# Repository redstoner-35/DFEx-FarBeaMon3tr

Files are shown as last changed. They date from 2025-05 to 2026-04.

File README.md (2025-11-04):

powered by 35's Embedded Systems Inc. An Open-Source High Power FlashLight Solution                                                                                                                        

### 概述

欢迎来到由Redstoner_35所开发的新一代高功率全恒流远射/远泛手电**DFEX-FarBeaMon3tr**的完整设计开源仓库。DFEX-FarBeaMon3tr是基于XTR HyperBoost超高能效升压恒流驱动所实现的大型手电参考设计，该手电采用全铝合金CNC设计，内置6节21700的可换电池电池架。电池架具备保护板、主动均衡和被动均衡确保使用安全，同时利用定制版本的充电系统支持高达140W输入功率的快速充电，缩短了极亮完毕后的补能时间。利用了全新的高功率双相交错升压恒流平台，该手电可实现高达760W的极亮功率。并且通过夜巡者7175灯珠得到72000lm 0.8M CD(或者使用定制的FL7018I灯珠得到75000LM 120万CD)的出光性能。同时无风条件下可实现6000-7000lm的恒流持续常亮，或在配合高功率风扇手柄的条件下以18000LM的亮度恒流持续常亮，直到电池电量用尽。该手电方案基于本人完全自主设计的硬件平台和软件系统，故具有超越市面上量产产品的极致性能以及稳定性，同时借助定制的软件系统可以实现市面上量产手电无法企及的高度可定制性和丰富功能。

### 复刻成本

该手电方案的从0开始复刻的成本极高。因此作者本人开源该项目的初衷是提供一个具有用户可换电池+大功率快充+全恒流超高能效驱动的手电设计参考作为抛砖引玉，期望行业上可以基于该设计作为范本诞生更多具有设计感和独创性的大型手电设计。如果您一定需要尝试复刻，那1PCS大致的复刻成本如下：

+ 机械部件部分：大约3000至4000元
+ 光学系统部分（包括反射器、玻璃等）：约2000元
+ 电子电路部分（包含驱动和电池架所有PCB和元器件）：约4000元
+ LED部分（包含定制灯珠打样和配套铜基板等）：7000元

### 性能数据

+ 远泛版本（使用6颗夜巡者7175灯珠）：极限72000LM光通量，约80万坎德拉
+ PRO9高功率高密度远泛版本（使用自己的DFEx-SuperLED+ FL7018I灯珠）极限75000LM光通量，约120万坎德拉
+ 远射版本（使用自己的DFEx-SuperLED+ FV7212D）极限43000LM光通量，约160万坎德拉

*注：以上测量数据由本人使用参考手电按照ANSI NEMA/FL1标准测试得到。受限于复刻时的物料使用，性能可能达不到标称值*

### 成品手电图片和尺寸

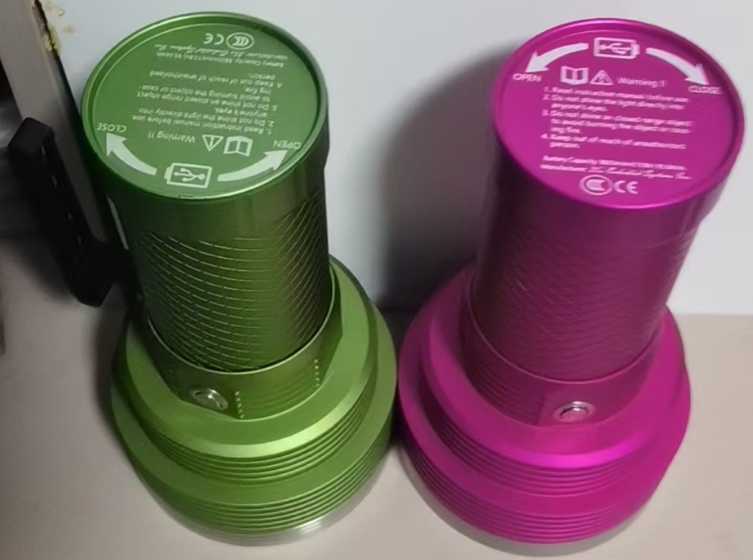
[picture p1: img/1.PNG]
俯视图

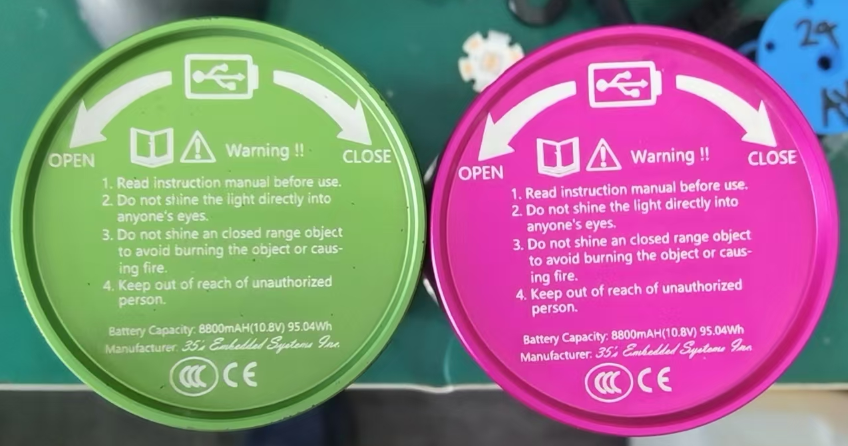
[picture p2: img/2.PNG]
侧视图


这个手电属于尺寸比较大，重量较高的类型。因此建议复刻时考虑清楚您是否能接受这种重型专业手电的重量和体积。详细的重量和体积数据如下：

+ 手电头径：125mm
+ 手电总长度：225mm
+ 电池仓直径：70mm
+ 手电总重量：2250克（包含6节比克INR21700-45D 4.5AH全极耳21700动力电芯）

同时该手电的侧面具备专用固定孔位用于兼容风扇手柄总成DLC。加上风扇手柄总成DLC后的外观图如下所示：

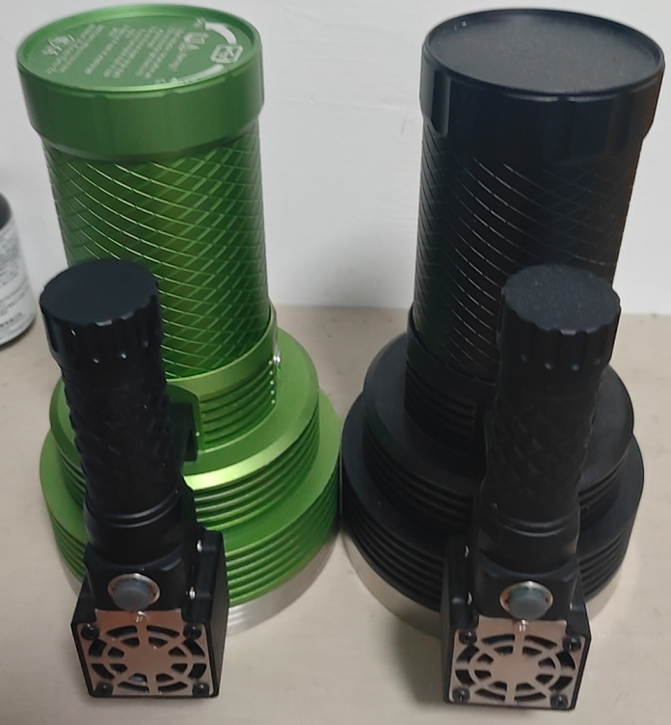
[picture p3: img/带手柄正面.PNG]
带手柄正面

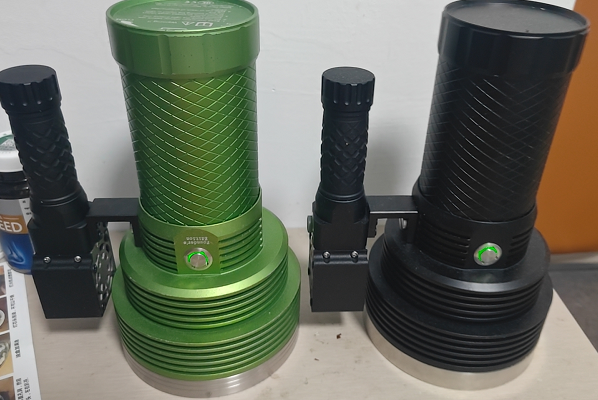
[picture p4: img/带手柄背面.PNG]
带手柄背面


此时手电的重量将会由原来的2250克增加至2535克（约2.5公斤）对于大部分人来说仍然能接受。不过考虑到复刻的极高成本，还是建议用户审慎考虑是否能接受一款重达5斤的重型手电。

### 续航数据

#### 极亮、高亮和中高亮以及中亮的续航

使用6节比克INR21700-45D（共计95Wh）在25度室温，0.3M/s风速模拟室外微风 **（测试时高功率风扇手柄DLC还未做好，此时使用的是外置USB小风扇）** 的情况下，极亮、高亮中高亮以及中亮的续航数据可以参考如下内容：

+ 极亮：30秒(满功率)+41分钟(极亮降档后外壳58度恒温恒亮)+15分钟(降档至高亮外壳50度恒温恒亮)+32.5分钟（逐步降档至极低亮）总共90分钟 *约1.5小时*
+ 高亮：11分钟（满功率）+33分钟（逐步降档至中亮开始恒温50度常亮）+ 33分钟（中亮持续恒温恒亮）+34.5分钟（逐步降档至极低亮）总共106.5分钟 *约1.78小时*
+ 中高亮：84分钟（持续恒流常亮）+34分钟（逐步降档至极低亮）总共118分钟 *约1.96小时*
+ 中亮：172.5分钟（持续恒流常亮）30.5分钟（逐步降档至极低亮）总共203分钟 *约3.38小时*

曲线可以参考如下表：

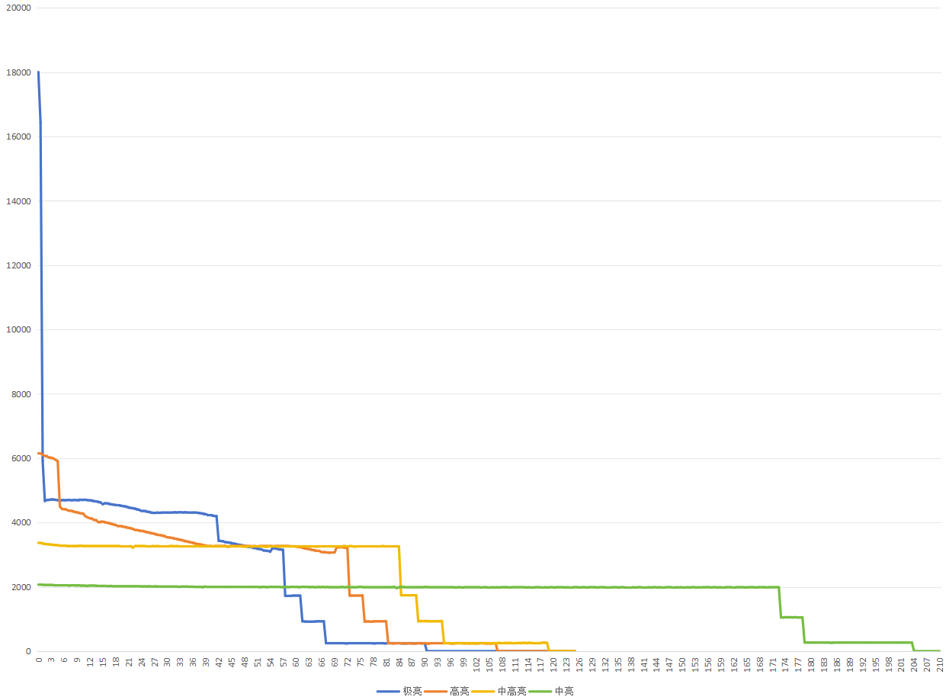
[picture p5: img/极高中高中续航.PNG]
续航表1


#### 低亮和极低亮的续航

使用6节比克INR21700-45D（共计95Wh）在25度室温，0.3M/s风速模拟室外微风的情况下，低亮和极低亮的续航如下：

+ 低亮：343.5分钟（低亮常亮）+27分钟（降档至极低亮）总共6.175小时
+ 极低亮：1419分钟（23.65小时）

曲线可以参考如下表：

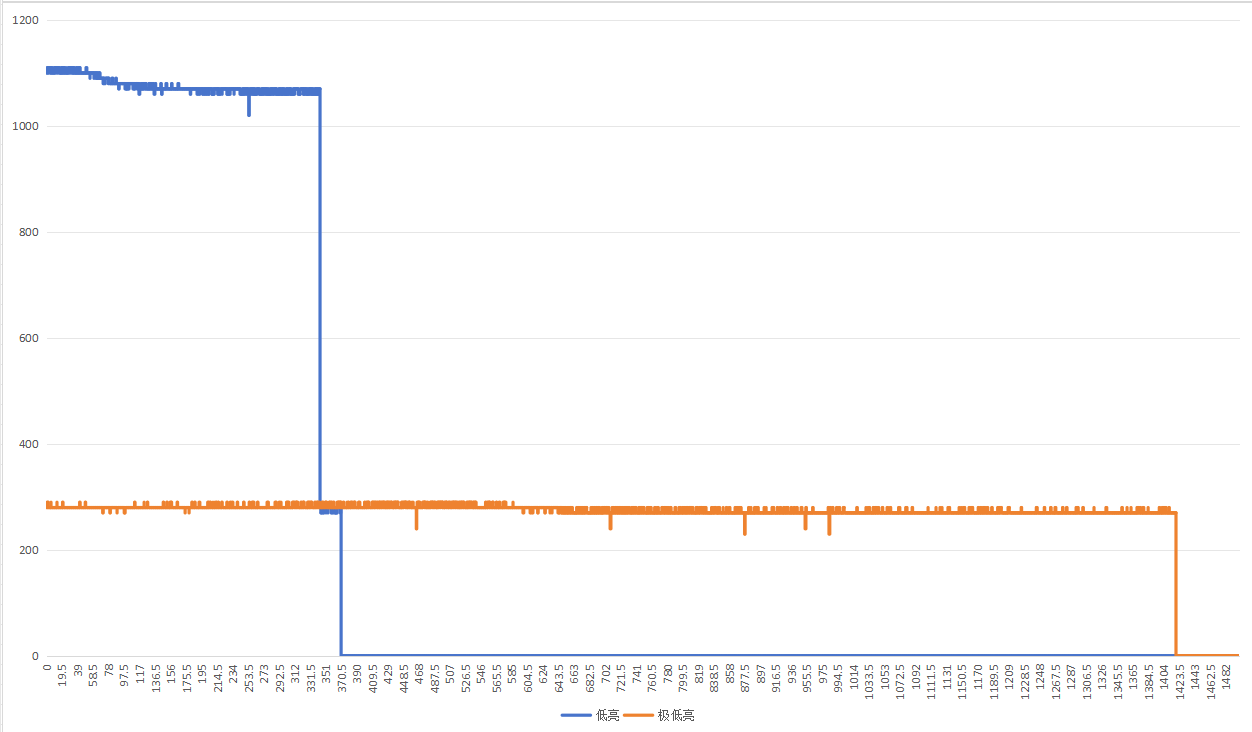
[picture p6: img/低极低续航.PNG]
续航表2


#### 月光挡位和超级省电挡位的续航

使用6节比克INR21700-45D（共计95Wh）在25度室温，0.3M/s风速模拟室外微风的情况下，月光和超级省电挡位续航数据如下：

+ 月光挡位（165LM）：续航大约90小时。
+ 超级省电挡位（2.5LM，运行至保护板彻底断电）：1760小时，约73.3天

#### 极亮温控降档曲线

实测的极亮温控降档曲线如下所示。测试条件和续航测试一致，照度测试系统采用1S采样周期，测试结果如下：

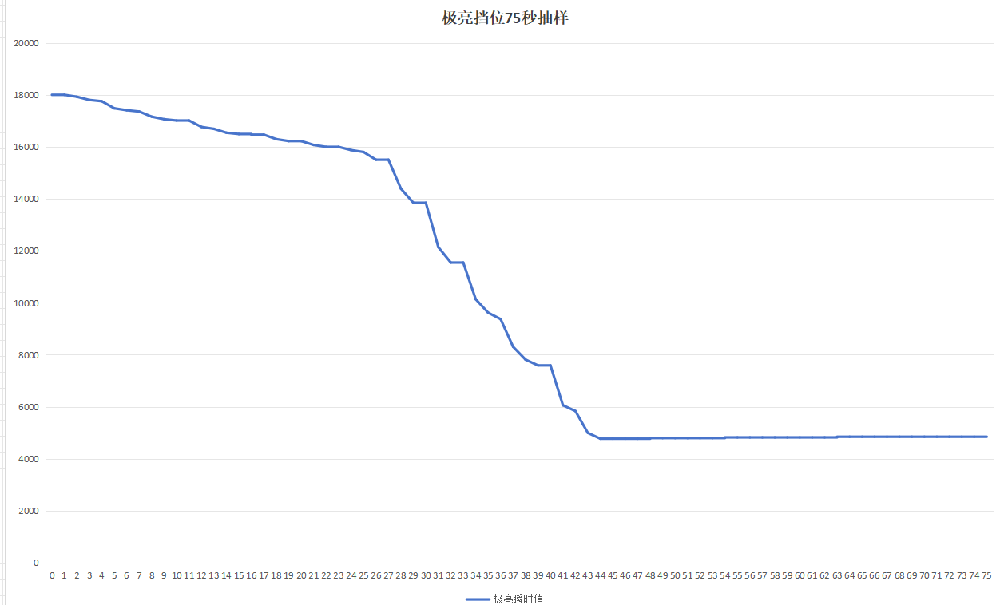
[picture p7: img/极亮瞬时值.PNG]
极亮数据


使用36A极亮的高功率版本程序搭配6颗N7-175HE时，极亮功率可达760W并在此条件下恒流顶满最大功率坚持30秒。30秒后温控介入开始迅速减低输出功率并进入续航曲线的恒温恒亮阶段。对于如此大的极亮功率是一个很优秀的水平。**需要注意的是，LUX值的轻微下跌是由于外壳温度提升后灯珠结温上升导致光效降低导致。并非驱动无法实现恒流极亮。**

### 复刻时电池的选择

这个手电的电池在工作过程中需要承受巨大的电流。对于使用7175灯珠和36A电流配置的远泛版本，电池电流可能会高达80A，也就是每节电池需要提供40A的电流。如此巨大的电流基本不允许使用非全极耳的动力电芯。经过测试，我建议使用如下的电芯：

+ 天鹏能源50XG：目前最强的5000容量全极耳电芯。正A品价格22-30之间。不管是充电还是放电水平都属于业界T0梯队，强烈推荐！ **但是需要注意不要买到早期测试报废品（正A品的电池皮是灰色的）测试报废品会漏电导致电池架工作异常！**
+ 瑞恩RS50：5000挡位全极耳电芯。A品价格大概20-25一节。该电芯充放电性能较为均衡属于兼顾容量和性能的动力电芯，在50XG出来后倒是不推荐了。
+ 比克INA21700-45D：高容量动力电芯。价格较贵约27一节，4500mA容量可以换来较长的续航。购买时建议选择A03高容品并特挑2.9毫欧内阻。
+ 新能安JP40：中等容量动力电芯，优势是货源数量极大因此价格很便宜，全新约15-20元一节。**需要注意的是，由于电池架的结构设计，拆机电芯因为电极表面不平整会导致电池架接触不良出现极亮瞬间保护等问题。因此不建议购买拆机的电芯。**
+ 三杰40Y：2025年三杰新推出的全极耳电芯，零售大概在20-25一节。性能相比前两者比较差，不推到700W以上问题不大。

可以用但是因为容易买到不好品质而不推荐的电芯：

+ 亿纬40PL：放电能力等于新能安JP40但是容易买到刮码降级B品，B品一致性差而且存在漏电问题，会导致手电工作异常。
+ 亿纬50PL：目前最强放电能力，且具有5000mAh的高容量。但是这款电芯目前产能和良率存在问题导致正A品一票难求。市场上目前只有降级刮码B品，一致性差而且存在单体漏电可能，会导致手电异常。

**注意：因为该手电极高的充放电倍率，绝对不要使用容量型或者半动力型电芯，是真的会爆炸！非要强行使用炸了后果自负，作者不承担任何责任！**

### 风扇手柄DLC的说明

#### 风扇手柄参数简介

相比于最初的版本，目前的工程文件已经包含了基于[东东海F1A的风扇手柄套件](https://item.taobao.com/item.htm?id=962803427853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)所实现的风扇手柄DLC。该风扇手柄通过专用的铝合金固定件连接至手电本体，具有极高的强度。风扇手柄外观如下图所示：

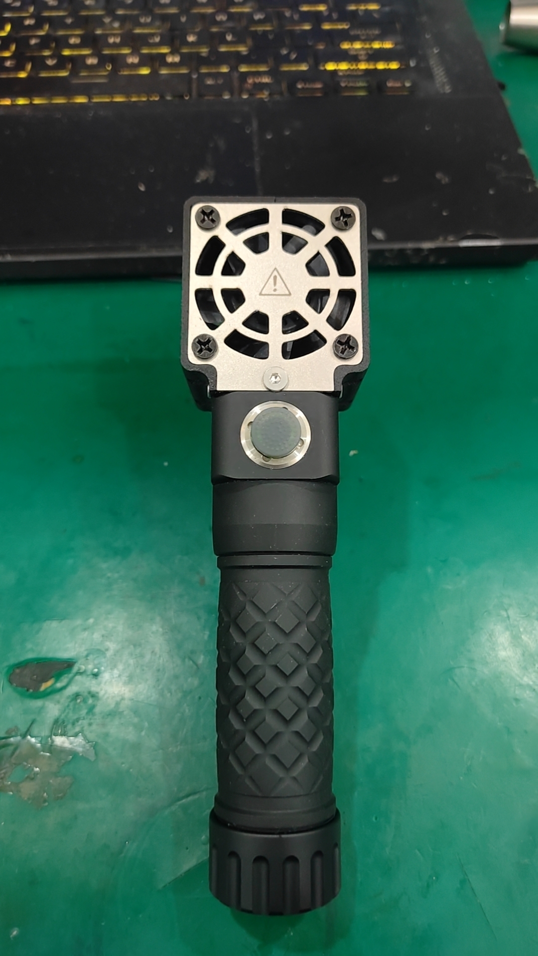
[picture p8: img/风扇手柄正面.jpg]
风扇手柄正面

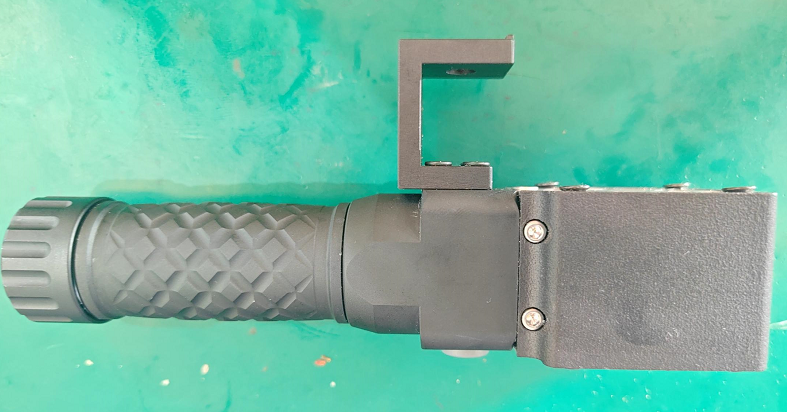
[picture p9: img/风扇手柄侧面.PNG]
风扇手柄侧面


该风扇手柄DLC基于自主开发的单锂升压12V风扇专用驱动以及单锂双向充电板，手柄样机所标配的风扇为建准的XF40281BX-Q035-S9H。转速高达34000RPM可以实现2万LM常亮不降档。同时该风扇手柄的电池仓为免拆电池充电设计，旋下电池仓即可露出内置的双向USB-TypeC充电接口：

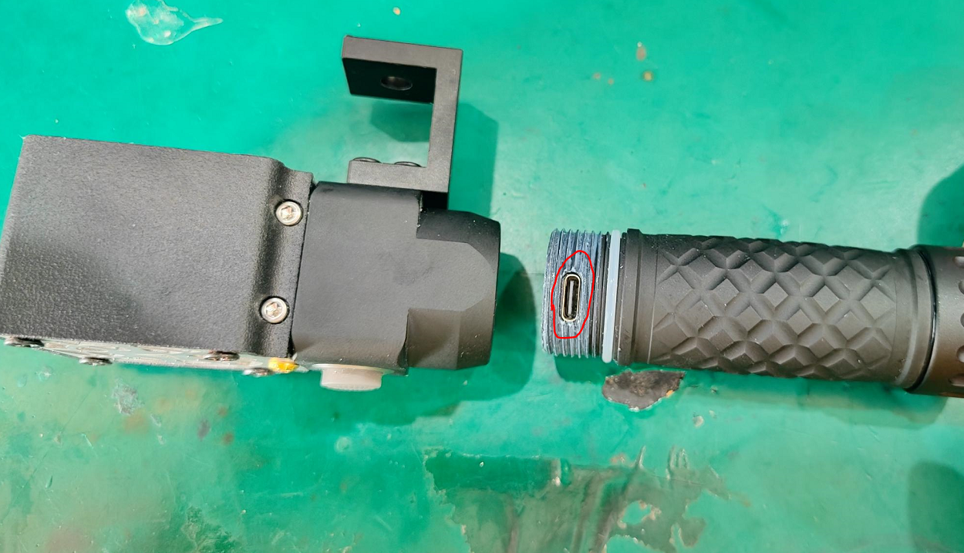
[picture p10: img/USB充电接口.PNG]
USB充电接口


该充电接口支持双向5V 2.4A充放电。最高12W的输入或输出功率。除了能给风扇手柄充电以外在应急情况下还可以反向为手机或其他设备应急充电。拆下手柄后即可看到手柄电池仓正面的充放指示灯：

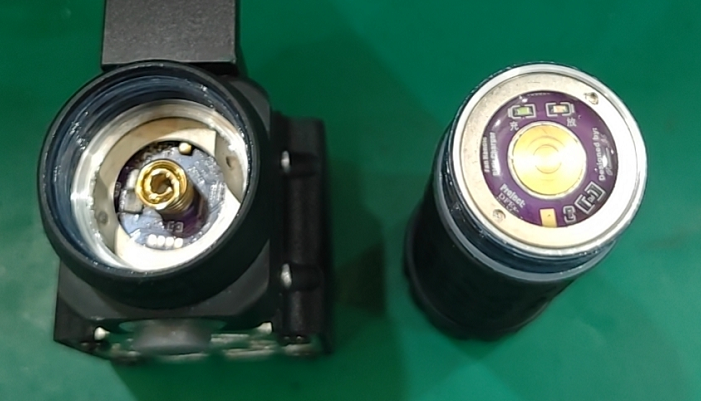
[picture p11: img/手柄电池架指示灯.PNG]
正面指示灯位置


手柄的电池仓一共包含两个指示灯，其中一个为放电和电池电量指示灯（图中紫色并且以放字标识的LED）以及一个充电状态指示灯（图中黄色以充字标识）负责指示电池的充放电状态。当电池仓首次装入电池时，电量指示灯会1Hz慢闪四秒表示电池安装后系统处于激活锁定模式。此时C口不能对外放电，需要连接充电器充电后才可放电。这两个指示灯不会同时点亮，显示的逻辑如下：

+ 充电指示灯：正在充电时0.5Hz慢闪，充满后持续点亮
+ 放电和电量指示灯：正在放电且电量正常时常亮，正在放电且电量不足后1Hz慢闪（充电或者放电结束拔下线缆后，电量指示灯仍然会保持点亮或闪烁一段时间，用户无需理会。30秒后电量指示灯会自然熄灭）

该风扇手柄采用专门的操作逻辑设计，和手电的原始UI基本一致，操作逻辑请参考如下内容：

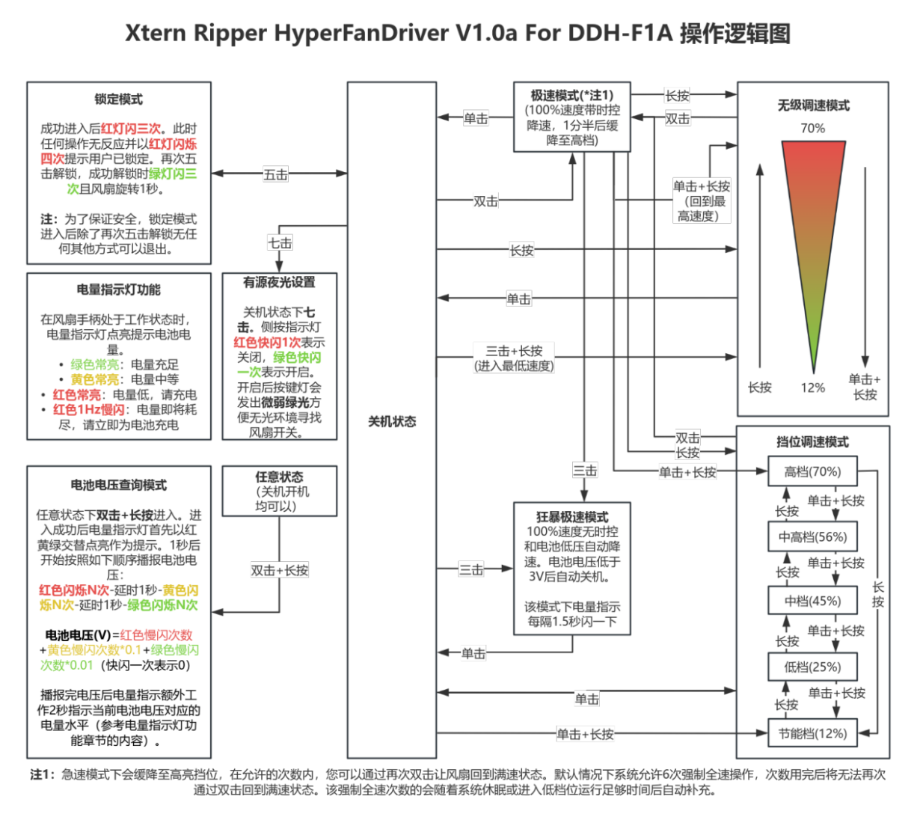
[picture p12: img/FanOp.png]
风扇手柄操作


#### 风扇手柄复刻说明

该风扇手柄复刻所需要的电路和机械部分已经在工程文件中体现，用户可以根据需要自行准备物料并复刻。对于部分未说明的物料请参考如下内容：

+ 风扇手柄半成品：该配件由东东海销售，可在[东东海淘宝店](https://item.taobao.com/item.htm?id=962803427853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)购买。
+ 风扇本体固定用粗牙螺丝：KB4*10规格，可在[固恒紧固件天猫店](https://detail.tmall.com/item.htm?id=610787499293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)购买.
+ 风扇固定装饰外壳和手柄壳料的固定螺丝：定制M3*6头径4.5非标内六角螺丝，可在[深奥普淘宝店](https://item.taobao.com/item.htm?id=770645615127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)购买
+ 4028暴力风扇：作者推荐使用建准的XF40281BX-Q035-S9H超高速暴力风扇获得足够的风量。该风扇可在[小红散热风扇](https://item.taobao.com/item.htm?id=959825954576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)淘宝店购买。

对于其余的机械部分物料，则参考如下说明：

+ 正背面风扇网罩不锈钢片：参考机械部分的[3D模型](/%E6%9C%BA%E6%A2%B0/%E9%A3%8E%E6%89%87%E6%89%8B%E6%9F%84%E5%A4%96%E6%A1%86/Step/40%E9%A3%8E%E6%89%87%E4%B8%8D%E9%94%88%E9%92%A2%E5%A4%B9%E7%89%87-%E6%94%B9%E7%89%88.STEP)找不锈钢加工厂进行处理。使用1mm 304不锈钢片激光切割后去毛刺抛光，并喷砂处理。
+ 风扇和手柄之间的固定壳：参考机械部分的[外部固定壳模型](/%E6%9C%BA%E6%A2%B0/%E9%A3%8E%E6%89%87%E6%89%8B%E6%9F%84%E5%A4%96%E6%A1%86/Step/40%E9%A3%8E%E6%89%87%E5%A4%96%E6%A1%8623%E6%97%A5.STEP)找3D打印商家进行处理。因该部件型面较为复杂因此建议选用PA6材质进行SLS激光烧结或MJF工艺等无需支撑的工艺制程进行3D打印。

电子部分的物料和具体打样文件（如PCB等）您可以参考PCB文件夹内相关的子目录并进行打样。

### 工程结构

该开源手电项目的工程分为三个文件夹，分别放置手电的电子、机械和固件部分的原始资料：

+ PCB：该文件夹放置手电所有功能模块的电路板文件
+ 固件：该文件夹放置手电种各个功能模块所使用到的固件文件
+ 机械：该文件夹放置手电外壳、电池架等东西的机械建模文件

### 复刻的详细指导

因为该项目仍处于刚刚完成的状态，相关文档的编写仍在进行中。对于需要注意的部分以及供应商链接您可以参考每个子文件夹内的注意事项文档。对于您在复刻中不明白的部分，您可使用Github issue。

----------------------------------------------------------------------------------------------------------------------------------
© redstoner_35 @ 35's Embedded Systems Inc.  2025

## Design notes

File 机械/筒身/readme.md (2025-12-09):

### 关于文件格式的说明

这里所提供的3D文件格式为UG NX的部件格式。为了方便复刻联系五金供应商进行报价故作者还提供了每个部件所对应的Step文件。**需要特别注意的是，Step文件仅供报价参考，不得作为最终加工的特征基准！**对于最终的加工尺寸基准，请按照UG NX的原文件进行处理。

### 关于材料的选择

该手电的外壳在设计时是按照**6061T6铝合金**进行设计的。考虑到导热性、材料硬度等因素，不建议使用其他材料进行制造。

### 关于文件内尺寸的说明

需要注意的是这里的3D文件内的尺寸并未按照配合关系进行完全的优化。因此加工时一定要和老板沟通清楚相关螺纹以及五金件的配合参数。否则加工出来的将会是废品！作者建议所有的五金件在加工时均由同一家供应商进行，并且配合件的公差参数由他们按照自身设备的匹配情况进行把控，这样可以避免多家供应商的配合尺寸基准不一致导致最后无法装配的问题。

### 关于驱动压环螺纹的说明

驱动压环的原始资料文件中的螺纹和实际参数并不匹配。实际加工时建议按照如下参数加工：

#### 驱动压环外螺纹参数

+ 螺距：1.0mm
+ 螺纹类型：公制M54
+ 螺纹大径：54mm
+ 螺纹小径：52.6mm

对于筒身外螺纹的配合参数，为了确保驱动压环能够顺畅拧入且不会松动，可以按照单边0.2至0.3mm的间隙预留，不建议间隙过小。

### 密封圈选配说明

为了使手电达到应有的防水性能，您需要在筒头、玻璃、筒身等位置预留的密封圈槽位置正确安装密封圈方可达到防水性能。该手电对于密封圈的品牌没有要求，只要材质和尺寸正确即可。密封圈数据请参考如下：

+ 玻璃压环密封圈（位于玻璃和不锈钢玻璃压环之间）：外径120mm，线经2.0mm
+ 筒头-玻璃压环密封圈（位于筒头，负责实现玻璃压环和筒身之间的密封）：外径110mm，线经1.5mm
+ 尾盖密封圈（实现电池筒身和尾盖之间的密封）：外径43.7mm，线经1.8mm *实际安装在筒身上拉伸之后尺寸正好合适*
+ 筒头-筒身密封圈（装载电池筒前部实现筒头和筒身之间的密封）：外径41.2mm 线经1.8mm *实际安装在筒身上拉伸之后尺寸正好合适* 

**所有密封圈材质均为硅胶，白硅胶和红硅胶均可。请勿使用橡胶材质如氟橡胶、EPDM，否则密封圈可能会因过大应力而破损**

### 二次加工的说明

为了实现正确的导电连接，因此筒头部分在阳极氧化结束后需要再次上级进行二次加工去除氧化层。去除的数据请参考如下：

#### 基板安装位去氧化

筒头的基板位置在一次加工时请按照3D图的尺寸进行加工。加工氧化好后的效果如图：
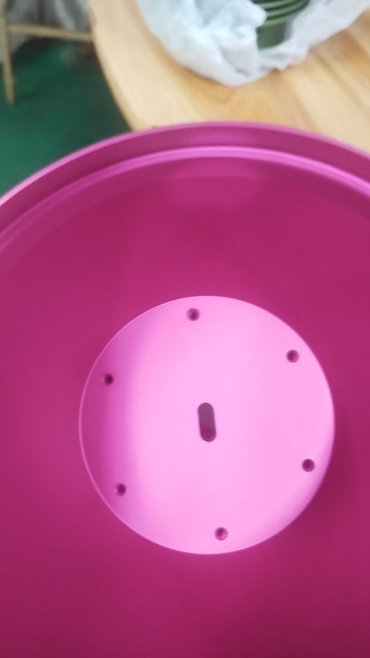
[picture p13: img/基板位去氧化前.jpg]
筒头去氧化前


去氧化时请使用车床对整个基板安装位光一刀，深度0.1mm即可，光一刀后尺寸正好合适。

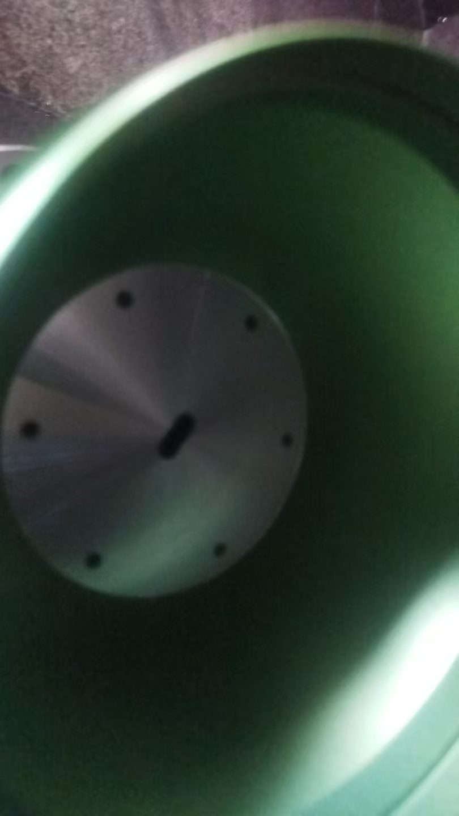
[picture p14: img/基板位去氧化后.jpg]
筒头去氧化后


#### 驱动安装位去氧化

驱动安装位置的去氧化操作则较为复杂。驱动压环位置的螺纹，驱动PCB所在的台阶以及电池仓前盖所对应的压环均要去氧化。因此加工协商过程中需要让老板留好余量。去氧化前的效果如下：

基板位去氧化前

去氧化后效果如下：

基板位去氧化后

----------------------------------------------------------------------------------------------------------------------------------
© redstoner_35 @ 35's Embedded Systems Inc.  2025

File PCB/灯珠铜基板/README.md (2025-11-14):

### 铜基板配置说明

这个手电默认的铜基板配置是6颗7070或者7272尺寸的LED。对于LED的电压配置则支持3种类型的灯珠。对于目前基板已有的3种配置请参考下面的内容：

### 6V灯珠

第1种默认的配置是6V灯珠以3串2并的形式连接到驱动。三串6V灯珠提供了15-22V的宽范围Vf以适配驱动的输出参数。对于6V灯珠配置，为了确保安全使用应确保灯珠至少能承受16A电流，否则灯珠会烧毁。6V基板配置采用了4.0mm热焊盘的行业标准XHP70的灯珠焊盘设计因此可以兼容XHP70.3等灯珠。

### 9V灯珠

第2种默认的配置则是9V灯珠以2串3并的形式连接到驱动，这种形式适用于9核心的倒装高光效灯珠用于远泛光型的装机。对于9V灯珠配置，为了确保安全使用应确保灯珠至少能承受12A电流，否则灯珠会烧毁。
需要特别注意的是，9V基板配置使用了兼容达立半导体A6-N60灯珠（夜巡者老王7175）的焊盘设计。该焊盘加大了热焊盘位置以增强导热能力适配大核心面积。**如果强行焊接行业标准的7070灯珠（热焊盘0.2mm）会导致灯珠短路而无法使用！！！**

### 3V灯珠（2025年11月更新）

第三种默认配置针对改进款的7070 NBT160.3灯珠。采用3V灯珠6串全串联设计。这种设计彻底解决了并联灯珠带来的可能不均流的问题。为了确保核心散热完全，3V基板的设计采用了加大热焊盘位置的非标准7070封装以增强导热能力适配大核心面积。**如果强行焊接行业标准的7070灯珠（热焊盘4.0mm）会导致灯珠短路而无法使用！！！** 文件中提供了单板的PCB源文件，需要和基板厂协商让他们负责代客拼板才能生产。

### 基板打样参数

该手电对基板的配置有特殊要求，因此打样时需要联系专职进行铜基板打样的厂家（例如深圳天华电子有限公司等）进行打样。打样的参数要求如下所示：

+ 成品板厚：2.5mm
+ 线路层铜厚：4Oz
+ 焊盘喷镀：2U沉金
+ 特殊工艺要求：六个固定孔需要做阶梯孔。阶梯孔截面宽度6.2mm，深度1.2mm。
+ 分板方式：V-Cut分板

本文件提供的成品拼板文件已经默认拼好两种不同配置的基板，并附加上工艺边和V-Cut线，可以支持直接打样无需进行二次处理。对于该铜基板的打样参考价格大概是1500CNY打样费可以做3个set（一个set包含6V配置和9V配置的铜基板各一块），一共可以得到6个铜基板。

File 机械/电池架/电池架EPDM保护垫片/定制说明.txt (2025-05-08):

所提供的图纸为1：1尺寸的DWG格式无需缩放。请按照如下参数裁切：

+ 材料厚度：1mm
+ 材料材质：EPDM(三元乙丙橡胶)

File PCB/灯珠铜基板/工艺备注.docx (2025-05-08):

该铜基板需要做台阶孔。台阶孔截面图和参数如下：

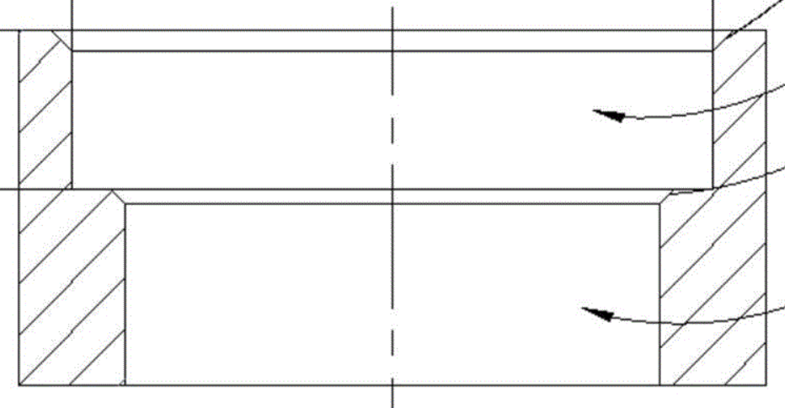
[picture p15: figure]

总深度

台阶深度

台阶部分深度：1.2mm

孔总深度：2.5mm(钻透整个基板)

台阶孔部分的外形尺寸，由文件“铜基板拼板_Mechanical_6.gbr”描述，其余外形和台阶孔非台阶部分（见截面图红色箭头标注）的尺寸由文件“铜基板拼板_Keep-out.gbr”描述。

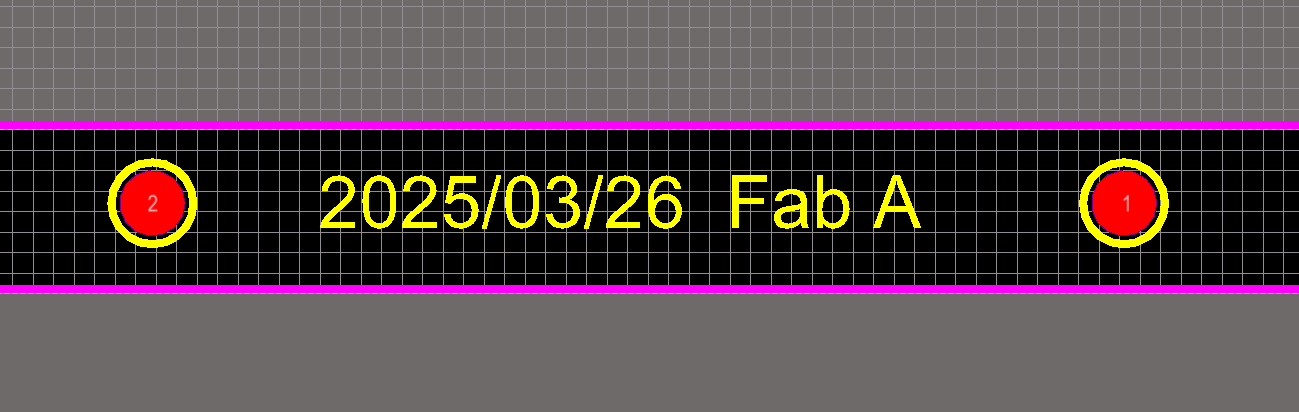
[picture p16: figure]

文件下方左右两侧的焊盘和外圈丝印圆圈为丝印印刷时对齐用的MARK标记。请生产员工在生产时利用此标记，尽量确保丝印对齐。

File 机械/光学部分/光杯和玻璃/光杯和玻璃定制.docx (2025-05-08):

# 玻璃定制

为了达到最大透光率以获得最高流明值输出，建议在淘宝上定制专门的双面镀膜AR钢化玻璃。对于玻璃的供应商我推荐淘宝的【首页-古洛玻璃-淘宝网 (https://shop33401513.taobao.com/)】按照所需的规格定制的报价是一片300RMB。玻璃的规格如下表所示：

玻璃基材 | 超白光学玻璃
镀膜类型 | 绿色AR减反射膜（需要注意的是膜层颜色，紫色和蓝色会导致出光色温贬低变得更绿）
镀膜方式 | 双面镀膜（透光率要求达到98%以上）
玻璃形状 | 圆形
玻璃直径 | 118mm
玻璃厚度 | 4mm
边缘工艺 | 磨砂+保护性倒角避免刮伤手

# 光杯定制

该手电的光杯为铝合金材质，采用五轴CNC+光面电镀。对于光杯的定制您可以联系1688的这两家供应商：宏广照明 (https://hghlightingcn.1688.com/page/index.html?spm=0.0.wp_pc_common_header_companyName_undefined.0) 以及 东莞旺达精密五金有限公司 (https://www.1688.com/factory/b2b-22144382303900e311.html) 并提供工程中的反光杯外形3D文件进行定制。定制费用大约在1000至2000人民币。每次定制通常会提供6-10个光杯供您测试出光效果。

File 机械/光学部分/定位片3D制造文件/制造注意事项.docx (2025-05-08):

本设计中的定位片制造可以采用3D打印。3D打印的话需要使用耐温大于160度，且颜色为白色的高热变形温度工程耗材，建议使用例如PA6-GF等高耐温工程耗材进行打印。作者所使用的打印参数如下：

耗材 | 拓竹原装白色PA6-GF玻纤增强耗材
打印机 | 拓竹X1C+AMS换料系统
热床温度 | 110℃
喷嘴温度 | 275℃
打印顺序 | 逐件打印
打印预设参数 | 0.08mm Extra Fine @ BBL X1C
填充率 | 100%

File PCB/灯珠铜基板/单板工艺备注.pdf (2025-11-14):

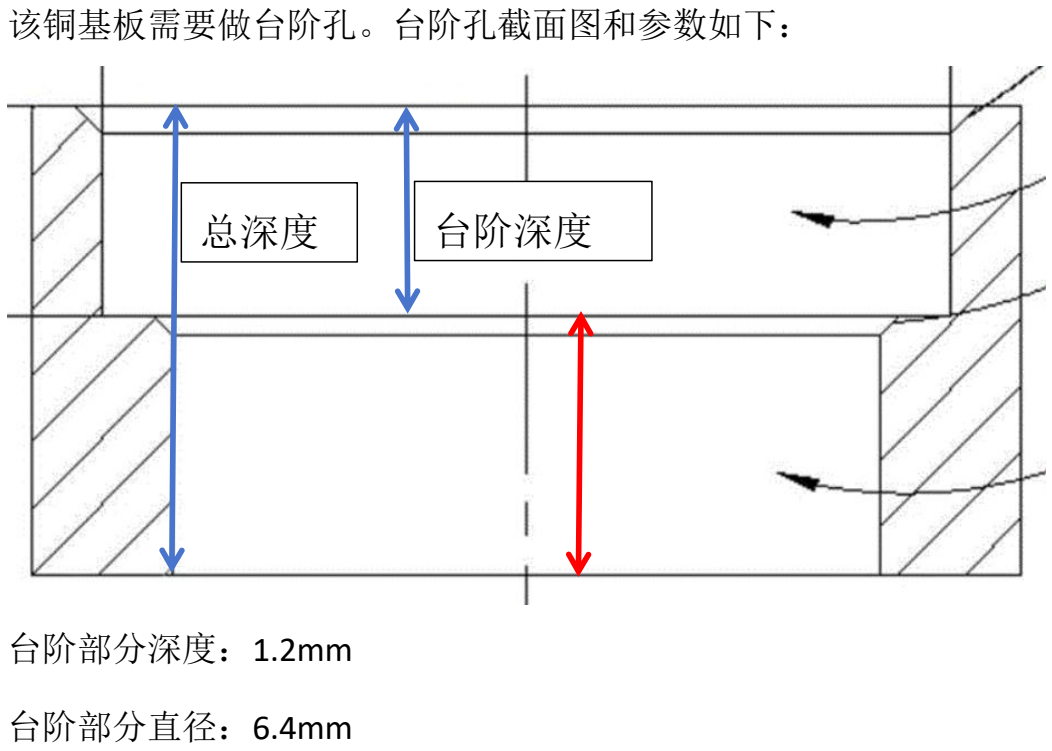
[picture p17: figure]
该铜基板需要做台阶孔。台阶孔截面图和参数如下：; 台阶部分深度：1.2mm; 台阶部分直径：6.4mm; 总深度; 台阶深度

孔总深度：2.5mm(钻透整个基板)

台阶孔部分的外形尺寸，由文件“铜基板拼板_Mechanical_1.gbr”描

述，其余外形和台阶孔非台阶部分（见截面图红色箭头标注）的尺寸

由文件“铜基板拼板_Keep-out.gbr”描述。

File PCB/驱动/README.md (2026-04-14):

powered by 35's Embedded Systems Inc. A Next generation FlashLight Driver Solution                                                                                                                        

### 概述

Xtern Ripper Lite-HyperBoost是用于DFEx-FarBeaMon3tr的超大功率且高能效的升压恒流驱动器。该驱动器基于全新的FlashLightOS Entry e-Switch固件。在保证了基本手电所需的客制化功能的前提下，删减了一些高阶特性并使用更便宜的中微8051平台。
该驱动器基于私有的X47安装方式，虽然该驱动器并不建议配合东东海47mm D8B外壳使用，但是通过对驱动仓进行车削仍然可以正常安装。该驱动器基于全新的HyperBoost双相交错升压恒流平台，通过使用两个以180度相位角交错运行的boost转换器实现在极大输出功率下仍能高能效运行。

### 性能数据

+ 支持的电池输入类型：3S三元锂电池组，持续放电能力应大于100安培。
+ 支持的LED灯珠类型：3V灯珠6串、6V灯珠3串、9V灯珠2串（支持垂直核心灯珠高Vf运行，设计时应保证极亮时灯珠Vf不超过22.0V）
+ 支持的LED电流：30mA至32或36.00A
+ 温度保护：55度PI环自适应外壳恒温（温控启动后驱动根据外壳散热能力和环境自动调整亮度达到最高可实现的亮度）+65度极亮cutoff+80度强制关机
+ 电池保护：具有欠压自动降档和关机保护以及过电压保护
+ 电池过载保护：具备输入自动限流保护

### 调试指引

该驱动不需要任何硬件上的调试和标定操作，只需要按照BOM表焊接上元器件并刷写固件即可使用。如果出现功能异常，您可以参考[驱动故障排除指引](/FAQ.docx)对驱动进行故障排除。**需要注意的是，示例工程中LTC3787芯片的两个输入限流电阻（R1和R2）原理图中采用的是1mR，如果您打算让驱动输出高于32A的电流，则建议在该电阻上面额外叠放焊接一个R015电阻组成0.938mR，将输入峰值电流限制解锁到53A。这样可以增大驱动的输入电流上限以增大恒流区间**

### 总体操作逻辑

该驱动具备无极调光和传统挡位模式两种逻辑供用户自由选择：
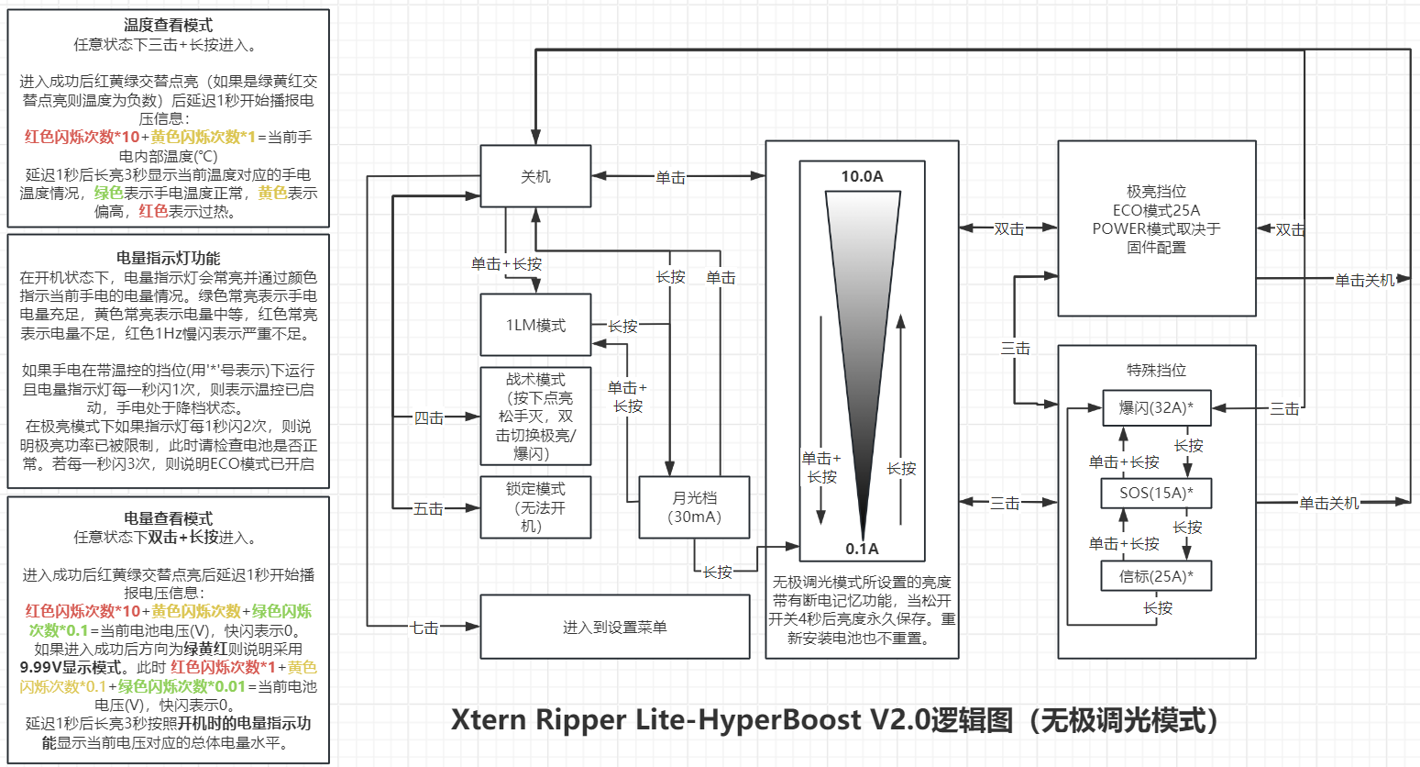
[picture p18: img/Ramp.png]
无极调光

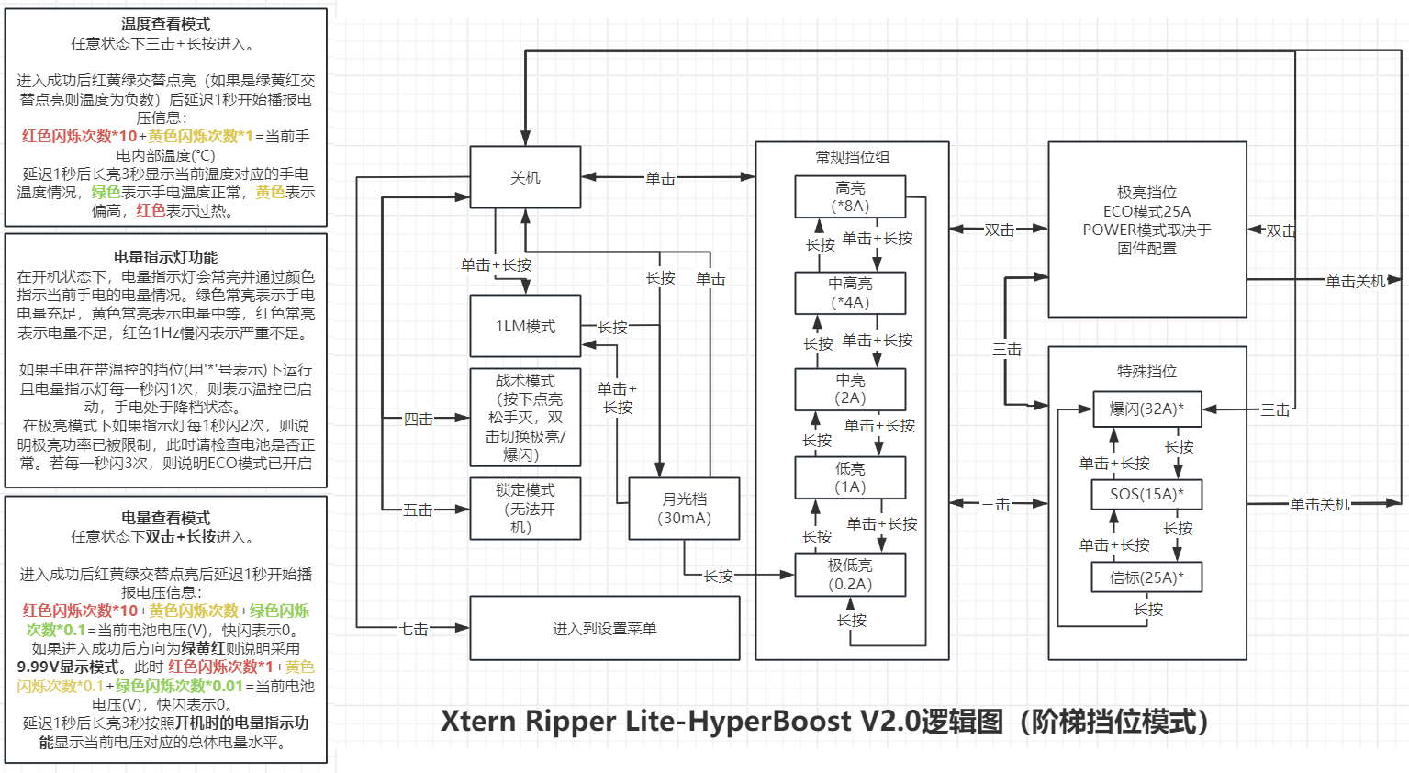
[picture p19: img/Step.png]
挡位模式


需要补充的是，图中的任意挡位均可以通过单击立即回到关闭状态。对于图中的部分未详尽解释的特殊逻辑，则可参考如下内容：

+ 固件编译时间戳查询：关机状态下8击进入。进入后手电主灯首先会点亮1秒，提示即将开始播报。然后手电将会按顺序播报固件编译的年份、月份，日期以及编译时的时间（精确到分钟）。首先手电会播报固件编译的具体日期，播报会分为三组数字，每组数字之间停顿2.5秒，同一组数字之间会有1.5秒的间隔方便用户区分。在播报完第一到第三组数字所表示的手电编译固件编译的年份、月份，日期之后，手电将会停顿4.5秒然后开始播报固件编译的具体时间（精确到分钟）。具体编译时间的播报会分为两组数字，每组数字之间停顿2.5秒，同一组数字之间会有1.5秒的间隔方便用户区分。**需要注意的是，播报启动后就无法中断，在版本信息播报过程中，手电将不响应任何操作，直到播报结束。** 详细的播报规则如下：
 
  - 第一组数字：指示固件编译的年份。其中主灯慢速闪烁N次表示非零的数字，如果快速闪烁一次，则表示该数据位为0。两位数字之间系统会停顿1.5秒。例如`慢闪2次-停顿1.5秒-慢闪5次`表示固件编译的年份为**25（2025年）**。
  - 第二组数字：指示固件编译的月份。其中主灯慢速闪烁N次表示非零的数字，如果快速闪烁一次，则表示该数据位为0。两位数字之间系统会停顿1.5秒。例如`快闪1次-停顿1.5秒-慢闪6次`表示固件编译的月份为**06（6月）**。
  - 第三组数字：指示固件编译的具体日期（精确到天）。其中主灯慢速闪烁N次表示非零的数字，如果快速闪烁一次，则表示该数据位为0。两位数字之间系统会停顿1.5秒。例如`慢闪2次-停顿1.5秒-慢闪3次`表示固件编译的具体日期为**23日**。
  - 第四组数字：以24小时制度指示固件编译时间的小时部分。其中主灯慢速闪烁N次表示非零的数字，如果快速闪烁一次，则表示该数据位为0。两位数字之间系统会停顿1.5秒。例如`慢闪1次-停顿1.5秒-慢闪3次`表示固件编译的时间（小时）为**13时（下午1点）**。
  - 第五组数字：指示固件编译时间的分钟部分。其中主灯慢速闪烁N次表示非零的数字，如果快速闪烁一次，则表示该数据位为0。两位数字之间系统会停顿1.5秒。例如`慢闪4次-停顿1.5秒-慢闪6次`表示固件编译的时间（分钟）为**46分**。

+ 1LM超级省电应急档：关机状态下单击+长按进入。进入该挡位后侧按的电量指示灯由原来的常亮改为每10秒按照正常运行过程中的电量情况短暂点亮一次以节约电力消耗（如果电池电量极低，则为红灯慢速闪烁）。该挡位的流明值取决于灯珠性能和V/I特性，通常在*2-3LM*之间。该挡位下长按可以进入正常的月光挡。**需要注意的是，该挡位仅用于应急，故没有任何电池电量保护机制。只要电池还有电力就会无限运行直到电池输入低于7.2V时驱动断电。若搭配第三方出品，没有过放保护的电池包将会导致电池因为过放而永久性损坏！使用官方电池包则不会有这个问题。**
+ 走夜路模式：关机状态下四击或六击进入（取决于设置菜单内设置项8的配置），手电此时开启约1.1A的低亮用于正常照明。此时若对向有行人或来车，则单击+长按后手电将会暂时熄灭以避免强光晃到对面，松手后手电将重新点亮。如果长按，手电将开启和爆闪挡位功能等同的全功率一键爆闪用以压制对面进行致盲操作，松手后手电恢复正常照明状态。
+ 战术模式：关机状态下四击或者六击开关（取决于设置菜单内设置项8的配置），手电主灯迅速频闪一次表示进入战术模式。默认情况下战术功能为按下开关手电以极亮运行，松开则熄灭。当手电进入战术模式后，侧部按键将会每2秒快闪一次指示当前处于战术模式，此时手电将会保持唤醒，直到无操作10分钟后自动进入休眠并退出战术模式。如果您需要主动退出战术模式，则您可再度六击开关，手电主灯频闪一次指示退出战术模式。与此同时，您可以通过双击侧按切换战术模式的功能，切换后的指示如下：
  
  - 一键极亮模式（默认）：此时手电按下开关极亮，松开灭，侧按指示灯每2秒闪1次，切换到该模式时手电的侧按会用红色快闪3次做提示。
  - 一键爆闪模式：此时手电按下开关进入爆闪，松开灭，侧按指示灯每2秒闪2次，切换到该模式时手电的侧按会用绿色快闪3次做提示。

+ 按键锁：关机状态下五击开关，手电主灯点亮0.5秒表示进入锁定模式，此时手电的绝大多数功能均被禁用以避免误触点亮引起事故。在锁定模式中，为了方便用户查询长时间放置的手电电量，用户可双击+长按进行电量查询操作（如下方电量查询模式功能所示）。若用户有紧急照明需求，则可以单击+长按打开紧急月光照明。打开月光照明后用户可单击关闭。同时该月光照明具有超时以及电量保护功能，若用户在开启后30秒内无操作或手电电池电量过低，则手电将会自动关机。在电池电量充足的条件下，您可以通过双击+长按并保持一直按住的方式持续照明。
+ 温度查询模式：手电任意状态下三击+长按进入。当进入电量查询模式后手电的颈部开关指示灯首先将会以红黄绿依次点亮的方式（**若手电当前处于极寒环境，手电本身温度低于0摄氏度时，先导提示将变为绿黄红的顺序**）作为先导提示，提示用户手电即将开始显示手电当前的内部温度。延迟1秒后手电将通过红色和黄色的指定次数的慢速闪烁（如果快速闪烁一次，则表示该数据位为0）提示用户当前的手电温度。在播报完当前手电的内部温度数值后，手电将会在延迟2秒后通过后续的长亮(或者慢闪)提示用户当前内部温度数值所对应的手电散热情况。对于温度显示的计算方式请参考如下内容：

  - 播报完毕后绿色常亮：当前手电散热良好
  - 播报完毕后黄色常亮：当前手电温度较高，请注意防止烫手
  - 播报完毕后红色常亮：当前手电温度极高，请及时为手电散热并且避免被烫伤   
  - 手电温度(℃)=红色闪烁次数x10+黄色闪烁次数，例如`红色慢闪4次-黄色快闪1次`表示当前手电的内部温度为40℃

+ 查询电量：手电任意状态下通过双击+长按进入。当进入电量查询模式后手电的颈部开关指示灯首先将会以红黄绿依次点亮的方式（**若电池电压低于10.00V，则系统将会切换到高精度显示模式以0.01V精度显示电量。此时先导提示将变为绿黄红的顺序**）作为先导提示，提示用户手电即将开始显示电池电压和电量。延迟1秒后手电将通过红色，黄色和绿色的指定次数的慢速闪烁（如果快速闪烁一次，则表示该数据位为0）提示用户当前的电池电压，播报完电池当前电压后，手电将会在延迟2秒后通过后续的长亮(或者慢闪)提示用户当前电池电压对应的总体电量水平（指示方式参考下文中驱动位于正常工作时的指示），对于电池具体电压播报的计算方式请参考如下内容：
  
  -  99.9V显示模式：红色闪烁次数x10+黄色闪烁次数+绿色闪烁次数x0.1=当前电池电压(V)，例如`红色慢闪1次-黄色快闪1次-绿色慢闪4次`表示电池电压为10x1+0+4x0.1=10.4V。
  -  9.99V高精度显示模式：红色闪烁次数+黄色闪烁次数x0.1+绿色闪烁次数x0.01=当前电池电压(V)，例如`红色慢闪8次-黄色慢闪1次-绿色慢闪3次`表示电池电压为8+1*0.1+3x0.01=8.13V。

+ 恢复出厂设置：在手电处于完全断电状态下（用户可以通过卸下电池并反复多次按下手电侧按直到手电没有任何反应）持续按住按钮并扭上电池包令手电通电。此时手电的侧部按键指示灯将会以黄色的持续高频率快闪提示用户已恢复出厂设置。用户松开按键后，手电将会在2秒后自动重启并进入正常工作状态。

### 正常工作时的电量指示

对于电压指示，驱动在工作状态会通过指示灯点亮的方式提示用户当前系统的电池电量。与此同时，在手电首次装入电池时，驱动还会通过一次持续2秒的点亮提示电池电量（指示方式和工作状态时相同）。对于手电当前的电量状态和对应的指示灯状态请参考如下内容：

  - 绿色常亮：电池电量充足
  - 黄色常亮：电池电量较为充足
  - 红色常亮：电池电量不足，请尽快为手电充电
  - 红色慢闪：电池电量严重不足，请立即为手电充电（此时手电的可用挡位和功能将会被限制）

与此同时，在手电正常工作时，驱动还会再某些特定事件发生时通过一定时间内的短时间熄灭次数的循环指示驱动发生的事件，详细的事件列表如下：

  + 每2秒瞬时熄灭1次：手电温度过高，驱动已启用温控限制手电输出功率避免过热
  + 每2秒瞬时熄灭2次：驱动检测到电池子系统无法为极亮提供足够的能量，为了避免电池过载，极亮功率已被限制。（出现此提示请务必更换性能更强的电池）
  + 每2秒瞬时熄灭3次：驱动当前开启了夏季模式，极亮输出功率和温度控制策略将会被限制到更保守的级别。

### 设置菜单系统

该手电内置一个用于配置手电功能和特效的设置系统。当用户在手电关机状态下七击开关后，手电将会进入该设置菜单的设置项选择界面，此时用户可以通过单击选择要设置的菜单项，选择完毕后单击+长按进入，如果要退出设置菜单，则长按开关3秒后自动退出。设置菜单的操作请参考如下图片：
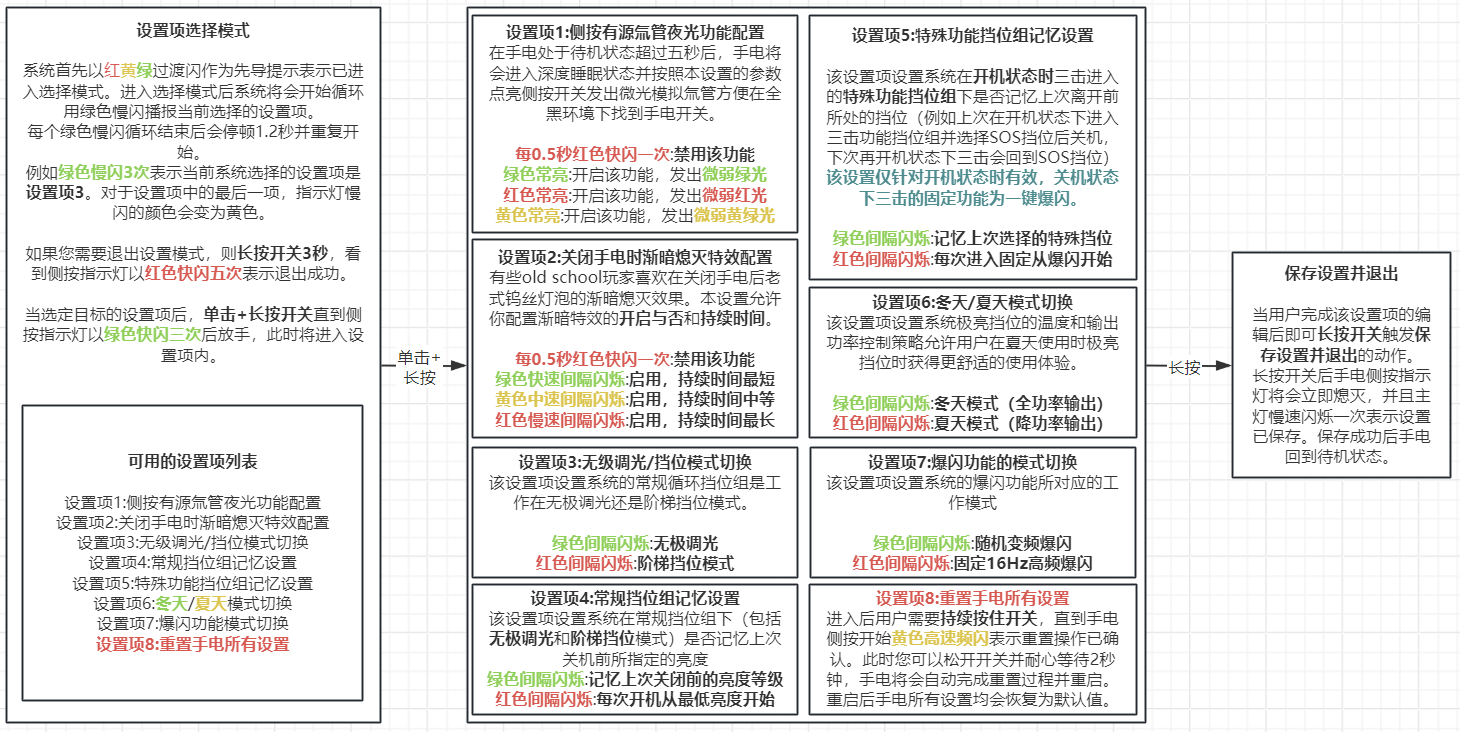
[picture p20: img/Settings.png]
设置菜单


*2025年12月26日热更新补充：*新增设置项8，允许用户根据自身使用习惯设置系统四击和6击的功能指配。选则该设置项时指示灯为8次闪烁。该设置项的功能如下：

+ 指示灯红色(默认模式)：此时战术模式被设置为高优先级，关机状态下四击进入战术模式，六击进入走夜路模式。
+ 指示灯绿色：此时走夜路模式被设置位高优先级，关机状态下四击进入走夜路模式，六击进入战术模式。

原本的设置项8（恢复出厂设置）则被变更为设置项9

**注：设置菜单的设置项选择界面和各个设置项均有超时功能，若一段时间没有操作，设置菜单将会超时并自动退出。该超时退出将会舍弃您在设置菜单内做的一切更改。**

### 错误指示系统

该驱动继承了Xtern Ripper PRO版本的特性，依然具备先进的状态监测系统。在驱动每次通电自检和正常运行过程中，固件会通过ADC采集驱动的运行状态并判断负载和驱动是否运行正常。并且在检测到异常时立即切断驱动输出以避免驱动和被驱动的灯珠损坏。

#### 运行时错误监测和错误ID汇报

在运行期间如果驱动检测到无法解决的致命问题则会进入保护模式避免驱动和灯珠损毁，并通过颈部侧按键的指示灯提示用户发生的错误类型。每个指示循环首先以红黄绿的颜色切换闪烁开始，然后通过紧跟着的红色慢闪次数指示错误ID号，慢闪结束后会停顿一会并重新开始循环，对于ID号所对应的错误描述请参考如下内容：

+ 闪烁1次(Fault_DCDCFailedToStart) 驱动在上电自检尝试启动DCDC时失败。检查驱动输出正极是否对外壳短路，DCDC芯片的使能信号和内部LDO输出电压是否正常。
+ 闪烁2次(Fault_DCDCShort) 驱动在运行时检测到输出短路。
+ 闪烁3次(Fault_InputOVP) 驱动检测到输入电压过高，请检测驱动的电池配置是否和使用的电池配套。
+ 闪烁4次(Fault_DCDCOpen) 驱动在运行时检测到输出空载，请检查LED是否损坏。
+ 闪烁5次(Fault_NTCFailed) 驱动在运行期间检测到测量驱动温度的热敏电阻出现异常，检查热敏电阻和测温部分的上拉电阻是否损坏。
+ 闪烁6次(Fault_OverHeat) 驱动检测到外壳温度过高，请等待手电冷却。冷却后故障会自动解除
+ 闪烁7次(Fault_DCDCPreChargeFailed) 驱动检测到实现CV环可控斜率预充的电路出现故障，请参照[故障排除文档](/FAQ.docx)进行硬件上的检查。
+ 闪烁8次(Fault_RampConfigError) 驱动在启动时检测到固件内存储的无极调光挡位数据被意外删除或丢失，此时系统无法正常工作。请检查固件编译设置内无极调光挡位相关的数据是否正常。

### 固件编译注意事项

#### 固件编译环境要求

该驱动的固件源代码使用了**Keil C51 V9.61a版本**的高级编译优化特性来实现空间压缩。使用其他的keil C51版本会导致编译出来的固件因为优化不足，超出芯片容量大小而编译失败！如果您编译无法通过则可以使用预编译固件文件夹(位于驱动固件工程的binary目录下面)内作者根据常用LED的预设电流所编译好的二进制固件文件并提供给芯片卖家让其烧录好芯片。

#### MCU的CONFIG配置

由于中微单片机内部有一组硬编码于Flash指定区域，用于设置单片机的硬件首选项（例如看门狗，调试模式，低电压保护点等）的配置Word。为了确保编译出来的固件可以在硬件内正常运行，您需要在工程配置(Options for Target 'XRLite'->Debug选项卡->右上角的Settings按钮)的Config设置菜单，按照下表正确填写MCU的配置。错误的CONFIG设置会引起固件工作异常！

+ Power                      :  Inter 5V            
+ WDT                        :  SOFTWARECONTROL     
+ PROTECT                    :  ENABLE              
+ FLASH_DATA_PROTECT         :  ENABLE              
+ LVR                        :  3.5V                
+ DEBUG                      :  Disable             
+ OSC                        :  HSI                 
+ OSC_PRESCALE               :  Fosc/1              
+ HSI_FS                     :  Fhsi/1              
+ EXT_RESET                  :  DISABLE             
+ EXT_RESETSEL               :  P00                 
+ WAKEUP_WAITTIME            :  500us               
+ CPU_WAITCLOCK              :  2T                  
+ WRITE_PROTECT[0-2K]        :  DISABLE             
+ WRITE_PROTECT[2-4K]        :  DISABLE             
+ WRITE_PROTECT[4-6K]        :  DISABLE             
+ WRITE_PROTECT[6-8K]        :  DISABLE             
+ WRITE_PROTECT[8-10K]       :  DISABLE             
+ WRITE_PROTECT[10-12K]      :  DISABLE             
+ WRITE_PROTECT[12-14K]      :  DISABLE             
+ WRITE_PROTECT[14-16K]      :  DISABLE             
+ BOOT                       :  BOOT_DIS            

#### 代码内非语法错误的提示

为了确保用户不会错误的填写部分关键数值（例如温控系统的配置参数）导致固件行为异常，本固件源码内包含一些条件编译的监测代码用于监测非法数值。如果编译时遇到了非语法错误的输出，可以在这里查询相应的错误并进行修正。

+ `Error 001:Invalid Integral Configuration,Trim Value or time-factor out of range!`: 积分器的时间常数和电流修调值决定了积分器的上限，由于积分器所使用的变量为int 16，其值域为-32767到32767。如果积分器上限超过了值域则会导致数值溢出引起程序异常。此时您需要减小电流修调值和时间常数确保两者之积不大于32000。
+ `Error 002:Invalid Integral Configuration,Trim Value or time-factor must not be zero or less than zero!`: 积分器的时间常数和电流修调值决定了积分器的上限，为了确保积分器能正常运行，积分器的上限值不能为0或者负数，请检查填入的数值是否包含负数和0。
+ `Error 003:Emergency Shutdown Temp must not exceeded 85 Celsius!` : 紧急关机温度太高了，不能超过85度
+ `Error 004:Force Disble Turbo Temp must less than Emergency Shutdown Temp for at least 15 Celsius!` :
+ `Error 005:Force Disble Turbo Temp must higher than Constant Temp of Turbo Mode for at least 8 Celsius!`: 强制禁用极亮挡位的温控值应该比紧急关机温度低15度以上，且至少高于极亮恒温温度8度
+ `Error 006:Constant Temperature of Turbo Mode must lagger than Constant Temperature of other mode!`:
+ `Error 007:Constant Temperature of other mode must lagger than Thermal Control Release Temp for 5 Celsius!`: 非极亮挡位的温控恒温温度必须要比极亮挡位的温控数值小，且至少比温控停止的阈值高5度确保温控的稳定运行。
+ `Error 008:Thermal Control Release Temp is too low and will not release at summer!`: PI环的温控释放点太低，在夏天因为手电自发热可能导致温控始终激活，即使通过外力给手电降温也无法正确退出。

----------------------------------------------------------------------------------------------------------------------------------
© redstoner_35 @ 35's Embedded Systems Inc.  2025

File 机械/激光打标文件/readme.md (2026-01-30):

## 激光打标格式说明

### ezd后缀文件

ezd格式为金橙子EZCAD 2.0激光打标系统控制软件的文件格式。里面已经包含了所有的图元和填充信息，打标时直接提交给商家即可。特别注意的是，如果商家不是使用金橙子系统的话就打不开，所以说下单之前需要**询问商家是否支持用ezd文件打标**。

### dxf后缀文件

dxf格式为标准的AutoCAD矢量图元，商家可以直接导入进行打标。图元已经按照实际尺寸进行缩放，故按照图元大小直接填充后打标即可。

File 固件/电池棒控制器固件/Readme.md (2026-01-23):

# 电池棒控制器固件操作指引

## 关于操作术语的说明

该电池棒控制器固件采用双按钮操作机制。屏幕中间的按钮实际仅用于激活保护板，不参与操作流程。**左边的按钮为向上/确认键**，当用户短按（按压时长大于0.3秒且小于3秒）时为向上功能，此时菜单会往上移动一个条目。当用户长按时为确认功能，此时将会进入选择的菜单子项。**右边的按钮为向下/退出键**，当用户当用户短按（按压时长大于0.3秒且小于3秒）时为向下功能，此时菜单会往下移动一个条目。当用户长按时为退出功能，此时将退出本子菜单项并返回上一级。

## 关机状态下如何启动电池棒控制器

为了节约电力消耗，电池棒控制器并不会处于始终开启状态。默认情况下电池棒控制器处于关机状态，此时屏幕熄灭，控制器几乎不消耗电能。当控制器检测到电池棒的USB Type-C连接放电设备或者充电器后，控制器会立即唤醒并进入工作状态，因此大部分情况下不需要手动开启控制器。如果您确实需要手动开启控制器，则长按向上/确认键或者向下/退出键直到屏幕亮起并显示logo即可松开。此时电池棒控制器将会进行自我测试和初始化，初始化结束后将会进入到工作状态并显示主屏幕。

## 主屏幕、进入主设置菜单和快捷菜单

控制器在初始化结束后将会进入主屏幕，主屏幕左侧显示电池的电压、电流和功率信息，右侧则显示系统温度、当前充电Ah数、Wh数和充电时间。右下角则会显示电池当前的状态。当系统处于充电状态时，您可通过单击向上/确认键进入USB Type-C接口的实时状态监视（可以查看电压、电流和功率）以及当前输入协议和状态。单击向下/退出键即可返回主菜单。如果您要调整电池棒控制器的系统设置，则请同时按住向上/确认键以及向下/退出键3秒，此时系统将会进入设置菜单。如果您要进入快捷菜单，则长按向上/确认键即可进入。快捷菜单允许用户临时启用/禁用储存模式、并且开启仅充电和仅放电功能以及清除故障保护。

## 开关设置项类菜单操作（例如快捷菜单）

对于仅有开关两组状态的设置项，您进入菜单后可以通过短按向上/确认键或者向下/退出键选择您需要更改状态的条目。被选中的条目会以青色高亮显示，右边的开关标记则是当前该条目的状态。如果为绿色横杠则表示条目为使能状态，红色圈则表示该条目为除能（禁用）状态。选中要更改的条目之后可以通过长按向上/确认键改变条目的状态（每次长按3秒，条目状态会改变一次，例如当前条目是使能状态，长按后会变为除能状态。除能状态以此类推）。当所有菜单项编辑完毕后，长按向下/退出键将会退出菜单并返回上一级。

## 多选项类菜单操作（例如充放电功率设置项）

对于有多个可选项的设置项，您进入菜单后系统将会用青色高亮显示当前该设置项所对应的设置值。例如您进入充放电功率设置菜单后，100W的选项被青色高亮则表示系统当前的充放电功率设置为100W。此时您可以通过短按向上/确认键或者向下/退出键选择您想要的设置值，当选择好目标的设置值后长按向上/确认键即可保存。此时系统会提示设置已保存表示保存成功。如果您想放弃更改，则长按向下/退出键。此时系统将会无视您所做的更改并回到上一级菜单。

## 数值设置类菜单操作（例如电池充电电压等）

对于具体数值类的设置菜单，您进入后系统会显示具体数值。此时您可以通过单击向上键令数值增加一个单位（例如设置值是1到10范围，步进1则按一下则会令数值增加1）单击向下键则会令数值减少一个单位。如果您需要快速且大范围的增减数值，则可以长按向上键，此时系统会令数值快速增加。长按向下键则令数值快速减少。当数值调整到您所需的目标值时，同时按住向上和向下键并保持3秒以上，此时系统会保存您所做的更改并返回到上一级菜单。

## POST阶段代码显示

该电池棒控制器在每次上电之后，均会进行上电自我测试和初始化操作，并在屏幕右下角的自检进度条上方输出自检状态的代码。代码由两位ASCII字符组成，共分为初始化进程代码，错误代码和警告事项代码三种类型。与此同时，进度条的颜色会指示系统当前自检的情况。青色表示自检进行中，黄色表示自检过程中遇到异常，但是并非重大问题。如果自检进度条变为红色则说明系统遇到重大问题，此时进度条上方会显示问题类型。如果进度条变为橙色则说明自检过程中遇到特殊事件，系统将输出额外的提示信息。对于代码的具体含义请参考如下内容：

### 初始化进程代码

+ FF：系统已上电，但是自检未开始
+ 00：启动系统心跳定时器
+ 01：启动按键控制器
+ 02：测试心跳定时器
+ 03：启动片内ADC
+ 04：测试热敏电阻(用于检测系统温度)
+ 05：唤醒IP2366电源管理IC
+ 06：初始化SMBUS(IIC)控制器并进行从机枚举
+ 07：对IP2366电源管理IC进行初步的寄存器配置
+ 08：检查IP2366电源管理IC的固件版本
+ 09：加载系统主用配置文件
+ 0A：主用配置文件发生故障，系统尝试读取备用配置
+ 0B：备用配置文件可用，系统已加载备用配置并尝试恢复主用配置
+ 0C：系统正在对加载的配置文件进行参数检查
+ 0D：系统检测到配置文件存在非法的参数配置，已进行自动修正
+ 0E：固件完整性检查开始
+ 0F：系统固件检查发现安全密匙部分未初始化（固件刷写后首次启动）已对密匙进行编程
+ 10：开始加载测容数据
+ 11：系统发现测容数据完整性校验未通过，已重置为空白状态
+ 12：开始初始化主动均衡控制器
+ 13：开始加载片内ADC校准数据
+ 14：系统开始读取数据库缓存
+ 15：系统发现数据库缓存区域损坏，尝试重建数据库/缓存操作开始
+ 16：发现缓存损坏后启动的数据库缓存重建操作完成25%
+ 17：发现缓存损坏后启动的数据库缓存重建操作完成50%
+ 18：发现缓存损坏后启动的数据库缓存重建操作完成75%
+ 19：发现缓存损坏后启动的数据库缓存重建操作已经全部完成，继续接下来的启动条目
+ 1A：缓存准备完毕，系统尝试进行缓存命中操作
+ 1B：系统在首次缓存命中尝试时失败，正在往回寻找可用的数据并更新缓存
+ 1C：系统对数据库进行寻找后仍未发现可用的日志条目，尝试重建数据库/缓存操作开始
+ 1D：发现数据库和缓存全部损坏后启动的数据库/缓存重建操作完成25%
+ 1E：发现数据库和缓存全部损坏后启动的数据库/缓存重建操作完成50%
+ 1F：发现数据库和缓存全部损坏后启动的数据库/缓存重建操作完成75%
+ 20：发现数据库和缓存全部损坏后启动的数据库/缓存重建操作已经全部完成，继续接下来的启动条目
+ 21：运行日志数据库缓存命中成功，即将开始加载数据库
+ 22：运行日志的数据域加载开始
+ 23：进行运行日志的数据库缓存的一致性检查
+ 24：发现缓存数据和运行日志内容不一致，进行覆盖处理
+ 25：系统正在对运行日志数据区的前方条目进行检查，确认是否有异常区域
+ 26：系统发现数据区前面欲写入的条目存在异常，将进行覆盖处理
+ 27：系统正在根据配置文件设置屏幕显示方向
+ 28：充电IC的后续寄存器初始化开始
+ 29：系统检测到当前开启了即插即用模式（任何设备连接到电池棒时电池棒均可以立即唤醒为设备供电）待机功耗将会变大到0.2mA
+ 2A：系统准备二次读取芯片版本信息
+ 2B：系统检测到充电芯片为定制版本，将激活鸡血模式
+ 2C：系统检测到充电芯片并非特定的定制版本，将禁用鸡血模式
+ 2D：系统检测到充电芯片并非特定的定制版本，将禁用PD3.0 20V7A 140W特殊挡位
+ 2E：系统检测到充电芯片并非特定的定制版本，将禁用高功率（66W）华为SCP对外输出的功能
+ 2F：系统将开始设置设置充电IC的再充电参数
+ 30：系统将开始设置设置充电IC的低电压保护参数
+ 31：系统将开始设置设置充电IC的对外放电系统的参数
+ 32：系统将开始设置设置充电IC的充电系统的参数
+ 33：系统将开始设置设置充电IC的对外PD Fixed输出广播的参数
+ 34：系统将开始设置设置充电IC的对外PD PPS输出广播的参数
+ 35：系统检测到充电芯片并非特定的定制版本，将禁用PPS电流的编辑功能并使用芯片默认值
+ 36：系统正在断开充电芯片的C口连接以复位芯片状态机
+ 37：系统正在断开充电芯片的C口连接时出现异常，正在重试中
+ 38：系统正在尝试启动板载的INA226功率计
+ 39：系统启动板载功率计时遇到异常，请结合显示的错误ID进行处理
+ 3A：系统正在对板载功率计进行自我测试
+ 3B：高精度功率计自我测试结果为失败，功率计将被禁用
+ 3C：高精度功率计已被启动，系统将应用功率计结果
+ 40：系统正在初始化一次性测容系统并检查是否需要进入到测容系统中
+ 41：一次性测容已被激活且电池处于亏电状态，将进入一次性测容模式
+ 42：系统正在对备用配置文件进行完整性验证
+ 43：系统正在初始化测量模块并准备电池电压和C口电压数据
+ 44：系统在初始化测量模块时，调用INA226以进行高精度测量时出现异常，将使用IP2366反馈的C口数据
+ 45：系统正在初始化新版充电板具备的C口诱骗控制器（ATCM模块）
+ 46：系统检测到当前固件运行在旧版充电板上，为保证对旧版硬件的兼容性，ATCM模块已禁用
+ 47：系统正在初始化新版充电板具备的高级电源管理控制器（APMM模块）
+ 48：系统检测到当前固件运行在旧版充电板上，为保证对旧版硬件的兼容性，APMM模块已禁用

### 系统自检结束代码

+ AA：电池棒控制器所有初始化和自我测试已正常通过，没有异常信息输出，将进入正常运行模式
+ AB：电池棒控制器在初始化期间输出了需要用户注意的提示信息，自检已正常通过将进入正常运行模式
+ AC：电池棒控制器在初始化期间遇到部分自检项目出现问题，但不影响电池棒控制器运行，将进入正常运行模式

### 错误代码

+ E0：系统心跳定时器故障（检查代码）
+ E1：片内ADC自检异常（检查代码，无效则更换IC）
+ E2：电池端电流检测电路基准电压异常（检查硬件）
+ E3：板载NTC热敏电阻（测量系统温度）故障
+ E4：重试多次后充电IC唤醒操作仍然失败
+ E5：在初配置时对IC进行多次通信操作后仍然没有回应
+ E6：在初配置或后配置时读取芯片版本信息失败
+ E7：IP2366当前的芯片内固件版本不受支持，系统无法启动
+ E8：系统在读取外部存储器(EEPROM)时出现异常
+ E9：系统在写入外部存储器(EEPROM)时出现异常
+ EA：系统在读取外部存储器的安全密匙区域时出现异常
+ EB：系统检测到当前MCU片内运行的固件已被篡改，进入锁定模式
+ EC：系统在进行OTP安全密钥初始化操作时无法写入到安全扇区
+ ED：系统在初始化主动均衡控制器时遇到问题
+ EE：系统在恢复数据库缓存时无法将Guard Key写入到缓存内
+ EF：系统在恢复数据库缓存时无法对缓存数据域进行写入
+ F0：系统在尝试读取运行日志数据库时出现异常（可能是EEPROM问题）
+ F1：系统在充电芯片后配置时未能成功写入充电芯片的休眠配置
+ F2：系统在充电芯片后配置时未能成功写入充电芯片的再充电配置
+ F3：系统在充电芯片后配置时未能成功写入充电芯片的低电压关机保护配置
+ F4：系统在充电芯片后配置时未能成功写入充电芯片的对外放电系统配置
+ F5：系统在充电芯片后配置时未能成功写入充电芯片的充电系统配置
+ F6：系统在充电芯片后配置时未能成功写入充电芯片的对外PD Fixed输出广播配置
+ F7：系统在充电芯片后配置时未能成功写入充电芯片的对外PD Fixed挡位的电流配置
+ F8：系统在充电芯片后配置时未能成功写入充电芯片的对外PD PPS挡位的配置
+ F9：系统尝试让充电芯片断开并重新连接Type-C时失败
+ FA：系统尝试进行测量初始化时异常
+ FB：系统在初始化和后配置时读取到的固件版本不一致，芯片固件可能异常
+ FC：系统在初始化C口诱骗控制器（ATCM模块）时出现异常
+ FD：系统在初始化高级电源管理控制器（APMM模块）时出现异常

### 警告事项代码

+ W0：上次系统启动时未正常关闭（可能是由于固件异常引起）
+ W1：电源管理IC唤醒失败，重试中
+ W2：系统正常工作所需的SMBUS从机通信超时
+ W3：在尝试对IP2366进行初步的寄存器配置时无法连接到IC
+ W4：系统内所有的配置文件都已损坏，系统将加载并尝试恢复到默认出厂配置
+ W5：系统检测到非法的电池端峰值电流配置，将进行自动修正
+ W6：系统检测到非法的PD输入配置，将进行自动修正
+ W7：系统在重建数据库时发现损坏的运行日志记录，将用初始值强制覆盖
+ W8：系统检测到电池电压异常，可能是电池未正确安装
+ W9：系统检测到非法的恒压充电截止电流配置，将进行自动修正
+ WA：系统检测到非法的20V PDO电流配置，将进行自动修正
+ WB：系统检测到备用配置区数据已损坏，将使用主用配置进行覆盖
+ WC：充电功率配置非法，超出2366芯片报告的能力，系统将修正结果
+ WD：系统Sink设置非法，已经自动进行修正
+ WE：系统涓流电压配置参数非法，已进行自动修正
+ WF：系统检测到当前电池包温度过低，已禁止电池充电，请等待电池包回温后再进行充电。

----------------------------------------------------------------------------------------------------------------------------------
© redstoner_35 @ 35's Embedded Systems Inc.  2025

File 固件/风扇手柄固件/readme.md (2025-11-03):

powered by 35's Embedded Systems Inc. A Next generation FlashLight Driver Solution     

### 概述

Xtern Ripper HyperFanDriver(HFD)是一款全新设计的侧按单锂升压驱动12V暴力风扇驱动，针对本手电所选配的基于东东海F1A风扇辅助散热手柄半成品五金套料所实现的风扇主动散热手柄DLC而设计。相比于市面上使用成品手电驱动（例如飞翔尾按单锂升压6V LED驱动）魔改的版本具有更低的输出纹波和更高的稳定性。该驱动同时支持2线电压调速风扇和四线PWM风扇。单锂模式下使用单节21700锂电池即可实现30W实际功率的34000RPM风扇持续运行并让手电达到2万LM的持续常亮。

### 性能数据

+ 支持的电池输入类型：1-2S三元锂电池，持续放电能力应大于20安培。
+ 支持的风扇类型：12V额定工作电压的直流无刷风扇，2线电压调速或四线PWM调速均可
+ 支持的风扇电流和功率：单锂条件下30W(12V 2.5A) 双锂串联条件下72W(12V6A) **注意：本处所标称的电流为支持的风扇实际电流而非风扇标签上所写的电流，只要保证风扇的实际运行电流不超过限制即可。例如建准XF40281BX风扇的标签电流为3A，但实际运行电流为2.25A，此时风扇是可以正常使用的**
+ 电池保护：具有欠压自动降档和关机保护以及过电压保护

### 总体操作逻辑

该风扇驱动同时具备无级调速和阶梯挡位调速可以随时选择。同时还具备双击一键全速功能。对于风扇的操作逻辑可以参考如下：
逻辑图

对于图中的部分未详尽解释的特殊逻辑，则可参考如下内容：

+ 按键锁：关机状态下五击开关，侧按指示灯红色闪三次进入锁定模式，此时任何操作无效。**为了保证安全，进入锁定模式后即使重新安装电池，风扇也会始终保持在锁定状态。** 在锁定状态下再次五击，侧按指示灯绿色闪烁三次，并且风扇低速运转1.5秒，表示成功解锁，此时风扇可以正常操作。

+ 查询电量：任意状态下通过双击+长按进入。当进入电量查询模式后风扇的颈部开关指示灯首先将会以红黄绿依次点亮的方式作为先导提示，提示用户风扇即将开始显示电池电压和电量。延迟1秒后风扇将通过红色，黄色和绿色的指定次数的慢速闪烁（如果快速闪烁一次，则表示该数据位为0）提示用户当前的电池电压，播报完电池当前电压后，风扇将会在延迟2秒后通过后续的长亮(或者慢闪)提示用户当前电池电压对应的总体电量水平（指示方式参考下文中驱动位于正常工作时的指示），对于电池具体电压播报的计算方式请参考如下内容：
  - 红色闪烁次数+黄色闪烁次数x0.1+绿色闪烁次数x0.01=当前电池电压(V)，例如`红色慢闪4次-黄色慢闪1次-绿色慢闪3次`表示电池电压为4+1*0.1+3x0.01=4.13V。

+ 设置按键有源夜光功能：关机状态下七击按键，风扇的侧按指示灯以绿色快闪一次表示功能开启。若以红色快闪一次则表示功能关闭。该功能开启后，风扇手柄将会在闲置未用且电池电压充足的情况下令按键发出微弱绿光指示风扇手柄的开关位置。
+ 恢复出厂设置：在手柄处于断电状态下，持续按住按钮并装入电池。此时手柄的侧部按键指示灯将会以黄色的持续高频率快闪提示用户已恢复出厂设置。用户松开按键后2秒，手柄将会自动重启并进入正常工作状态。需要注意的是，恢复出厂设置并不能清除电池配置锁定。

### 电池参数配置

该风扇驱动同时支持单锂和双锂电的操作，在电池配置未锁定的情况下，风扇手柄可以自动检测双锂电的插入并切换为双锂电池模式。对于电池配置模式用户也可以随时进行调整。**需要注意的是，如果系统处于电压调速模式，则电池参数配置将不支持，且系统永远只能工作于单锂模式。** 对于如何确认系统当前的电池配置以及调整配置、识别系统异常等，请参考如下内容：

+ 识别系统当前的电池配置：在每次装入电池时，电量指示灯会进行自检并显示当前电池电量。如果当前系统开启了双锂电模式，则系统在装入电池后首先会以黄色快闪2次，延迟0.5秒后再显示电池电量（假设电量充足，则指示灯将绿色常亮3秒）。若当前为单锂模式，则驱动将会直接提示电池电量。
+ 双锂电自动识别功能：当系统处于单锂电模式且电池配置未锁定时，如果用户装入两节电池，则系统会检测到并自动切换至双锂模式。此时系统会通过绿色快速频闪2秒作为检测到双锂的提示，并在2秒后以双锂模式重新启动。
+ 电池状态异常识别：为了避免用户装入不匹配的电池导致驱动工作异常或者引起电池过度放电，系统会根据当前的电池配置对电池进行状态验证。如果您在装入电池后看到颈部开关以红色持续高频闪烁，则说明系统检测到电池异常，请检查电池是否和系统设置匹配。**例如，在单锂电模式下装入了2节电池，或在双锂电模式下装入了三节电池，都会触发保护。**
+ 切换单锂/双锂模式：在电池配置没有锁定的情况下，用户可以通过在关机状态下五击+长按切换单锂和双锂模式。当切换为单锂模式时，风扇手柄的侧按将会通过红色频闪一次提示已经成功切换。如果是切换为双锂模式，则扇手柄的侧按将会通过绿色频闪2次提示成功切换。**需要注意的是，如果系统当前安装了2节电池，为了保护电池避免过度放电，此时系统将会禁止用户切换为单节锂电池模式。如果您需要从双锂模式切换至单锂模式，请将电池取出并仅安装一节电池，再进行切换操作。**
+ 电池配置锁定：对于面向成品手电客户的场合，为了避免用户擅自更改电池配置引起问题，您可以在设置好系统的电池配置后对电池配置进行半永久性锁定。触发锁定的方法是在关机状态下连续八击按键，成功锁定后风扇手柄将会以绿色闪烁三次作为提示。在锁定后，用户将无法通过五击+长按的方式切换电池配置，同时系统也不会自动识别双锂电的装入并自动配置为双锂模式。**该锁定操作为半永久性操作，一旦执行将无法撤销。如果确实因为意外情况需要撤销，则需要重新刷写固件。**

### 风扇调速模式配置

该风扇驱动在硬件PCBA的背部有一个标识为P的电阻焊盘位置（如下图所示）用于设置固件的工作模式：
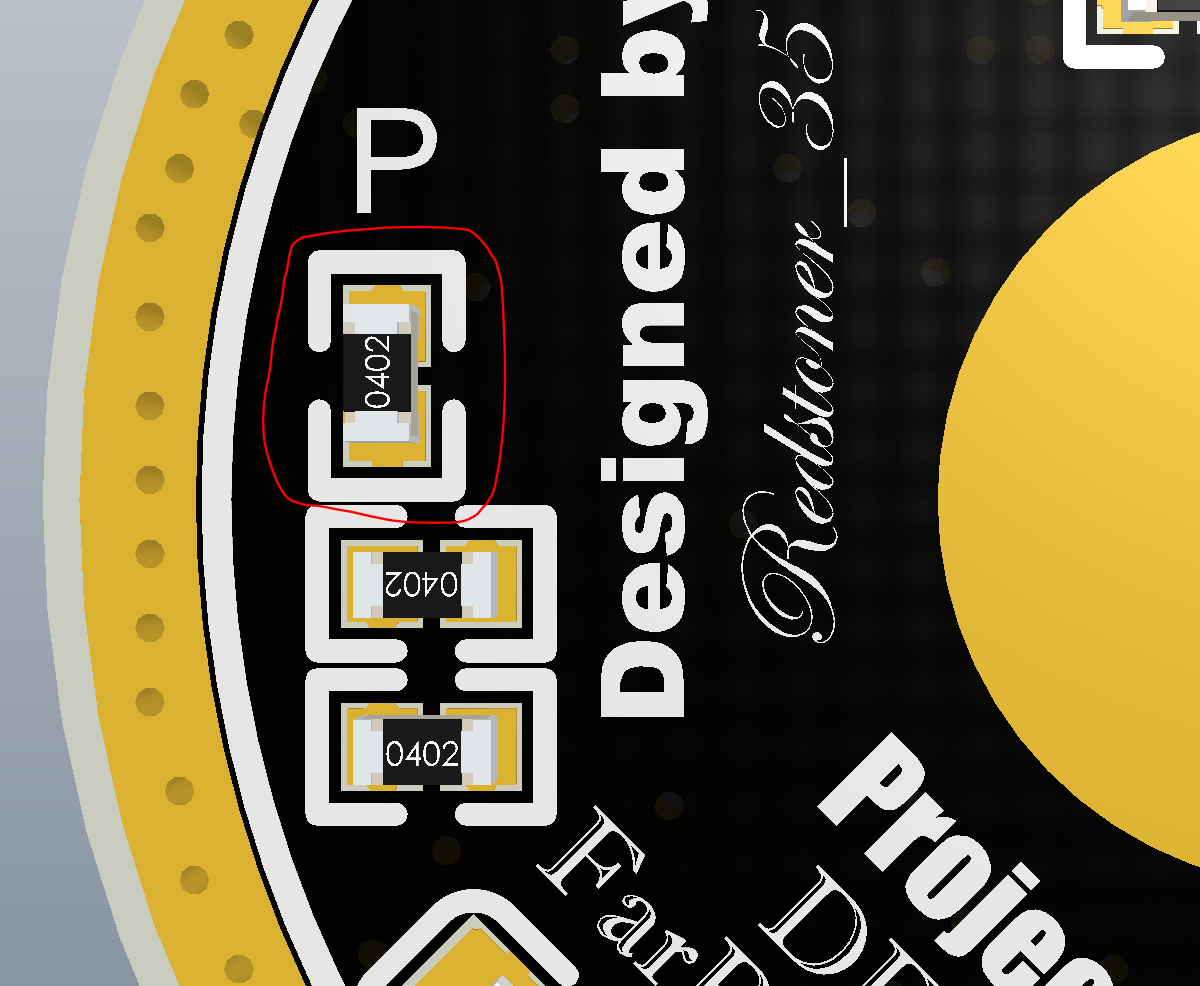
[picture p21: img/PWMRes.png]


在每次上电时，固件将会自动识别该电阻的状态并切换模式。该电阻安装时固件将会工作于PWM调速模式（该模式适配四线暴力风扇）。此时风扇驱动始终固定输出12V电压，风扇速度由驱动输出的PWM信号控制。**此时固件不支持使用只有电源线的2线或只有电源+转速反馈的3线风扇。如果强行使用会导致风扇始终全速无法调速！** 如果您需要使用`2线或3线的不支持PWM调速的风扇`则需要去除该电阻并配置为电压调速模式。此时系统将会禁用PWM信号输出并通过调控风扇电压对风扇速度进行控制。**需要注意的是，如果你的风扇是高转速暴力风扇，则因为风扇的启动电压通常较高导致电压模式下调速范围会极窄。此时将会出现部分挡位电压过低导致风扇无法启动的问题。因此作者建议在搭配暴力风扇使用时开启PWM调速模式。**

同时需要注意的是，由于该驱动仅支持升压，因此风扇电压应始终高于电池电压。为了保证电压模式下调速范围正常，如果您配置驱动使用电压调速模式，则驱动将会禁用双锂电支持。此时若装入两节锂电池，驱动将会拒绝运行并报错。仅四线PWM调速模式并搭配四线PWM风扇时，支持双锂电池运行。

### 编译固件时MCU的CONFIG配置

由于中微单片机内部有一组硬编码于Flash指定区域，用于设置单片机的硬件首选项（例如看门狗，调试模式，低电压保护点等）的配置Word。为了确保编译出来的固件可以在硬件内正常运行，您需要在工程配置(Options for Target 'XRFan'->Debug选项卡->右上角的Settings按钮)的Config设置菜单，按照下表正确填写MCU的配置。错误的CONFIG设置会引起固件工作异常！

+ Power                      :  Inter 5V            
+ WDT                        :  SOFTWARECONTROL     
+ PROTECT                    :  ENABLE              
+ FLASH_DATA_PROTECT         :  ENABLE              
+ LVR                        :  3.5V                
+ DEBUG                      :  Disable             
+ OSC                        :  HSI                 
+ OSC_PRESCALE               :  Fosc/1              
+ HSI_FS                     :  Fhsi/1              
+ EXT_RESET                  :  DISABLE             
+ EXT_RESETSEL               :  P00                 
+ WAKEUP_WAITTIME            :  500us               
+ CPU_WAITCLOCK              :  2T                  
+ WRITE_PROTECT[0-2K]        :  DISABLE             
+ WRITE_PROTECT[2-4K]        :  DISABLE             
+ WRITE_PROTECT[4-6K]        :  DISABLE             
+ WRITE_PROTECT[6-8K]        :  DISABLE             
+ WRITE_PROTECT[8-10K]       :  DISABLE             
+ WRITE_PROTECT[10-12K]      :  DISABLE             
+ WRITE_PROTECT[12-14K]      :  DISABLE             
+ WRITE_PROTECT[14-16K]      :  DISABLE             
+ BOOT                       :  BOOT_DIS 

----------------------------------------------------------------------------------------------------------------------------------
© redstoner_35 @ 35's Embedded Systems Inc.  2025

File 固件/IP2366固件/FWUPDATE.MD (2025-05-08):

### 固件升级的目的

英集芯IP2366原厂的固件处于安全性考虑（避免充电倍率过高以及硬件受不住炸管）具有电池连续电流和峰值电流限制。默认设置是9.4A峰值电流，7A的最大连续电池电流。因此使用原厂固件时三串最高的充电输入功率只能达到65W。为了实现3串也可以达到140W充放电因此我特意找原厂的技术部门定制了无任何充电电流限制的特殊固件使得三串也可以跑满140W输入功率。实测在任何电池电压条件下输入均能达到接近140W的功率。

### 如何升级固件

英集芯的IP2366实际上是一个软件定义的电源SoC，因此通过官方的专用烧录硬件可以通过芯片引出的充放电 USB-Type-C接口进行升级。升级流程是首先将电池架上的电池全部拆下，等待2分钟确保电池架的电容内没有任何残余电能（**这一步极其重要！如果在芯片连接了电池的状态下尝试升级，会导致芯片固件不完整引起芯片死机甚至永久性损坏芯片内部底层数据，使芯片永远变砖无法使用和再次烧录！**）。然后通过C to C线连接电池架和烧录器。接着把烧录器连接至电脑，将解密后的固件原始bin复制到烧录器的盘符里面。然后按照烧录器操作文档进行操作升级（这份固件升级指引可以问原厂代理要）

### 如果我没有烧录器怎么办呢？

有些具有原厂代理资格的英集芯分销代理具有这个烧录工具，可以在购买IP2366芯片时提供定制固件的原始bin文件给他们并让他们在出货之前烧录好。

### 固件为什么是.ENC后缀而不是原始的bin后缀？

考虑到无限制充电固件在充电限流方面没有任何保护，如果用户使用的电池不足以承受140W满功率充电的倍率将会造成严重的事故。同时该固件属于定制固件，涉及到原厂合作关系方面的复杂事情，因此不能直接提供原始的固件文件。ENC文件是基于原始固件bin文件进行加密和字符序列化后的加密产物。对于该文件的解密工具您可联系作者并在通过资格审查后索取。

对于未通过资格审查的用户，您可直接使用官方的IP2366_I2C版本芯片。使用该版本芯片则电池棒控制器固件将会把最大充放电功率锁定在65W，充电时间约3.5小时。

----------------------------------------------------------------------------------------------------------------------------------
© redstoner_35 @ 35's Embedded Systems Inc.  2025

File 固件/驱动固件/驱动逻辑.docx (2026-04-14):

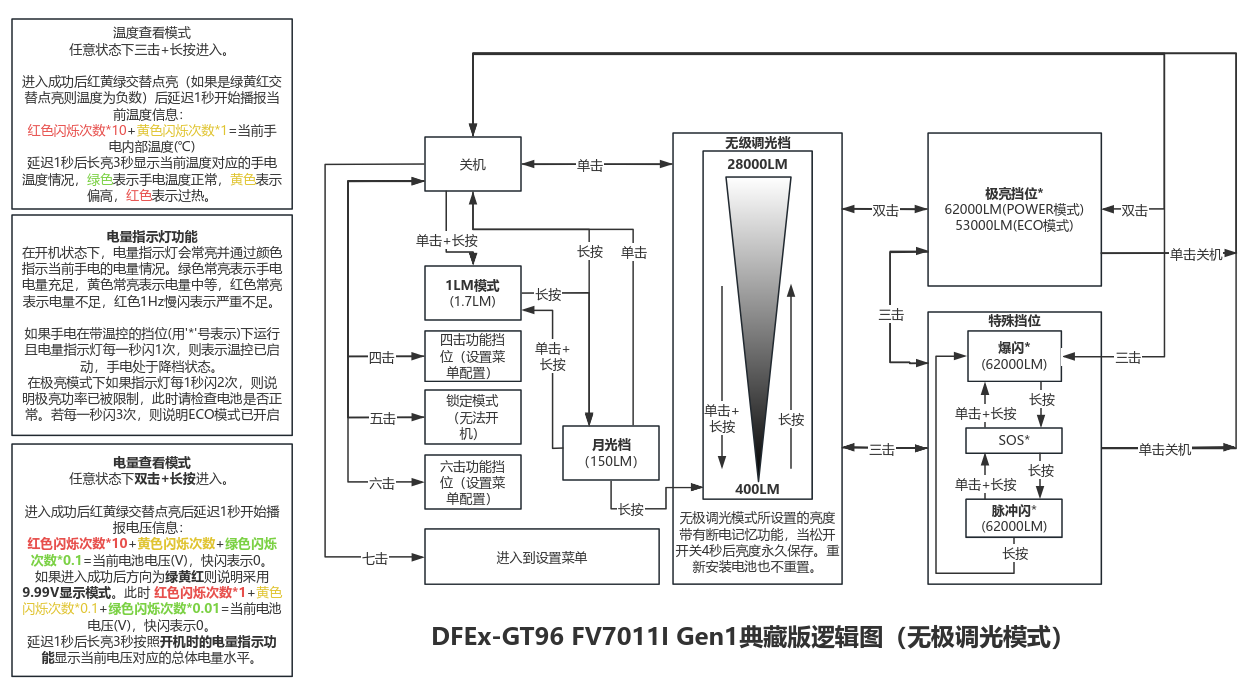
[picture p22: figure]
wps
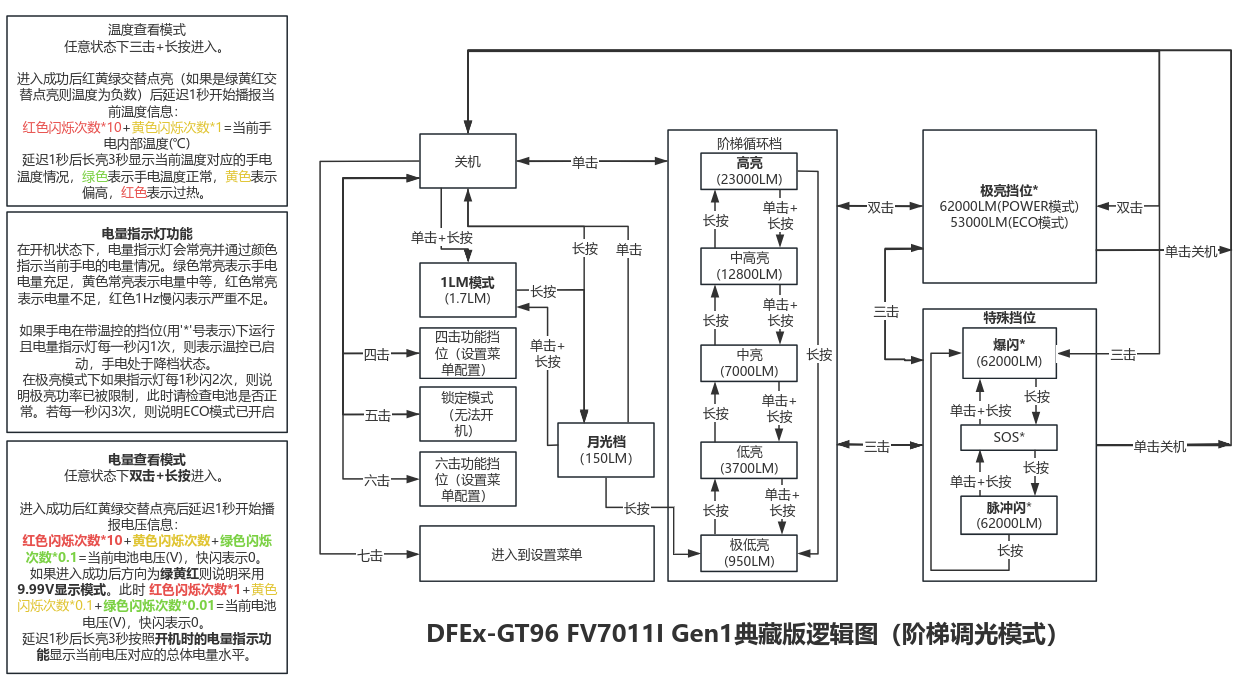
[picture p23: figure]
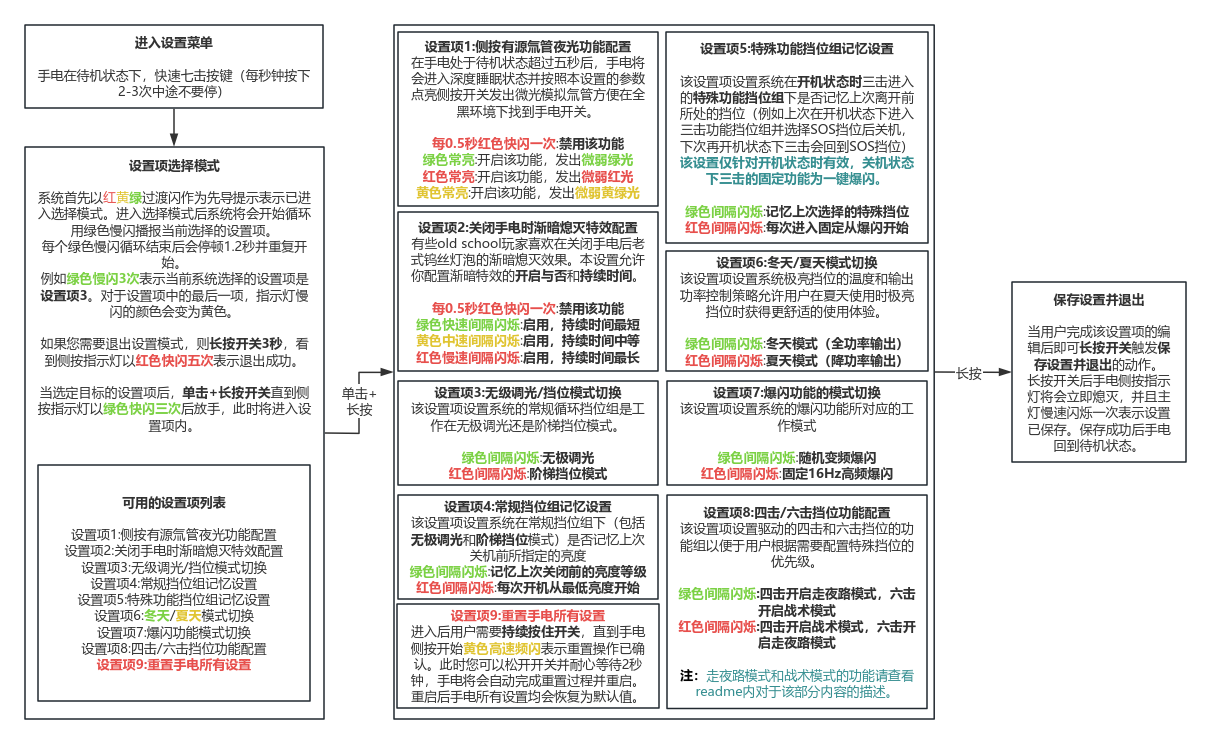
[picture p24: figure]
wps

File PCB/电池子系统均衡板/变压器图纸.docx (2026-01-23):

变压器图纸数据

变压器骨架：T1495 10Pin SMD骨架（如下图所示）

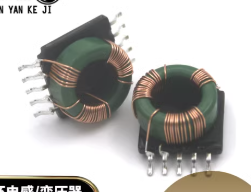
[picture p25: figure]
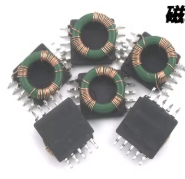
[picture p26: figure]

磁环材质：绿色锰锌铁氧体磁环（不能换其他类型）

漆包线材质：QA-155 0.5mm漆包线

绕制参数：每组绕组8+8T，中心抽头引出。绕组需要按照如下实物映射图进行接线：

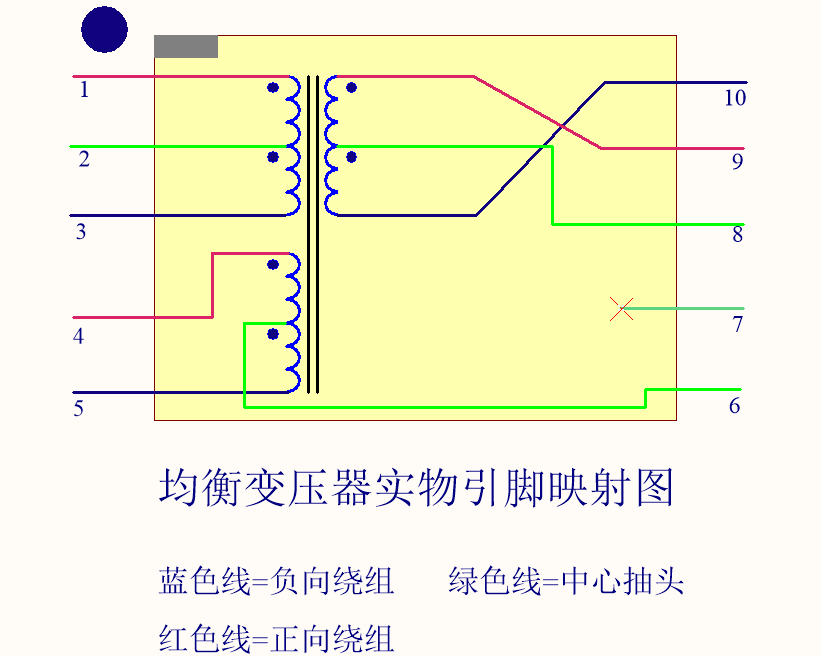
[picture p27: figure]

固定工艺：漆包线采用真空浸漆固定，磁环中间和骨架需要使用E44环氧树脂进行固定灌封避免磁环脱落。

特别注意事项：变压器的磁环在固定到骨架上时，必须朝向PIN1的方向位移！确保变压器在靠近板边的位置处，磁环加上绕组后的边沿外圆和骨架右侧处于齐平状态，否则变压器无法安装！

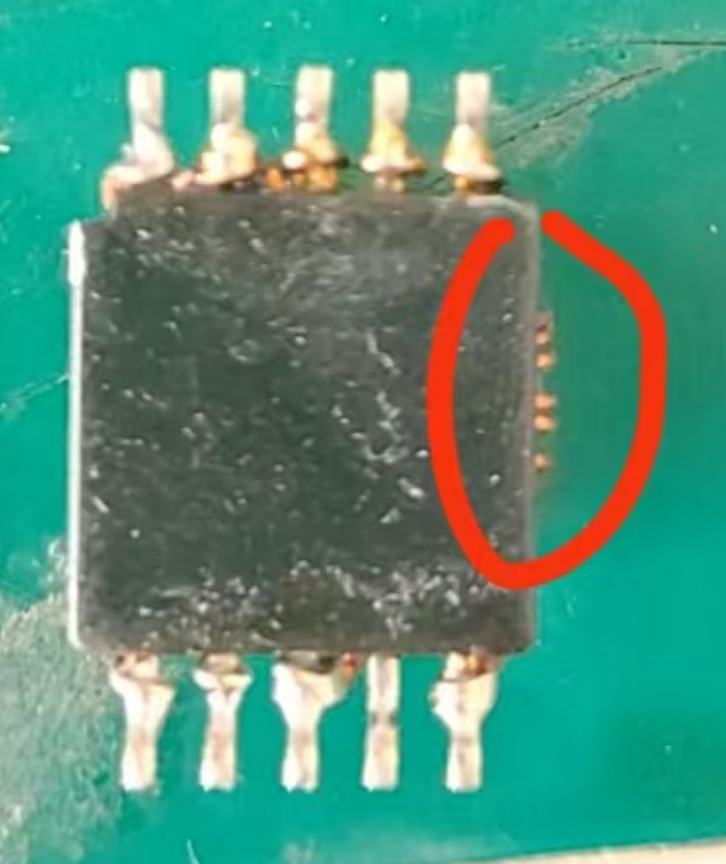
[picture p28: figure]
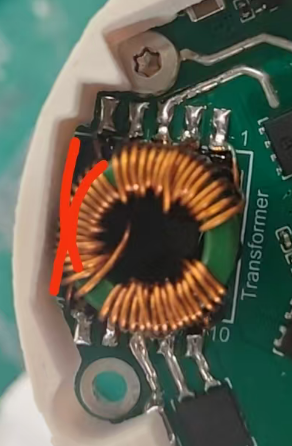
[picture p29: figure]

其中左侧为不合格（NG）图例，右侧为合格（GOOD）图例

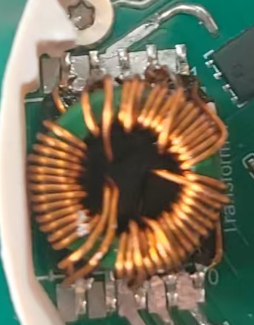
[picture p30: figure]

如果磁环超出骨架左侧边沿则会引起上图所示的问题导致变压器无法安装！请务必注意。

变压器成品参考图如下：

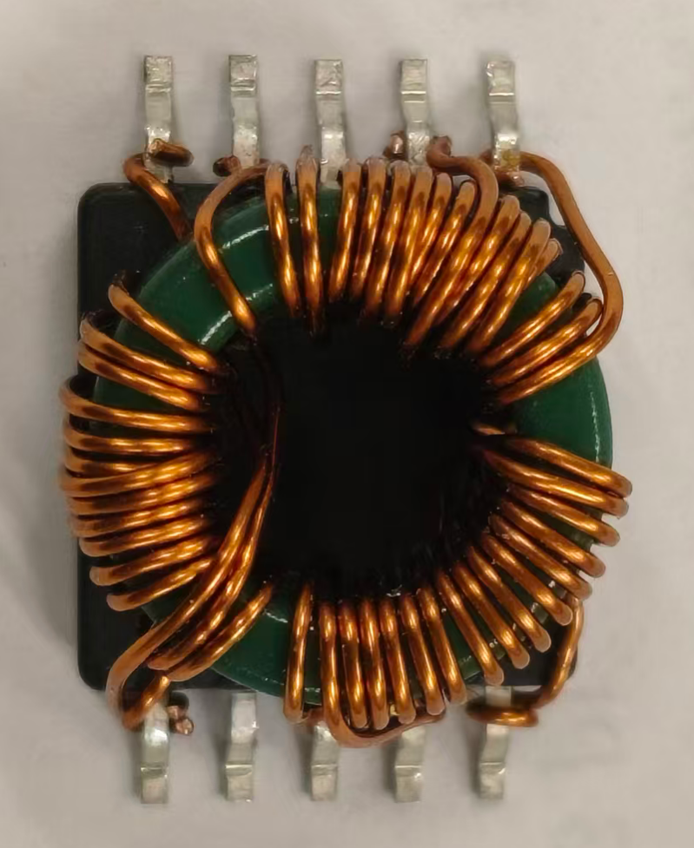
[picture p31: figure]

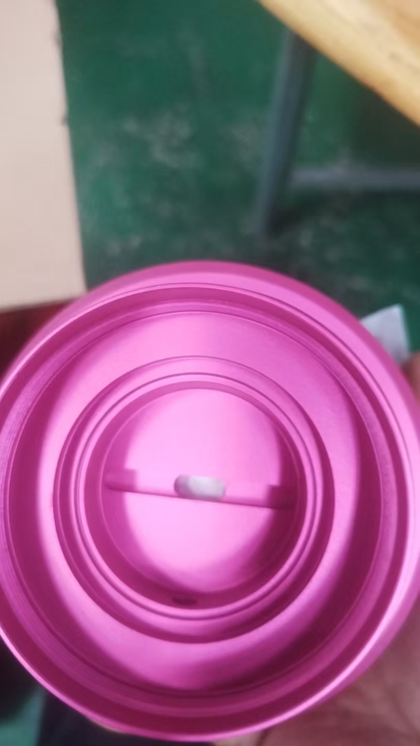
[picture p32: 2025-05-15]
img/驱动仓去氧化前.jpg

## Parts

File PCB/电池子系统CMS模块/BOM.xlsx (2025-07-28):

参数 | 描述 | 位号 | 封装 | 数量 | 单价 | 总价 | 备注
10uF (106) 10% 10V | 0603贴片电容 | C1, C16, C17 | 0603_C | 3 | 0.04 | 0.12
1.0uF (105) 10% 25V | 0402贴片电容 | C2, C5, C9, C21 | 0402_C | 4 | 0.04 | 0.16
4.7uF (475) 20% 10V | 0402贴片电容 | C3 | 0402_C | 1 | 0.04 | 0.04
100nF (104) 10% 16V | 0402贴片电容 | C4, C6, C7, C8, C11,C12, C13, C14, C15 | 0402_C | 9 | 0.04 | 0.36
10uF (106) 20% 10V | 0402贴片电容 | C10,C18, C19, C22, C23 | 0402_C | 5 | 0.04 | 0.2
220nF (224) 10% 16V | 0402贴片电容 | C20 | 0402_C | 1 | 0.04 | 0.04
B5819WS S4 | 肖特基二极管，1A电流 40V耐压 SOD-323封装 | D1, D2 | SOD-323 | 2 | 0.2 | 0.4
BAW56WT1G | 双高速开关二极管，共阳极 SOT323-3(SC70-3)封装 | D3 | SC70-3 | 1 | 0.15 | 0.15
1N4148WS T4 | 高速开关二极管 SOD-323封装 | D4, D5 | SOD-323 | 2 | 0.08 | 0.16
BZT52C6V2S | SOD-323稳压二极管 6.2V稳压电压 | D6, D7 | SOD-323 | 2 | 0.095 | 0.19
0420-4.7uH | 一体成型贴片电感 4x4x2mm尺寸 4.7uH电感量 | L4 | IND0420 | 1 | 0.34 | 0.34
JVC2.54-2P | 2-Pin圆孔排母 2.54mm间距 | P1 | CONN-TH_2P-P2.54_JVC-2.54MM-2P | 1 | 0.45 | 0.45
JVC2.54-4P | 4-Pin圆孔排母 2.54mm间距 | P2, P3 | CONN-TH_4P-P2.54_JVC-2.54MM-4P | 2 | 0.483 | 0.966
SS8550 Y2 | PNP三极管，SOT-323 封装 | Q1, Q5 | SC70-3 | 2 | 0.1275 | 0.255
2N7002DW | Dual N-Channel MOSFET 60V340mA SOT-363 | Q2, Q7 | SC70-6 | 2 | 0.3 | 0.6
XP6601 | SOT23-6封装 P+N沟道MOSFET | Q3 | SOT95P245X110-6N | 1 | 0.27 | 0.27 | 如果买不到可以用DMG6601LVT-7替代
2N7002KW | MOS(场效应管) | Q4 | SC70-3 | 1 | 0.2 | 0.2
NCE60P04Y | MOS(场效应管) | Q6 | SOT-23(SOT-23-3) | 1 | 0.38 | 0.38
1Ω (1R00) ±1% | 0402贴片电阻 | R1 | 0402_R | 1 | 0.03 | 0.03
20KΩ (2002) ±1% | 0402贴片电阻 | R2, R5, R14, R25 | 0402_R | 4 | 0.03 | 0.12
9.1KΩ (9101) ±1% | 0402贴片电阻 | R3, R6 | 0402_R | 2 | 0.03 | 0.06
15KΩ (1502) ±1% | 0402贴片电阻 | R4, R19 | 0402_R | 2 | 0.03 | 0.06
10KΩ (1002) ±1% | 0402贴片电阻 | R7, R8, R9, R20, R24, R29 | 0402_R | 6 | 0.03 | 0.18
ARG02BTC1501 | 0402贴片精密电阻，1.5K 0.1% 25PPM | R10, R11 | 0402_R | 2 | 0.12 | 0.24
10Ω (10R0) ±1% | 0402贴片电阻 | R12, R13 | 0402_R | 2 | 0.12 | 0.24
ARG02BTC1002 | 0402贴片精密电阻，10K 0.1% 25PPM | R15, R18 | 0402_R | 2 | 0.12 | 0.24
SDNT1005X153H3450HTF | 0402贴片热敏电阻 15K@25℃ 1% B值3450 | R16 | 0402_R | 1 | 0.12 | 0.12
ARG02BTC1003 | 0402贴片精密电阻，100K 0.1% 25PPM | R17 | 0402_R | 1 | 0.12 | 0.12
3.3KΩ (3301) ±1% | 0402贴片电阻 | R21, R23 | 0402_R | 2 | 0.03 | 0.06
100KΩ (1003) ±1% | 0402贴片电阻 | R22 | 0402_R | 1 | 0.03 | 0.03
100Ω (1000) ±1% | 0402贴片电阻 | R26 | 0402_R | 1 | 0.03 | 0.03
51KΩ (5102) ±1% | 0402贴片电阻 | R27 | 0402_R | 1 | 0.03 | 0.03
180KΩ (1803) ±1% | 0402贴片电阻 | R28 | 0402_R | 1 | 0.03 | 0.03
220Ω (1000) ±1% | 0603贴片电阻 | R30 | 0603_R | 1 | 0.03 | 0.03
0Ω (0R0) ±1% | 0402贴片电阻 | R31 | 0402_R | 1 | 0.03 | 0.03
2KΩ (2001) ±1% | 0402贴片电阻 | R32 | 0402_R | 1 | 0.03 | 0.03
4x4x4.3H轻触开关 | 4x4尺寸贴片微动开关，4.3H高度 | S1, S2, S3 | SW-SMD_4P-L5.2-W5.2-P3.70-LS6.4 | 3 | 0.03 | 0.09
0.96Inch LCD | 中景园电子0.96寸TFT LCD,160*80 分辨率，IPS材质，ST7735控制器， SPI接口，13Pin焊接软排线瀚彩玻璃铁框 | U1 | 0.96"IPS160*80TFT | 1 | 4 | 4
MPQ2013AGQ-33-AEC1 | 具有使能引脚的40V耐压MPS LDO, 3.3V固定输出，SON-8(3x3)封装，符合AEC-Q100认证 | U2 | MPQ2013A-QFN8 | 1 | 4 | 4
HT32F52352-QFN33 | Holtek MCU Cortex M0+ 48MHz 128K ROM 16K RAM，QFN33-4x4封装 | U3 | QFN33-4x4 | 1 | 9.8 | 9.8
REF3025AIDBZR | 50PPM/℃ 25mA最大输出能力 2.5V固 定电压串联基准芯片，SOT23-3封装 | U4 | SOT-23_N | 1 | 0.99 | 0.99
INA213AIDCKR | 50倍增益 26V共模范围高精度检流放大器，SC70-6封装 | U5 | SC70-6 | 1 | 1.1 | 1.1 | 关键器件，对电流检测精度影响 较大，除非预算过低否则不建议用INA199A1去替代
OPA391DCKR | CMOS超小型单路轨到轨精密运算放 大器，45uV失调电压，SC70-5 | U6 | SC70-5 | 1 | 1.95 | 1.95 | 关键器件，对温度和电压检测精度影响 较大，不建议使用LMV321IDCKR替代除非预算太低
CH443K | 低电压单刀双掷模拟开关芯片， 1.8V-5V供电，SC70-6封装 | U7 | SC70-6 | 1 | 0.3 | 0.3
TPS63710DRRR | TI电压反相器，SON12封装 | U8 | DR0012C | 1 | 5.2 | 5.2
FM24C512D-DN-T-G | 512Kbit(64K*8)I2C接口EEPROM，带有唯一ID和安全扇区 UDFN-8(2x3) | U9 | UDFN-8 | 1 | 1.23 | 1.23 | 程序内使用到了安全扇区和唯一UID， 不能用其他型号代替否则程序起不来会报错！
HT7533-3 | 低压差线性稳压(LDO) 30V输入耐压， 3.3V固定输出电压 | VR1 | SOT-89(SOT-89-3) | 1 | 0.49 | 0.49
总计BOM价格 |  |  |  |  |  | 36.111

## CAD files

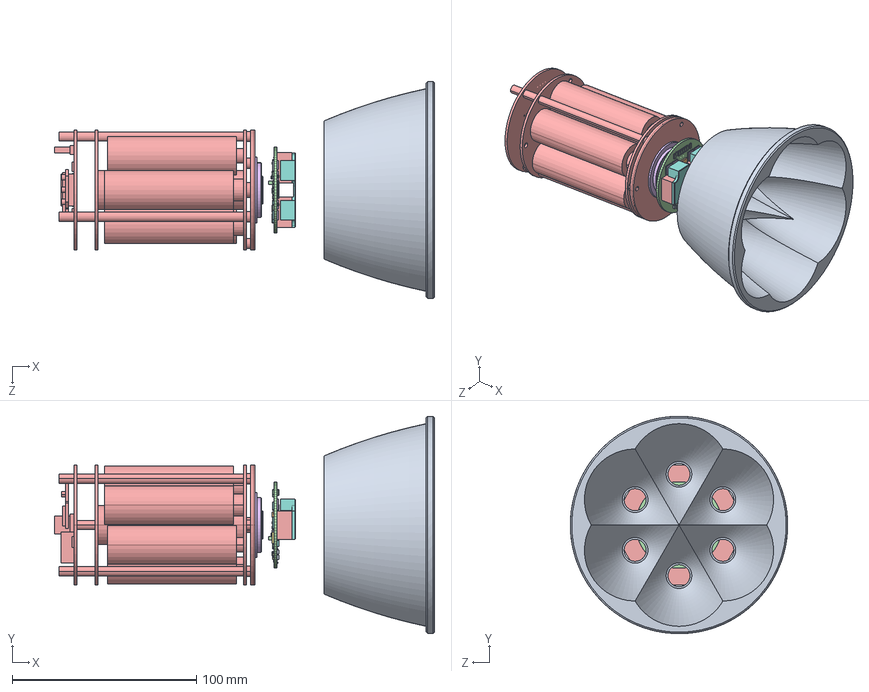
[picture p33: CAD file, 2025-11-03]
机械/筒身/装配效果.SLDASM
206.2 x 118.0 x 118.0 mm
SD12反光杯.stp
Extruded.step x 4
User_Library-0603_SMD_Capacitor.step x 5
User_Library-C_SMD_1206.step x 25
Extruded-0.step x 2
Extruded-1.step x 4
Extruded-2.step
Extruded-3.step x 2
0402_SMD_Capacitor.step x 21
User_Library-AVX_ACASE.step
User_Library-RES_1005-0402.step x 28
Extruded-4.step
SOD323.step x 3
L0402.step x 2
Extruded-5.step
Extruded-6.step
Extruded-7.step x 4
Extruded-8.step
Extruded-9.step
User_Library-0805_SMD_Capacitor.step
Extruded-10.step
User_Library-RES_1609-0603.step
Extruded-11.step
Extruded-12.step
Extruded-13.step
Extruded-14.step
Extruded-15.step
Board.step
电池架.step
电池正极铜垫片
电池架正极黄铜导电电极
驱动散热铜块

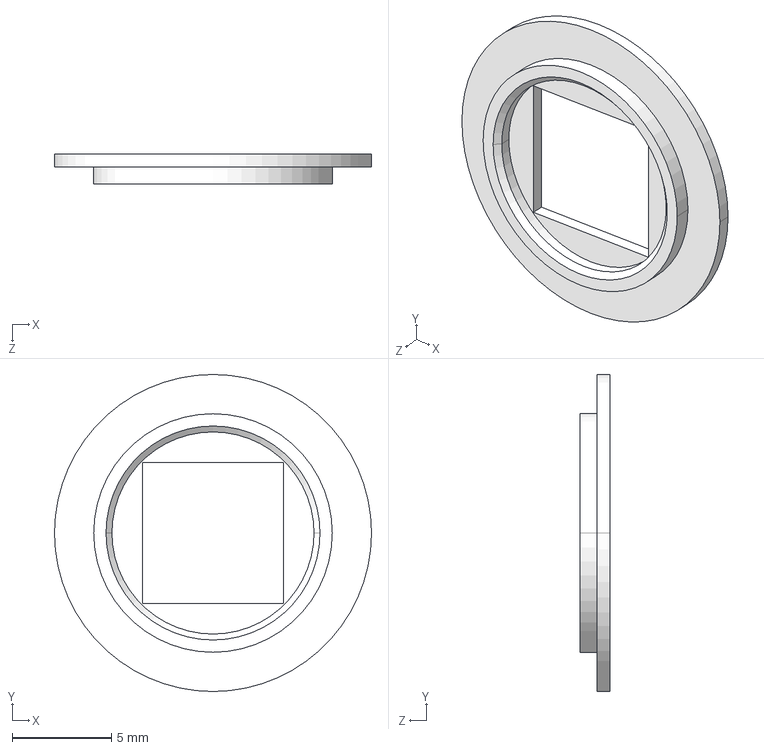
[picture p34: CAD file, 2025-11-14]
机械/光学部分/专用定位片-7070-尺寸精调.STEP
16.0 x 16.0 x 1.50 mm

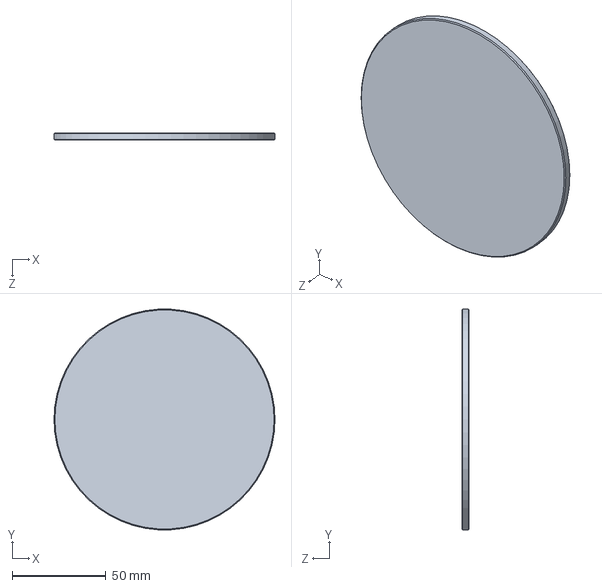
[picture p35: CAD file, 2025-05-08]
机械/光学部分/光杯和玻璃/玻璃.SLDPRT
118.0 x 117.8 x 4.00 mm

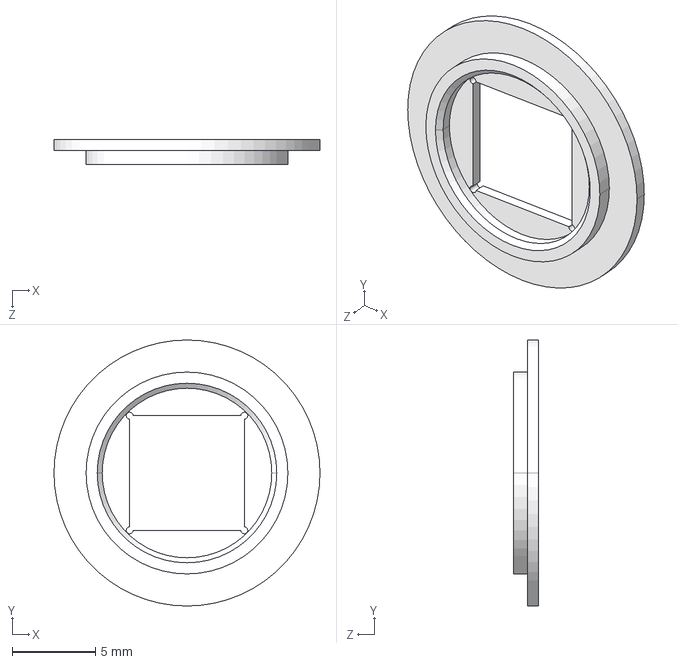
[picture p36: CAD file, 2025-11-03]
机械/光学部分/定位片3D制造文件/专用定位片-FL7018I-ES.STEP
16.0 x 16.0 x 1.50 mm

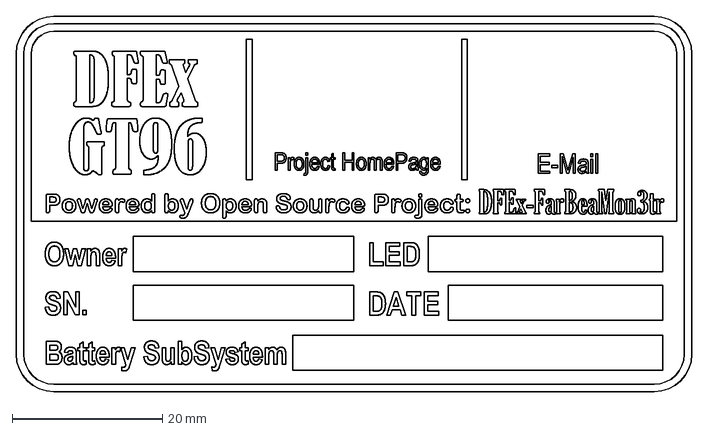
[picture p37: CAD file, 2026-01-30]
机械/激光打标文件/DXF/GT96铭牌.DXF
90.0 x 50.0 mm

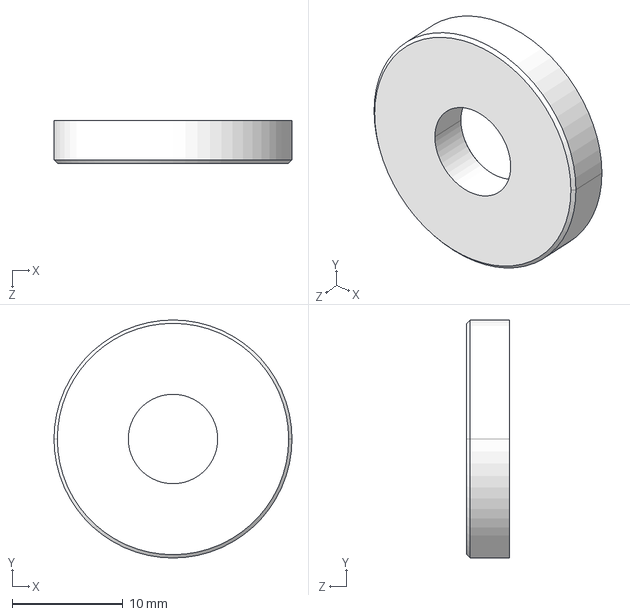
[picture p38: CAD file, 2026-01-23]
机械/电池架/Step/电池架正极垫圈.STEP
21.5 x 21.5 x 3.85 mm

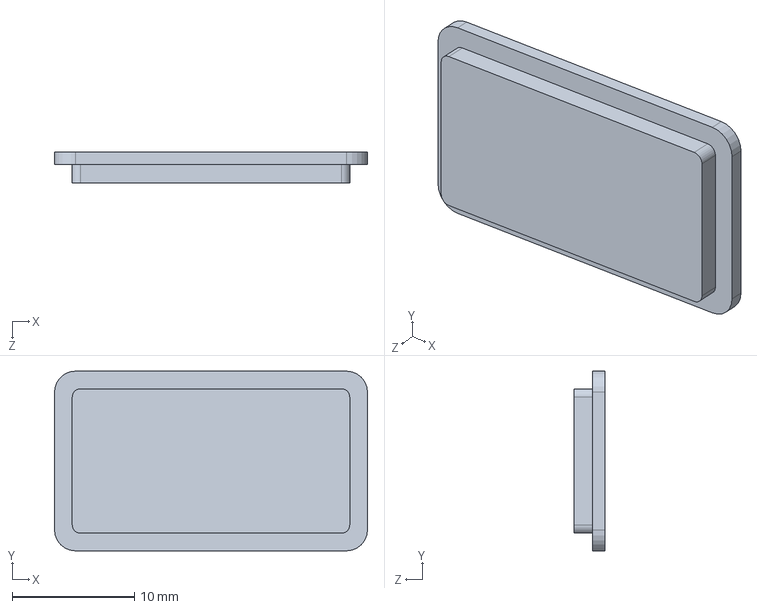
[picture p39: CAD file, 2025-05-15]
机械/电池架/电池仓屁股显示窗.SLDPRT
25.6 x 14.7 x 2.50 mm

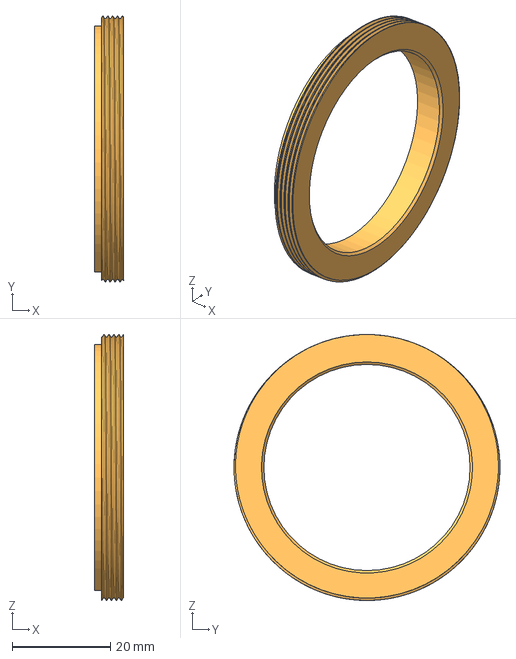
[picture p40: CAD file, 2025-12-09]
机械/筒身/Step/驱动压环.stp
6.00 x 54.2 x 54.2 mm

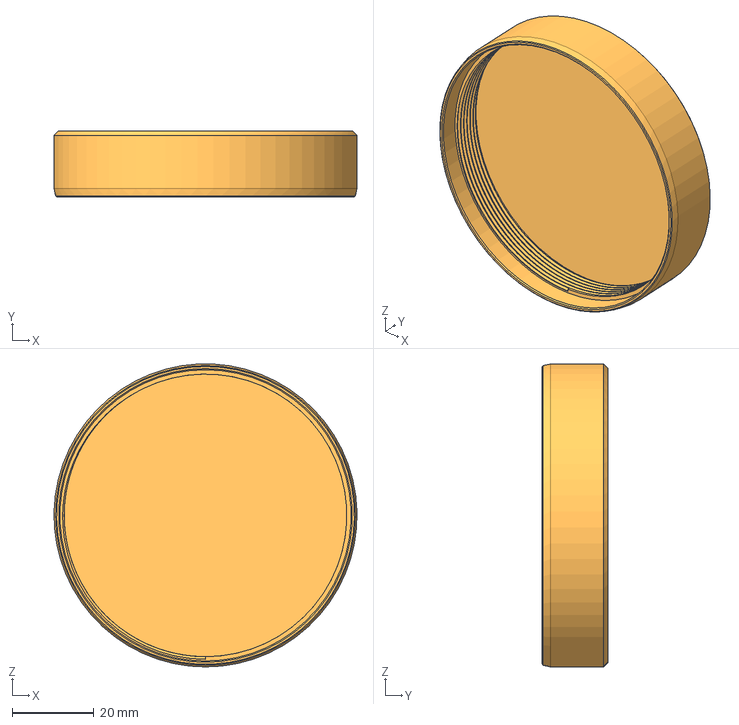
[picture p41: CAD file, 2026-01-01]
机械/筒身/电池仓正极侧保护盖.stp
74.0 x 16.0 x 73.9 mm

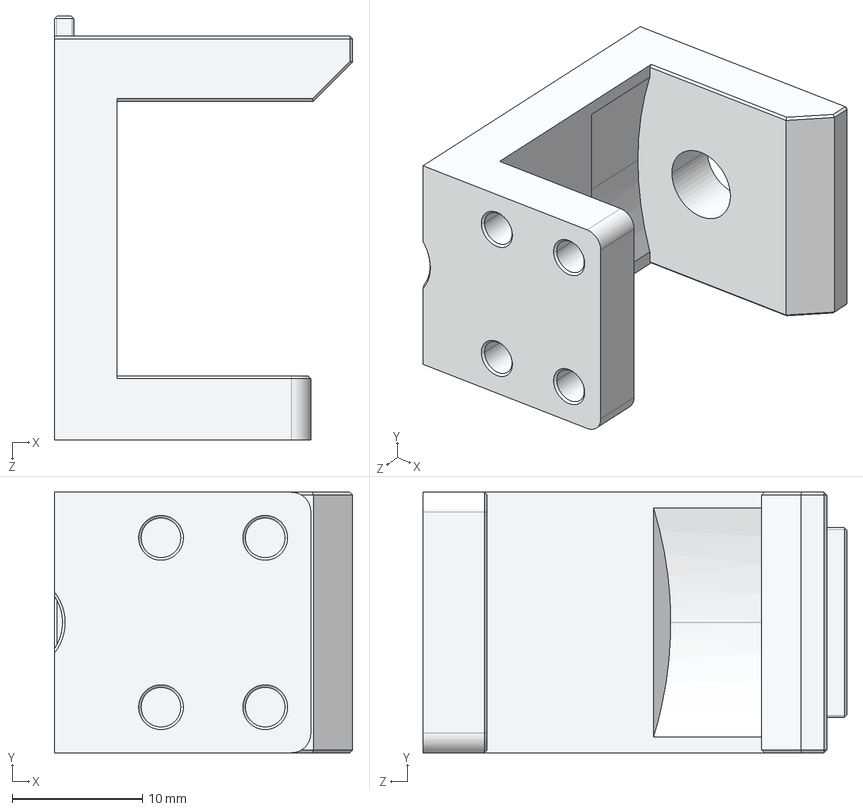
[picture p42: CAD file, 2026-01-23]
机械/风扇手柄外框/Step/GT96专用风扇手柄固定块.STEP
22.9 x 20.0 x 32.5 mm

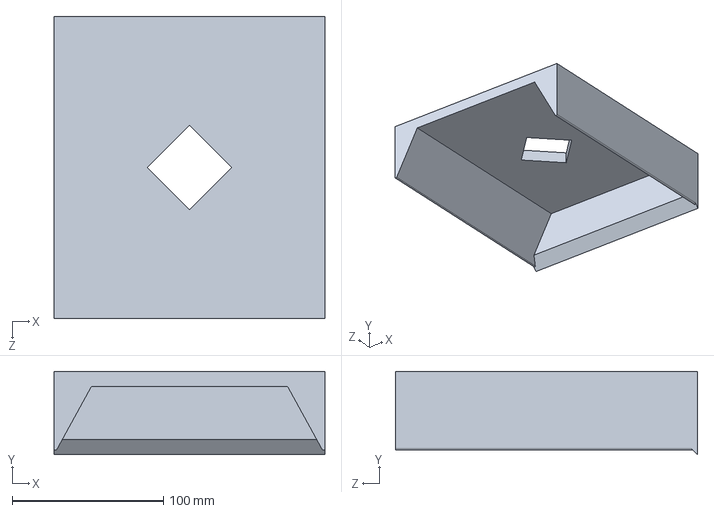
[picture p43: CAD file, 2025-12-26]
机械/风扇手柄外框/续航测试减光器.SLDPRT
179.4 x 55.0 x 200.0 mm

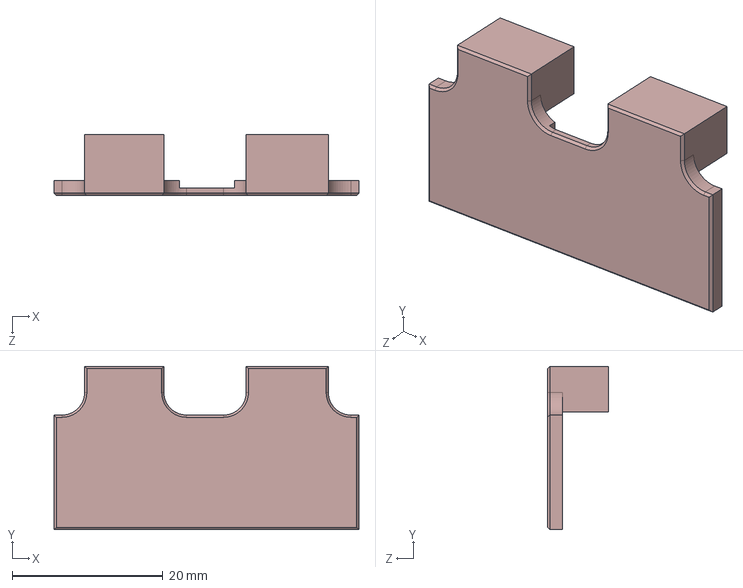
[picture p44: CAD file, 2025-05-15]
机械/驱动/驱动散热铜块.STEP
40.5 x 21.7 x 8.10 mm

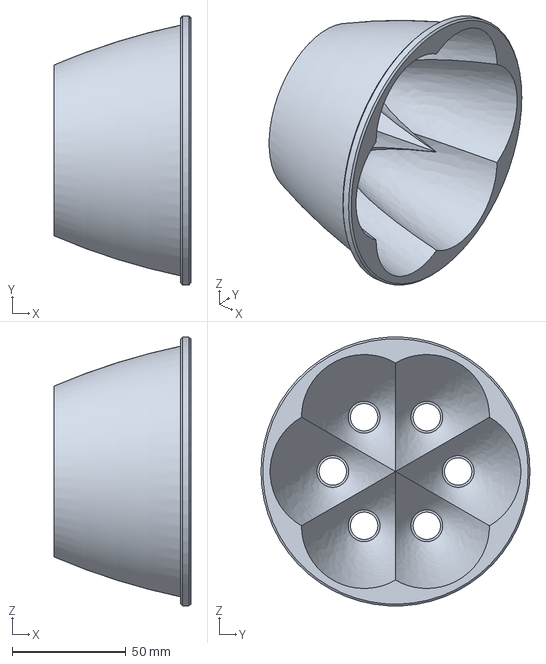
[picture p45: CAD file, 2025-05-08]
机械/光学部分/光杯和玻璃/反光杯外形尺寸.stp
60.0 x 118.0 x 117.8 mm

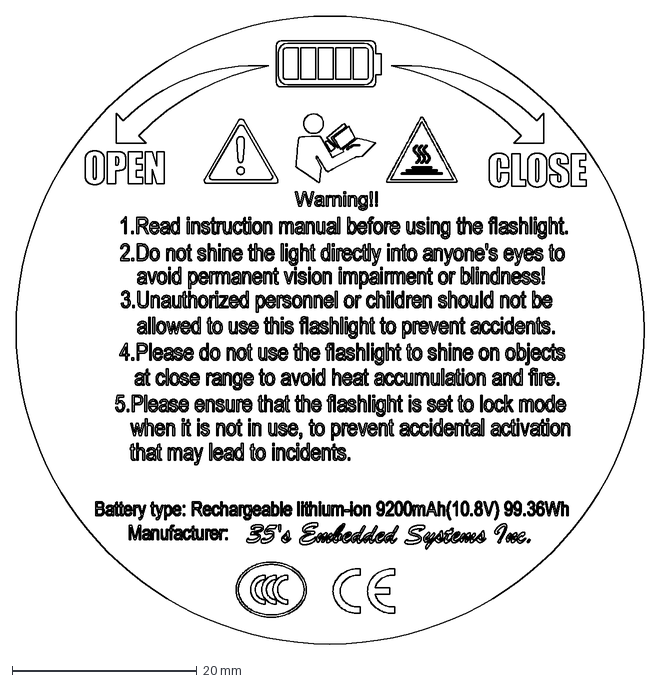
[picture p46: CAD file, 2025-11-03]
机械/激光打标文件/DXF/尾盖标识.DXF
68.0 x 68.0 mm

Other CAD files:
机械/电池架/电池架EPDM保护垫片/电池架EPDM保护垫片.DWG
机械/光学部分/专用定位片-FL7018I-ES-PA6GF.SLDPRT
机械/光学部分/定位片3D制造文件/专用定位片-FL7018I-ES-PA6GF.STEP
机械/电池架/Step/电池架均衡和充电板空隙垫圈.STEP
机械/光学部分/专用定位片-7070-尺寸精调.SLDPRT
机械/光学部分/专用定位片-7070.SLDPRT
机械/光学部分/专用定位片-7212D.SLDPRT
机械/光学部分/专用定位片-FL7018I-ES.SLDPRT
机械/光学部分/定位片3D制造文件/专用定位片-7070-PA6GF.STEP
机械/光学部分/定位片3D制造文件/专用定位片-7070.STEP
机械/光学部分/定位片3D制造文件/专用定位片-7070灯珠.3mf
机械/光学部分/定位片3D制造文件/专用定位片-7212D-PA6GF.STEP
机械/光学部分/定位片3D制造文件/专用定位片-7212D.3mf
机械/光学部分/定位片3D制造文件/专用定位片-7212D.STEP
机械/电池架/Step/显示窗.STEP
机械/电池架/Step/电池架中心柱.STEP
机械/电池架/Step/电池正极铜垫片.STEP
机械/电池架/电池架中心柱.SLDPRT
机械/电池架/电池架均衡和充电板空隙垫圈.SLDPRT
机械/电池架/电池架正极垫圈.SLDPRT
机械/电池架/电池架正极黄铜导电电极.SLDPRT
机械/电池架/电池架装配效果.SLDPRT
机械/电池架/电池正极铜垫片.SLDPRT
机械/筒身/Step/电池仓前盖.stp
机械/筒身/Step/电池仓尾盖.stp
机械/筒身/Step/电池仓尾部显示面板.stp
机械/筒身/电池仓.prt
机械/筒身/电池仓前盖.prt
机械/筒身/电池仓尾盖.prt
机械/筒身/电池仓显示面板.prt
机械/筒身/驱动压环.prt
机械/风扇手柄外框/40风扇不锈钢夹片.SLDPRT
机械/风扇手柄外框/40风扇外框23日.SLDPRT
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

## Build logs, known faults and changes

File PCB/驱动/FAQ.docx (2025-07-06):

驱动复刻调试FAQ

问题1：驱动上电后心跳LED持续快闪，侧按LED报错Fault_DCDCPreChargeFailed（侧按指示灯红黄绿交替闪，停顿0.5秒后红色闪烁7次）

解决思路：使用万用表测量驱动输出端，并上电。如果输出电压不等于14.4V，检查R32是否开路，C56是否短路，U11是否损坏。如果上述原件都正常，则给驱动重新上电，测量U11四脚是否有一个瞬间存在的约4.4-5V的电压。如果没有，则尝试为MCU（U8）重新刷写固件，仍然无效则更换U8。若预充电路正常，则检查CV环注入电阻R14，DCDC FB电阻R6、R8以及输出电压监视器的分压电阻R21、R23（可以通过上电时测量R23两端电压判断是否正常，如果R23两端电压不满足VR23=输出电压*(56/(680+56))的规律，则电阻阻值错误或者R21和R23贴反，如果R21和R23贴反则会损坏MCU内的ADC模块故需要更换U8）。

问题2：驱动在装机过程中输出意外短路冒烟，处理好短路后重新安装输出只有低亮档，其余挡位消失，开关机正常。

解决思路：驱动使用可调电源供电并开机，输出连接假负载LED，通过按键板进行换挡并使用万用表测量D4引脚1以及2的对地的电压，电压应如下表所示：

挡位 | 对应D4引脚1和2的电压
月光 | 0.0039V
极低亮 | 0.018-0.02V
低亮 | 0.09-0.1V
中亮 | 0.18-0.2V
中高亮 | 0.39-0.4V
高亮 | 0.78-0.8V
极亮 | 3.05V-3.2V(31.5A极亮) 3.65-3.72V(37A极亮)

如果D4的引脚1和2电压严重偏低，则检查D4引脚3，正常状态下应当为5V，如果电压偏低则更换U9。更换U9后仍然出现D4的引脚1和2电压严重偏低的情况，则更换MCU(U8)。

更换完毕后如果问题仍未得到解决，则测量FB注入运放U6的第一脚对地电压，如果不为0V则直接更换U5。如果为0V则测量R8电阻两端对地电压，若不为1.2V则说明DCDC部分故障，此时可尝试更换控制器U1。

问题3：驱动在上电时偶尔能正常通过自检，偶尔报错Fault_DCDCFailedToStart（侧按指示灯红黄绿交替闪，停顿0.5秒后红色闪烁1次）

解决思路：驱动使用可调电源上电，并测量电容C12两端的电压。正常值应当为6.5-6.6V。如果电压值异常，则测量辅助电源IC（U2）第三脚电压是否为0.6V，如果是则检查辅助电源反馈电阻R4、R5。如果U2第三脚电压异常，则尝试更换U2，电感L3，电容C12和C42。

更换完毕仍然无效则说明辅助电源存在短路或严重漏电，此时可以在电感L3上对地连接一个6V直流电源并观察电流，电流异常则尝试拆除U4、U3以及U1。

问题4：驱动的电量指示功能异常，例如电池明明是满电状态却提示电量过低无法开机或自动降档，或者电池已经耗尽仍然提示电量充足。

解决思路：驱动连接到12V可调电源上电，检查电阻R22两端电压是否满足VR22=电池电压*(100/(680+100))的规律。如果电压严重偏低（0-0.几V）则检查二极管D3是否焊反，U8引脚是否连锡，都正常的话更换U8。如果电压严重偏高则检查R20和R22阻值是否正确，如果电阻R22的两端电压高于2V则在更换完R20和R22后还需要更换U8，否则后期电量和温度测量可能故障。

问题5：驱动上电开机后发出刺耳的啸叫，而且输入电流巨大可调电源直接5A打表，输出的LED亮度不稳定一直频闪。

解决思路：检查DCDC部分的环路补偿原件（R7，C31，C32）以及开关频率设置电阻R9的参数是否符合原理图的配置。同时检查FB注入部分的环路补偿元器件（C77、R15、R16）的参数是否正确。如果都正常，则尝试更换U1、U6、U5。

问题6：驱动上电后没有任何反应，按下按键板尝试开机也无法开机。

解决思路：为驱动通上12V电源，使用万用表测量电容C39两端电压，正常电压应当为稳定的5V。如果没有电压，请检查并更换FB2、U7、C40和C39。仍然无效则更换MCU(U8)。如果电压正常，且更换MCU（U8）后固件仍然无法启动，则请尝试为MCU重新刷入固件，并且检查固件所对应的烧录设置（见README.md）是否匹配。当MCU内的固件正常启动时，驱动背部的固件心跳LED（D5）将会点亮。

问题7：驱动在非极亮挡位下正常工作，但开启极亮挡位时立即保护，且驱动背面某处温度极高。

解决思路：使用大功率可调电源为驱动通上12V电源，连接上LED并且让驱动开机，通过按键操作让驱动运行在高亮档。使用热成像观察主板正面的两组MOS管（Q1、Q2和Q3、Q4）的温度数据是否一致。如果某组MOS管温度严重偏低，则请使用示波器测量U1的13和24引脚的波形，正常状态下的两个引脚的波形都应该是频率为325KHz左右的方波且相位错开180度，如果观察到某一组引脚为一条直线则说明U1故障，请更换U1，如果更换U1后仍然没有波形，则说明对应的MOSFET故障，请更换MOSFET(Q1到Q4)。

问题8：驱动在关机状态下以及SOS和信标模式运行过程中的熄灭状态下能观察到LED微微发亮出现漏光/漏电现象。

解决思路：使用万用表二极管档测量Q5是否击穿，如果击穿则同时更换U3、Q5。更换Q5后如果仍然漏光，则更换U3。

问题9：驱动在其余挡位运行正常，但是在长按进入的月光挡位下亮度异常偏高，和循环挡位中的及低亮度挡位相差无几。

解决思路：长按开关使驱动运行在月光档，然后使用万用表电压档测量U9的第一脚电压。正常应该在0.003-0.005V之间，如果电压异常，则检查电阻R24 R25是否开路，C44 C45是否短路或者开路，并更换D4。电压正常的话测量U9第四脚电压，应基本和U9第一脚电压一致，如不一致则U9损坏，更换U9。

问题10：驱动焊接完毕后使用CMS ICE8 PRO调试器尝试烧录固件时认不到芯片，IDE软件提示如下错误：

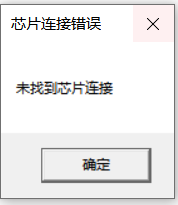
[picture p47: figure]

解决思路：首先请检查调试器的5V输出电源是否正常，并检查调试器到驱动主板上的探针定义连接是否正确（参考下图）。

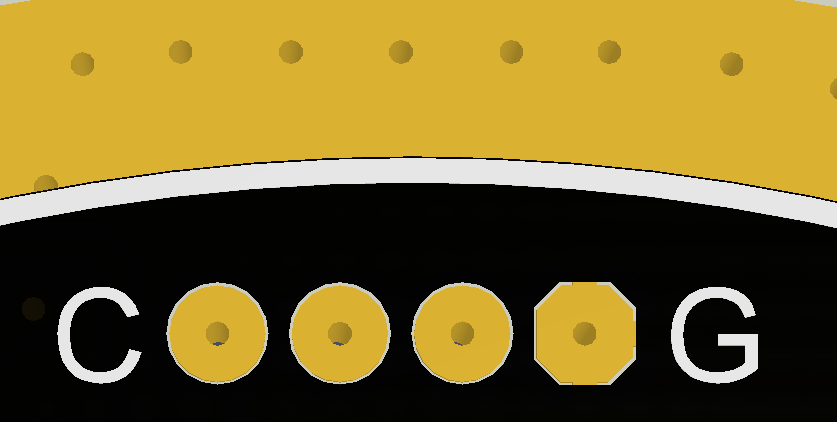
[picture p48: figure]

板子从左到右定义分别为:CLK DAT VDD GND，按照调试器上的pinout连接即可。如果仍然无效则参考如下内容：

因为驱动在电源输入内部有容量巨大的输入电容器。当调试器给芯片供电并通过U7倒灌给输入电容之后，输入电容会在调试器断开芯片电源尝试复位芯片，使进入DFU模式时持续给芯片供电导致芯片无法复位。此时您可以拔下调试器并重新连接，测量调试器输出的电源接口没有电压之后，短接以下驱动板上的按键点让驱动放电。然后在确保下载器探针定义正确且充分压紧，接触良好的情况下重新尝试下载。仍然无效则您可以拆除U7或者FB2后尝试下载，下载成功后再度焊回拆下的器件。

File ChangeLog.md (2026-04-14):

# 更新日志

## [1.3.0.10] - JAN-30-2026 09:10

### 驱动固件勘误

本次没有驱动固件勘误内容

### 电池棒控制器固件勘误

本次没有电池棒控制器固件勘误内容

### 硬件勘误

本次没有硬件勘误内容

### 电池棒固件更新

+ 调整主菜单的显示逻辑，在部分场景下自动切换为三位有效数字提升Type-C和电池电压的显示精度

### 驱动固件更新

+ 针对老王的N7-270HP（三星56.5mil核心）新增专属的电流entry入口。

### 硬件更新

本次没有硬件更新内容

### 其余更新

+ 删除部分无用的PCB预览文件

## [1.3.0.9] - JAN-30-2026 09:10

### 驱动固件勘误

本次没有驱动固件勘误内容

### 电池棒控制器固件勘误

+ 修正恒压模式判定机制的部分异常
+ 修正一键充电测容测试结果显示页面部分字体的颜色错误

### 硬件勘误

本次没有硬件勘误内容

### 电池棒固件更新

本次没有电池棒固件更新内容

### 驱动固件更新

本次没有驱动固件更新内容

### 硬件更新

本次没有硬件更新内容

### 其余更新

+ 新增手电外观标识所需的激光打标图档文件并由移动部分已有的打标图档至机械文件夹
+ 新增激光打标图档格式的说明readme
+ 删除热敏标签贴纸版本的GT96外箱标签文件

## [1.3.0.8] - JAN-23-2026 08:42

### 驱动固件勘误

本次没有驱动固件勘误内容

### 电池棒控制器固件勘误

+ 调整过充保护探测机制解决即使当前满充电压正常仍然异常下调充满电压的问题
+ 修改均衡器控制机制，在电池接近充满的阶段下禁止均衡运行以便于解决主动均衡自身误差导致电池一致性异常
+ 修改恒压模式的判定机制解决慢充场景下系统处于恒流充电阶段但仍然异常显示为恒压充电的问题

### 硬件勘误

本次没有硬件勘误内容

### 电池棒固件更新

+ 新增在低于0度的极寒环境下禁止充电以保护电池的保护功能
+ 容量测试GUI新增电池电流的显示功能以方便用户查看当前实时电池电流
+ 容量测试GUI在测试结束后新增交替显示充入Wh和Ah数的功能以便于用户查看充电结果

### 驱动固件更新

+ 调整温控参数解决在高气温环境且手电处于被动模式下温度过高触发保护的问题，优化使用体验

### 硬件更新

+ 更换驱动的主MOSFET（升压部分）由原本的AOE6936更换为VISHAY的SIZF918BDT-T1-GE3，极大程度降低上管导通损耗增加稳定性并提高系统效率。
+ 更新驱动的PCB文件针对SIZF918BDT的封装进行对应位置的开窗，增强电流承载能力。
+ 更新驱动的LTPowerCAD配置仿真文件至新的MOSFET
+ 新增驱动PCB的[Gerber文件压缩包](/PCB/%E9%A9%B1%E5%8A%A8/%E9%A9%B1%E5%8A%A8%E6%89%93%E6%A0%B7%E6%96%87%E4%BB%B6.zip)用于直接上传至JLC之类的平台进行打样。
+ 主动均衡PCB对变压器参数进行调整增大均衡电流并对均衡自身误差做优化。
+ 更新主动均衡的均衡变压器制造图纸，新增实物参考照片和特殊要求。

### 其余更新

+ 对风扇手柄对应的转接块进行重新设计，增强手感并更换材料至7075以获得更高的强度。
+ 更新电池棒控制器固件的readme，增添低温保护对应的警告代码
+ 新增均衡PCB的调试FAQ和调试说明。

## [1.3.0.7] - JAN-01-2026 14:05

**元旦快乐！2026新年新气象！祝各位开开心心！**

### 驱动固件勘误

+ 调整驱动的温控参数使得驱动在极亮挡位降档后的运行更稳定，常亮性能更高。
+ 修复极亮电流获取逻辑中的逻辑错误导致在开启POWER模式时错误的返回ECO模式的电流配置使得极亮无法正常全功率运行的bug

### 电池棒控制器固件勘误

本次没有电池棒控制器固件勘误内容

### 硬件勘误

本次没有硬件勘误内容

### 电池棒固件更新

本次没有电池棒控制器固件更新内容

### 驱动固件更新

+ 锁定模式下在触发显示电压后新增按键操作忽略的处理，避免在显示期间误操作导致电压显示被打断。
+ 更新固件的编译时间戳至`20251229-11:29`

### 硬件更新

本次没有硬件更新内容

### 其余更新

+ 新增电池棒前部不锈钢保护盖的3D Step文件。

## [1.3.0.6] - DEC-26-2025 10:05

### 驱动固件勘误

本次没有驱动固件勘误内容

### 电池棒控制器固件勘误

本次没有电池棒控制器固件勘误内容

### 硬件勘误

本次没有硬件勘误内容

### 电池棒固件更新

本次没有电池棒控制器固件更新内容

### 驱动固件更新

+ 锁定模式功能调整，在锁定模式下用户可以紧急运行月光挡位或者查询电池电压而无需解锁，方便用户操作。
+ 新增具备一键反击远光傻*功能以及一键灭灯的走夜路挡位。
+ 调整输出通道状态机的部分参数提高爆闪斜率。
+ 更新用于描述驱动系统默认设置的[设置头文件](/%E5%9B%BA%E4%BB%B6/%E9%A9%B1%E5%8A%A8%E5%9B%BA%E4%BB%B6/include/Middleware/DefaultConfiguration.h)添加设置系统四击和六击操作逻辑的设置项。
+ 更新固件的编译时间戳至`20251226-10:05`

### 硬件更新

+ 更新驱动的LTPowerCAD仿真文件，修改功率MOS管至Vishay的MOS。

### 其余更新

+ 更新风扇手柄的固件，新增锁定模式下允许双击+长按查看电压的功能方便用户在长期放置时检查电池电量。
+ 更新驱动的readme文件添加新增的操作逻辑的说明描述。
+ 新增续航测试所用的减光滤镜的3D制造文件。

## [1.3.0.5] - DEC-20-2025 14:04

### 驱动固件勘误

+ 修复手电在长时间静置后三击直接开启爆闪时概率出现的LED无法点亮，约2秒后报告`Fault_DCDCFailedToStart`错误的问题。
+ 修复手电在设置菜单内进入特定设置项（除有源夜光和电流拖尾特效）时指示灯会错误红色闪烁的bug

### 电池棒控制器固件勘误

+ 修复IP2366底层寄存器驱动异常导致涓流充电电流设置无效的bug

### 硬件勘误

本次没有硬件勘误内容

### 电池棒固件更新

+ 更新电池棒固件版本号至`V1.5 Build 12`

### 驱动固件更新

+ 在极亮LED电流配置头文件内将旧版本NBT160的额定电流值调整为28A，恢复到以往的固件配置。
+ 删除掉极亮LED电流配置头文件内实际硬件无法承受的`USING_LED_FL7018I_PRO9`预设。
+ 调整FV7011I和NBT160灯珠的1LM挡位额定电压调整亮度值。
+ 对固件源代码进行大幅度的规范化整理新增每个源文件的文件头以描述代码的功能注释,方便后续代码的移植。
+ 新增在固件编译时以编译信息的方式打印当前固件选择的系统配置和LED类型的输出系统。
+ 针对新增的FV7011I LED在固件源码的[极亮参数自动配置头文件](/%E5%9B%BA%E4%BB%B6/%E9%A9%B1%E5%8A%A8%E5%9B%BA%E4%BB%B6/include/Hardware/TurboICCMAX.h)内增加对应的entry。
+ 新增用于描述驱动系统默认设置的[设置头文件](/%E5%9B%BA%E4%BB%B6/%E9%A9%B1%E5%8A%A8%E5%9B%BA%E4%BB%B6/include/Middleware/DefaultConfiguration.h)以及自动处理设置并生成配置函数的自动Parse系统，允许用户根据需要修改驱动出厂的配置。
+ 更新固件的编译时间戳至`20251219-13:35`

### 硬件更新

本次没有硬件更新内容

### 其余更新

+ 调整gitignore文件以允许上传源代码的丢失的uvprojx文件（keil源代码工程的项目文件）。
+ 调整gitignore文件以禁止上传PCB工程的预览文件。

## [1.3.0.4] - DEC-17-2025 09:03

### 驱动固件勘误

本次没有驱动固件勘误内容

### 电池棒控制器固件勘误

+ 修复在系统处于充电过程中更改系统设置后，触发IP23266固件永久性死机（重新安装电池才能解决）的bug

### 硬件勘误

本次没有硬件勘误内容

### 电池棒固件更新

本次没有电池棒固件更新内容

### 驱动固件更新

本次没有驱动固件更新内容

### 硬件更新

本次没有硬件更新内容

### 其余更新

+ 对连接到东东海F1A风扇手柄的铝合金固定块进行外形优化，解决固定块使用时卡手指，握持不舒服的问题
+ 对风扇手柄固定块的3D图和2D公差图进行重新导出的操作，并针对实际情况进行公差调整。

## [1.3.0.3] - DEC-09-2025 09:03

### 驱动固件勘误

本次没有驱动固件勘误内容

### 电池棒控制器固件勘误

+ 修正在系统电池彻底放空时进行容量测试的过程中，切换IP2366进行快速充电的过程中概率性出现容量测试异常中断的bug
+ 修正[软件I2C驱动的C语言代码文件](/%E5%9B%BA%E4%BB%B6/%E7%94%B5%E6%B1%A0%E6%A3%92%E6%8E%A7%E5%88%B6%E5%99%A8%E5%9B%BA%E4%BB%B6/Hardware/I2CDrv.c)的编码格式错误配置为UTF-8而非LCD字库系统所支持的GB-2312导致I2C驱动的错误输出信息显示异常的bug。
+ 修正系统在电池包保护后启动到安全模式时，适配器无法正确退出快充模式始终输出高压，导致系统自检失败的bug
+ 修正GUI框架中数值编辑菜单对于包含负数值的参数输入响应异常的bug

### 硬件勘误

本次没有硬件勘误内容

### 电池棒固件更新

+ 测量系统配置内新增针对系统温度测量点进行校准的功能
+ 系统安全设置内新增在特定情况下可以关闭自动均衡修正（电池包累计充放电一定电量后自动对电池进行均衡的功能）的设置开关
+ 容量测试系统新增分阶段充电时长统计功能，可以分别记录系统在涓流充电、恒流充电和恒压充电阶段的时长。

### 驱动固件更新

本次没有驱动固件更新内容

### 硬件更新

+ 针对量产版本的NBT160.3（7070封装版本）更新3V铜基板内PCB封装的3D模型，和实物匹配。

### 其余更新

+ 补齐机械部分因转移文件时失误导致丢失的驱动固定压环的3D制造文件
+ 补齐机械部分readme中关于压环加工螺纹参数的说明

## [1.3.0.2] - NOV-14-2025 16:00

### 驱动固件勘误

本次没有驱动固件勘误内容

### 电池棒控制器固件勘误

+ 修正自动补充均衡会导致IP2366进入永久性死机，不充不放需要拔电池复位芯片的bug。
+ 修正自动根据容量设置预充电电流的菜单中的字符显示过于靠上的问题。
+ 修正自动根据固件状态配置系统的低压保护/涓流转恒流电压的函数未正确生效的bug。
+ 修正自检过程中进行ADC初始测量的逻辑，解决在每次上电时电池实时电压数字显示偏高一小会的bug。

### 硬件勘误

本次没有硬件勘误内容

### 电池棒固件更新

+ 新增在2366出现死机异常不充不放（状态卡死在充电或者放电但是vbus没有输入输出）时发送EN-ResetMCU命令复位2366的逻辑。
+ 删除掉字库内并未使用的ASCII-1608字体节省ROM空间
+ 查看历史测容数据内新增根据测得的Wh数根据3.6V标称电压换算出的等效容量显示。
+ 自动补充均衡新增强制退出后本次开机不会再自动进入的功能。
+ 调整高精度功率计（INA226）的上电POST逻辑，解决特定场景下功率计硬件正常但自我测试结果错误的问题。
+ 优化一键测容菜单的电池电压显示逻辑。在电池电压小于10V时使用2位小数显示，当电池电压大于10V时使用1位小数并四舍五入显示。解决电池电压在接近充满时仍显示为12.5令用户误以为电池未满的问题。

### 驱动固件更新

+ 针对新版改进后的NBT160.3灯珠的配置调整极亮电流至34A
+ 针对新版改进后的NBT160.3灯珠的配置调整LED开路的判定电压点至22.8V，避免因灯珠Vf过高引起误判。
+ 针对新版改进后的NBT160.3灯珠的配置新增一组1LM超低亮挡位的电压配置，确保灯珠能正确点亮。

### 硬件更新

+ 新增针对改进后的7070封装NBT160.3灯珠的3V6串全串联配置的铜基板的打样文件和单板工艺要求说明文件
+ 删除铜基板PCB文件夹内的多余文件

### 其余更新

+ 更新铜基板打样readme，添加关于3V六串配置的说明。
+ 新增适配NBT160 7070封装的专用定位片的制造文件（该文件需要3D打印厂家进行进行尺寸调试和补偿才可以达到尺寸要求）

## [1.3.0.1] - NOV-04-2025 14:54

### 驱动固件勘误

本次没有驱动固件勘误内容

### 电池棒控制器固件勘误

+ 修正电池棒低压保护设置部分中`3.2V（3200mV）`的选项无法正确生效的问题。

### 硬件勘误

本次没有硬件勘误内容

### 电池棒固件更新

+ 新增独立的涓流转恒流电压的设置选项。允许用户根据电池特性设置涓流电压（在电池严重亏电阶段以小电流对电池缓慢充电激活直到电池达到一定电量水平再进行全功率充电）以保护电池。
+ 新增根据容量测试数据设置涓流阶段充电电流至0.1C倍率的自动设置功能，让用户无需手动根据电池容量计算涓流充电电流。
+ 将GUI中显示`按下ESC以退出`字符串的部分统一改为使用`ShowPressExitToLeave()`函数进行复用，节约大量ROM空间。

### 驱动固件更新

本次没有驱动固件更新内容

### 硬件更新

本次没有硬件更新内容

### 其余更新

+ 更新Readme新增风扇手柄DLC相关的说明。
+ 更新Readme新增复刻成本相关的说明。
+ 更新Readme章节中的复刻电池选择部分，新增2025年推出的瑞恩RS50和天鹏50XG的选择建议。
+ 更新电池棒控制器固件readme新增数值编辑类菜单的说明。

## [1.3.0.0] - NOV-03-2025 11:58

### 驱动固件勘误

本次没有驱动固件勘误内容

### 电池棒控制器固件勘误

本次没有电池棒控制器固件勘误内容

### 硬件勘误

本次没有硬件勘误内容

### 电池棒固件更新

本次没有电池棒固件更新内容

### 驱动固件更新

本次没有驱动固件更新内容

### 硬件更新

+ 新增支持全反接保护以及带蜂鸣警示功能的同口充放电保护板（在造价高60%的情况下，换来即使所有电池装反并尝试强制给驱动上电时也能保护驱动不会损毁）
+ 新增充电板负极到保护板之间的一次性熔断保险模块板（在充电板出现致命异常，如电容和MOS击穿时立即熔断切断电路，并阻止PCB进一步碳化烧毁）
+ 移除旧版本存在设计缺陷的分口保护板的工程文件并进行加密归档。 **该旧版保护板在所有电池装反的情况下不能保护驱动，仅能保护电池架自身。在所有电池全部装反时如果强行组装好电池棒并旋入手电本体会立即烧毁驱动！强行使用后果自负！**

### 其余更新

+ 完成实验性分支的所有功能测试，并将该分支并入主分支内。

## [1.2e.0.5] - OCT-23-2025 14:26

### 实验性分支，功能暂未进行验证！请等待合并到主分支之后再进行更新处理。

### 驱动固件勘误

本次没有驱动固件勘误内容

### 电池棒控制器固件勘误

+ 修复清空库仑计数据功能未对日志系统数据库缓存进行修复重构的逻辑问题（会导致清空库仑计数据后开机报数据库异常错误）
+ 修复自动省电功能在生效时断开C口连接，导致一键充电测容功能异常结束（即使C口适配器未拔除）或反复二次充电导致充电时长和容量数据异常偏高的问题

### 硬件勘误

本次没有硬件勘误内容

### 电池棒固件更新

本次没有电池棒固件更新内容

### 驱动固件更新

本次没有驱动固件更新内容

### 硬件更新

本次没有硬件更新内容

### 其余更新

+ 对电池架正极铜触点下方的3D打印垫片进行尺寸调整，解决3D树脂打印件尺寸正公差导致无法装配的问题

## [1.2e.0.4] - SEP-19-2025 16:37

### 实验性分支，功能暂未进行验证！请等待合并到主分支之后再进行更新处理。

### 驱动固件勘误

本次没有驱动固件勘误内容

### 电池棒控制器固件勘误

+ 修复数值编辑类菜单在进入后首次操作无响应，强制退出时屏幕频闪的问题
+ 通过对Type-C模式硬设定的调整，修复导致仅充电模式出现异常的bug
+ 修复设置了电池电压和电流校准数值后相应的校准数值并未立即生效，需要重启后生效的bug
+ 修复充放电功率设置菜单在特定极端情况下出现选项选择异常无法操作并引起固件卡死的隐性bug
+ 修复特定场景下中文字库因字体素材未取模和导入字库，导致该场景内提示字符串显示异常的bug

### 硬件勘误

+ 修复风扇手柄驱动的电子防反接失效导致电池反向安装时引起烧毁的问题

### 电池棒固件更新

+ 新增在电池充满结束后20秒自动关闭快充协商，返回至5V充电降低适配器功耗的自动省电模式
+ 新增输入快充协议的设置选项允许用户设置输入支持的快充协议
+ 新增在充电开始时检测起始温度并动态设置充电功率的自适应温度保护功能。可以避免手电使用后立即充电导致电池过热。
+ 新增最大输入充电功率设置允许用户根据需要独立设置充电功率
+ 新增输入模式下查询适配器报告的PDO支持电压的功能。

### 驱动固件更新

+ 优化驱动在使用主动散热风扇手柄情况下的升档策略提高常亮性能
+ 更新驱动固件的时间戳至`20250821-1120`。

### 硬件更新

+ 新增针对东东海F1A风扇手柄的2.4A电流双向C口充电板的原理图和PCB制造文件
+ 对风扇手柄驱动进行元器件参数的调整，支持2S锂电输入驱动更高功率的风扇
+ 新增电池包外壳尾盖打标的3D和2D图档用于搭配激光打标机实现尾盖打标

### 其余更新

+ 更新IP2366定制固件以适配电池棒控制器新增的功能
+ 新增风扇手柄固件的操作逻辑和电池配置readme
+ 更新驱动的readme添加关机状态下按住按钮上电恢复出厂设置的相关描述
+ 对风扇手柄固件进行更新，新增**双锂模式、掉电不清除的永久性运输安全锁和可选的侧按有源夜光配置**。
+ 对电池架均衡和充电板之间的3D打印装饰垫圈进行尺寸调整，适配新版充电板

## [1.2e.0.2] - AUG-18-2025 14:05

### 实验性分支，功能暂未进行验证！请等待合并到主分支之后再进行更新处理。

### 驱动固件勘误

本次没有驱动固件勘误内容

### 电池棒控制器固件勘误

+ 修复容量测试模式下允许充电电压错误的问题。
+ 修复控制器在电池电压异常且使用C to C充电头时反复重启，无法正常启动的问题

### 硬件勘误

+ 修正C口强制取电电路有时候无法生效的问题
+ 解决电池电压异常时连接5V适配器尝试充电时，CM/S模块无法正常工作，屏幕显示异常的问题

### 电池棒固件更新

+ 针对V1.3a充电板新增的CC硬件切换电路增加额外的底层驱动控制
+ 适配器模拟功能新增强制输出模拟USB A to C线缆的功能，支持为仅能使用AC线进行充电的设备充电
+ 新增电池电压异常时的安全充电模式，解决在电池电量极低保护板锁死后使用C to C充电头无法为电池棒充电的问题。

### 驱动固件更新

本次没有驱动固件更新内容

### 硬件更新

+ 新增适配于东东海F1A风扇手柄的驱动板的PCB文件
+ 对电池架充电板进行完善，增加用于锁存切换CC线路径实现安全模式和硬件仅充电功能的磁保持继电器和配套的驱动电路。
+ 更新电池架充电板的版本号至V1.3a

### 其余更新

+ 适配于东东海F1A风扇手柄的驱动板固件源代码以及操作UI流程图
+ 新增东东海F1A风扇手柄所配套的风扇固定件和不锈钢片的机械加工模型
+ 新增适配手电筒身和风扇手柄的连接件的3D模型和加工的2D图纸文件

## [1.2e.0.1] - AUG-7-2025 16:05

### 实验性分支，功能暂未进行验证！请等待合并到主分支之后再进行更新处理。

### 驱动固件勘误

+ 修正系统启动逻辑在少数情况下输出电压检测异常导致即使硬件正常，启动也无法成功的bug
+ 重新编写电池电量转换FSM加入动态阈值机制解决极亮异常黄灯问题
+ 通过优化电池电压和温度播报状态机解决7击进入设置菜单时先导提示红黄绿和绿黄红会随机变换的问题。
+ 调整输出通道状态机的软关机放电阈值，解决在高亮挡位运行后开启低亮或者月光会因为输出电容的剩余储能产生高亮度闪烁的问题。

### 电池棒控制器固件勘误

+ 修复控制器自检屏幕的ID显示异常的问题

### 硬件勘误

+ 修正电池架充电板内层1的布线stub问题

### 电池棒固件更新

+ 调整自检动画的延时参数提高自检进度条流畅度

### 驱动固件更新

+ 更新驱动固件的时间戳至`20250807-1618`。
+ 将负责进行电池电压确认的函数从[BattDisplay.c](/%E5%9B%BA%E4%BB%B6/%E9%A9%B1%E5%8A%A8%E5%9B%BA%E4%BB%B6/Logic/BattVoltDisplay.c)移动到输出通道控制的相关源代码文件[OutputChannel.c](/%E5%9B%BA%E4%BB%B6/%E9%A9%B1%E5%8A%A8%E5%9B%BA%E4%BB%B6/Hardware/OutputChannel.c)内和输出通道试运行合并降低代码占用。

### 硬件更新

本次没有硬件更新内容

### 其余更新

+ 暂时删除驱动固件文件夹内的预编译固件，等到功能测试完毕后再进行更新。

## [1.2e.0.0] - AUG-5-2025 15:10

### 实验性分支，功能暂未进行验证！请等待合并到主分支之后再进行更新处理。

### 驱动固件勘误

本次没有驱动固件勘误内容

### 电池棒控制器固件勘误

本次没有电池棒控制器固件勘误内容

### 硬件勘误

+ 修正电池架充电板部分电容的耐压值不足的问题。
+ 修正电池架充电板的C口封装，将SBU1/SBU2引脚改为焊盘增加结构强度。
+ 修正电池架充电板原理图内针对开源版本对IP2366外围MOSFET和驱动匹配电路进行料件替换的操作指示缺失的问题。

### 电池棒固件更新

+ 新增针对新版本充电板硬件的C口强制输出诱骗电路和电源管理电路的底层驱动
+ 适配器模拟菜单功能针对新版硬件新增USBA to USBC线缆模拟功能，允许用户通过C对C线为任何C口设备充电。
+ 新增针对新版本充电板的电源管理控制模块，在允许的情况下使用buck电路从C口降压为屏幕供电极大降低屏幕小板LDO发热量
+ 重构固件内针对IP2366固件功能的获取方式，由原来的根据ID匹配，改为根据读回的固件ID查表进行匹配处理获取固件配置，提高灵活性。
+ 对系统自检进程模块的自检代码进行规范化处理，并新增自检状态代码的[描述文件](/%E5%9B%BA%E4%BB%B6/%E7%94%B5%E6%B1%A0%E6%A3%92%E6%8E%A7%E5%88%B6%E5%99%A8%E5%9B%BA%E4%BB%B6/GUI/ErrorCode.txt)允许用户针对系统显示的代码进行查看以确定系统自检的状态。
+ 修改系统的充放电功率设置菜单逻辑，改为根据系统配置和固件报告的充放电功率能力动态配置并生成菜单项。
+ 查看芯片状态菜单针对新版IP2366固件的功能，增加额外的IP2366芯片硬件版本和温度数据的查看选项。
+ 对高精度功率计的自我测试额外安排和IP2366读回数据的对比增强自检结果可信度

### 驱动固件更新

+ 调整驱动的低电压保护逻辑优化电量指示功能
+ 驱动的电压查询加入四舍五入功能，提高在10V及以上电池电压时的显示精度（由±0.1v优化为±0.05V）

### 硬件更新

+ 电池棒充电板新增C口强制输出诱骗电路，解决适配器模拟模式需要用户手动连接负载以开启该功能的问题。
+ 电池棒充电板新增电源直通和BUCK降压电路，在高输入电压快充时，使用BUCK电路为屏幕供电极大降低CM/S小板的LDO发热
+ 电池棒充电板背部新增额外的滤波电容的焊接丝印标识提示用户焊接额外的电解电容降低输出纹波
+ 更新电池棒充电板的PCB版本号至V1.3。

### 其余更新

+ 更新电池棒控制器固件的Readme文件新增关于自我测试输出代码的描述部分
+ 针对ES版本的FL7018I灯珠所对应的定位片增加了针对PA6-GF材料打印的专用3D模型。
+ 修正FL7018I灯珠所对应的定位片(普通材料版本)的3D模型文件中部分尺寸错误导致定位片和灯珠配合间隙过大的问题。

## [1.2.0.4] - JUL-28-2025 13:15

### 驱动固件勘误

本次没有驱动固件勘误内容

### 电池棒控制器固件勘误

+ 修复手动启动均衡菜单在选择均衡10小时以上时，时间数字显示异常的bug
+ 修复在设置菜单内长时间放置无操作，自动关机后对设置所做的更改全部丢失的bug（特定情况下会导致系统无法启动）
+ 修复在面向普通用户的设置菜单内退出菜单时，设置不会保存的bug
+ 修复日志系统commit条件设置异常导致EEPROM的日志存储区域异常磨损的问题

### 硬件勘误

本次没有硬件勘误内容

### 电池棒固件更新

+ 重写日志系统增加index缓存，在不影响日志系统功能的前提下极大优化开机速度。
+ 新增类似企业级设备的手动/自动设置保存功能以及双配置存储区（一份主配置一份备用配置互为镜像实现冗余）,支持互相备份和还原。
+ 出厂设置恢复改为独立入口，避免用户执行时覆盖掉C口校准数据和部分安全设置
+ Type-C接口电流检测新增独立的充放电分离校准解决INA226在充放电时因为电流路径不一致所需的校准值不一致的问题。
+ 修改系统固件默认的存储配置为FM24C512D，支持更大的日志存储空间降低磨损。
+ 修改手动启动均衡的均衡实现上限到16小时
+ 新增对日志系统数据库进行校验和数据修复的菜单选项
+ 查看芯片状态菜单内新增额外的外部存储器相关的数据查看项

**特别注意！该更新的固件为非兼容更新，不兼容以往的电池棒控制小板（CM/S）硬件。强行刷入会导致开机报错或者运行异常！需要更换板子正面的EEPROM至FM24C512D。**

### 驱动固件更新

本次没有驱动固件更新内容

### 硬件更新

+ 更新电池棒控制小板（CM/S模块）的数据存储EEPROM至FM24C512D适配新版硬件
+ 在电池棒控制小板（CM/S模块）的原理图和BOM文件内新增复刻时替代料应用相关的警告（不允许使用其他型号的EEPROM代替，否则程序无法启动。）

### 其余更新

+ 新增适用于ES版本FL7018I灯珠的专属定位片的3D制造文件
+ 更新电池棒控制器固件内的hex文件到最新源码build（V1.5 Build 2）的产物

## [1.2.0.3] - JUL-23-2025 16:03

### 驱动固件勘误

本次没有驱动固件勘误内容

### 电池棒控制器固件勘误

+ 修复自动均衡菜单在特定情况下UI不刷新导致均衡实际已完成但是屏幕上显示仍未完成的bug
+ 修复退出快捷菜单时提示用户拔除Type-C的提示即使在用户没有对快捷菜单设置进行更改的情况下仍然弹出的bug
+ 修复查看芯片状态菜单显示的外存储器已使用容量异常的bug

### 硬件勘误

本次没有硬件勘误内容

### 电池棒固件更新

+ 新增设置电池棒待机模式允许用户选择电池棒控制工作在充电宝模式（此模式下待机功耗增大，但是可以实时响应纯受电设备的插入并立即唤醒，无需按按键唤醒屏幕）的功能

### 驱动固件更新

+ 移除基本不会使用的四击+长按在其余任意挡位下进入月光的隐藏操作
+ 新增固件编译时间戳查看模块，允许用户确认当前手电搭载的固件版本
+ 新增爆闪功能的工作模式选择（16Hz固定频率高频爆闪或随机变频爆闪）
+ 固件启动时新增电池电压检查，确保驱动由电池供电，电压稳定后才对EEPROM进行读写。解决烧录器烧写结束，芯片启动时因供电不稳导致EEPROM数据写入失败或者数据不完整的问题。

### 硬件更新

本次没有硬件更新内容

### 其余更新

+ 在驱动固件工程文件夹内新增预编译好的二进制执行体文件方便搭建不了编译环境的用户可以直接烧录
+ 更新驱动的readme文件增加固件时间戳查看的操作指引
+ 更新驱动的readme文件增加固件编译环境的注意事项
+ 更新电池棒控制器固件内的hex文件到最新源码build（V1.4 Build 1）的产物

## [1.2.0.2] - JUL-21-2025 14:35

### 驱动固件勘误

本次没有驱动固件勘误内容

### 电池棒控制器固件勘误

+ 修复库仑计重置出厂设置的功能在特定情况下失效的bug

### 硬件勘误

本次没有硬件勘误内容

### 电池棒固件更新

+ 增加退出快捷菜单之后如果USB-Type C处于连接状态时提示用户断开连接的提示窗口，变相解决退出快捷菜单，系统重新配置后充电功能异常没有电流的bug
+ 查看芯片状态菜单新增外存储器（EEPROM）的状态显示
+ 库仑计统计模块新增TYpe-C最大电流和最大功率统计功能

### 驱动固件更新

本次没有驱动固件更新内容

### 硬件更新

本次没有硬件更新内容

### 其余更新

+ 新增电池棒控制器的固件操作指引readme
+ 更新电池棒控制器固件内的hex文件到最新源码build的产物

## [1.2.0.1] - JUL-19-2025 15:09

### 驱动固件勘误

本次没有驱动固件勘误内容

### 电池棒控制器固件勘误

本次没有电池棒控制器固件勘误内容

### 硬件勘误

+ 修正电池架均衡PCB的项目文件中提供的变压器图纸和原理图的绕组错误问题

### 电池棒固件更新

本次没有电池棒固件更新内容

### 驱动固件更新

+ 调整降档指示机制，在亮度明显下降时才显示降档触发避免给用户造成误导

### 硬件更新

+ 在机械文件夹内新增电池架均衡和充电PCB之间的FDM打印的[保护罩](./%E6%9C%BA%E6%A2%B0/%E7%94%B5%E6%B1%A0%E6%9E%B6/Step/%E7%94%B5%E6%B1%A0%E6%9E%B6%E5%9D%87%E8%A1%A1%E5%92%8C%E5%85%85%E7%94%B5%E6%9D%BF%E7%A9%BA%E9%9A%99%E5%9E%AB%E5%9C%88.STEP)，遮蔽电池架顶部PCB的内部元器件和走线提高电池架美观度。

### 其余更新

+ 修正驱动PCB文件夹内的自述文件的部分内容重复和错误问题

## [1.2.0.0] - JUL-18-2025 19:40

### 驱动固件勘误

+ 修复极亮温度控制过冲严重的bug

### 电池棒控制器固件勘误

本次没有电池棒控制器固件勘误内容

### 硬件勘误

本次没有硬件勘误内容

### 电池棒固件更新

本次没有电池棒固件更新内容

### 驱动固件更新

+ 彻底重写换挡状态机系统改为事件表驱动架构省出大量空间
+ 对操作逻辑进行修改增大日常使用和配置操作的分离度提高使用便捷度
+ 新增三击+长按启动温度查询的功能
+ 将原本固件内的设置项统一为七击进入设置菜单入口方便用户配置
+ 新增调整极亮挡位的冬天/夏天模式允许用户根据环境温度调整极亮的温度控制配置，提高使用体验
+ 新增常规挡位和特殊功能挡位的挡位记忆配置选项
+ 新增关机状态下按住按钮上电恢复出厂设置的功能
+ 新增片内EEPROM校验错误的提示机制（侧按指示灯以红色快速闪烁2.5秒后系统重启）

### 硬件更新

+ 修改驱动Boost控制器的检流电阻至0.9mR（通过R001和R010叠放焊接实现）将输入限流解锁到55A，提高驱动的输出性能上限并增大恒流区间。
+ 更新驱动硬件部分的[升压芯片外围仿真文件](/PCB/%E9%A9%B1%E5%8A%A8/%E9%A9%B1%E5%8A%A8%E9%85%8D%E7%BD%AE%E4%BB%BF%E7%9C%9F.ltpc)至最新的结果和硬件更改同步。

### 其余更新

+ 修改固件的编译配置打开Register Packing和LInker Code Packing提高代码压缩比节省空间。
+ 删除预编译的驱动固件文件
+ 针对驱动部分的UI逻辑更改在驱动的Readme增加相关章节并更新操作UI图示
+ 在驱动的readme内增加调试操作的指引
+ 修正140W 3S IP2366固件所对应的[寄存器手册](./%E5%9B%BA%E4%BB%B6/IP2366%E5%9B%BA%E4%BB%B6/IP2366_I2C_140W_2M50_REG.xlsx)中部分寄存器名称的描述错误

## [1.1.0.3] - JUL-10-2025 13:12

### 驱动固件勘误

+ 修复爆闪和信标模式下在极少数情况下会意外触发开路保护的bug
+ 修复从正常挡位关机后立马进入1LM超级省电挡位时亮度会出现突变的闪烁的bug

### 电池棒控制器固件勘误

+ 修复电池棒在进行二次补充电时均衡并未强制打开的问题

### 硬件勘误

本次没有硬件勘误内容

### 电池棒固件更新

+ 查看芯片状态菜单下新增电子的均衡指示灯功能，可以查看主动均衡模块是否被启用。

### 驱动固件更新

+ 随机爆闪功能加入使用ADC测量的寄存器数值作为算法的随机种子，极大增强随机爆闪功能的随机性。
+ 增加月光挡位下单击+长按回到超低省电挡的功能
+ 增加超低省电挡下长按进入正常月光挡位的功能
+ 将驱动触发电池性能不足保护的阈值修改为按照极亮电流的百分比计算。
+ 对[极亮电流设置头文件](./%E5%9B%BA%E4%BB%B6/%E9%A9%B1%E5%8A%A8%E5%9B%BA%E4%BB%B6/include/Hardware/TurboICCMAX.h)中`FV7212D`和`FL7018I`LED对应的电流进行修改提高性能。
+ 将信标脉冲闪的频率由原来的2秒一次改为3秒一次

### 硬件更新

本次没有硬件更新内容

### 其余更新

+ 更新驱动readme添加本次新增的回到超低省电挡位和进入月光挡位的功能
+ 更新驱动固件的二进制执行体到最新时间戳(20250710)
+ 新增魔改版本140W 3S IP2366固件所对应的[寄存器手册](./%E5%9B%BA%E4%BB%B6/IP2366%E5%9B%BA%E4%BB%B6/IP2366_I2C_140W_2M50_REG.xlsx)供二次开发参考。

## [1.1.0.2] - JUL-08-2025 10:21

### 驱动固件勘误

本次没有驱动固件勘误内容

### 电池棒控制器固件勘误

+ 修复电池棒自动补充均衡功能未正确生效的问题

### 硬件勘误

本次没有硬件勘误内容

### 电池棒固件更新

+ 在电池棒开发者菜单内增加进入到自动补充均衡的入口用于特定情况下启动自动均衡
+ 修改自动补充均衡的逻辑为`一次充电->断电均衡五小时->二次补电->均衡结束`来解决自动均衡后电池电量会被均衡电路的自耗电损耗掉一部分导致电池实际并未完全充满。

### 驱动固件更新

本次没有驱动固件更新内容

### 硬件更新

本次没有硬件更新内容

### 其余更新

+ 更新电池棒控制器文件夹内的[固件文件](./%E5%9B%BA%E4%BB%B6/%E7%94%B5%E6%B1%A0%E6%A3%92%E6%8E%A7%E5%88%B6%E5%99%A8%E5%9B%BA%E4%BB%B6/%E7%94%B5%E6%B1%A0%E6%A3%92%E6%8E%A7%E5%88%B6%E5%99%A8%E5%9B%BA%E4%BB%B6.hex)至最新的源代码build产物（V1.3 Build 7）

## [1.1.0.1] - JUL-06-2025 10:21

### 驱动固件勘误

+ 修复输出模块预充启动逻辑异常导致固件在非月光和低亮挡位无法启动到正常输出状态的问题
+ 修复爆闪模式进入前记忆功能逻辑错误导致从爆闪模式下关机后记忆挡位错误的被覆写为爆闪模式的问题

### 电池棒控制器固件勘误

本次没有电池棒固件勘误内容

### 硬件勘误

本次没有硬件勘误内容

### 电池棒固件更新

本次没有电池棒固件更新内容

### 驱动固件更新

+ 调整驱动的输入MPPT告警阈值解决输入MPPT告警机制过于敏感，在极亮不影响人眼观感但是降低功率的情况下也报错的问题。
+ 对`turboICCMax.h`内预定义的几种LED极亮和爆闪电流进行细微的调整以充分释放LED的潜力

### 硬件更新

本次没有硬件更新内容

### 其余更新

+ 删除基本没有人会用到的驱动固件批量烧录设置文件（CMS_WRITER V8价格及其昂贵，用不上）
+ 对驱动预编译的固件文件进行更新和扩充，新增多种灯珠对应的固件文件
+ 修正changelog内部分书写错误和漏掉的更新内容
+ 更新驱动的调试FAQ增加复刻时无法下载固件的故障排除相关数据

## [1.1.0.0] - JUL-03-2025 10:00

### 驱动固件勘误

+ 修复温控系统的积分器在环境温度过高且散热不良的情况下斜率不够导致手电超温退出极亮的问题
+ 修复温控系统中锁止进入极亮的逻辑会在特定时刻失效的问题
+ 修复换挡系统从特殊功能挡位进入极亮的的逻辑不够完善的问题

### 电池棒控制器固件勘误

+ 修复系统的过充保护逻辑在触发了过充保护之后即使拔除适配器结束充电也无法回到正常状态的bug
+ 修复适配器模拟模式在等待引导放电的时候缺乏等待操作导致和快捷菜单冲突

### 硬件勘误

+ 将驱动的FB注入伺服运放由OPA388IDBVR调整为TSZ121IYLT，解决低电量时运放斩波器引入的可见频闪
+ 将驱动的PWMDAC跟随运放由OPA391DCKR调整为TSZ121ICT，解决运放来料品质不稳定导致月光挡位异常
+ 将充电板的电池端检流电阻由1.5mR改为毫欧科技的1mR 3.5W低温飘电阻，解决温度导致的电池电流检测漂移

### 电池棒固件更新

+ 针对新版本充电IC定制固件增加对外放电的PDO使能和输出参数编辑菜单
+ 增加系统的测量模块修调菜单，允许高级用户手动对电流检测结果进行校准
+ 新增可以对电池棒进行定压充放电，避免长期4.2V满电存放造成电池损坏的存储模式
+ 新增可以快速令电池棒进入仅充电和仅放电模式，解除故障保护和配置存储模式的快捷菜单方便用户操作

### 驱动固件更新

+ 下调驱动的极亮挡位恒温温度至57℃，提高使用舒适性避免夏天时手柄过于烫手。

### 硬件更新

本次没有硬件更新内容

### 其余更新

+ 更新IP2366的固件至最新版本，该版本修复了PDO发包异常导致支持公版PPS的手机拒绝握手PPS无法达到最大充电功率的问题
+ 增加本更新日志文件
+ 更新驱动硬件复刻调试FAQ内和月光挡位电流降不下去的调试思路

## [1.0.0.5] - JUN-10-2025 10:00

### 驱动固件勘误

+ 修复电池电量低于10V的时候查询电压功能异常的bug
+ 彻底修复1LM挡位时电量查询功能无法显示当前电池的电量水平的bug
+ 修复1LM挡位时侧按指示灯定时闪烁提示电量功能失效的bug

### 电池棒控制器固件勘误

本次没有电池棒控制器固件勘误内容

### 硬件勘误

本次没有硬件勘误内容

### 硬件更新

1.新增电池子系统控制/监视模块（CMS）的PCB制版文件和原理图等制造数据
2.修改电池子系统充电板的电流检测电阻阻值为1.5mR，提高检测精度

### 驱动固件更新

4.更新批量烧录设置和ROM镜像至最新时间戳（20250609）
5.新增在电池电量低于10V时启用的高精度电压查询功能（精确到0.01V）

### 电池棒控制器固件更新

+ 调整电池棒控制器固件内电流检测配置为1.5mR

### 其余更新

+ 在项目主Readme内增加月光挡位和超低亮应急档的续航数据
+ 在驱动操作逻辑的Readme内增加高精度电压显示模式相关的说明。

## [1.0.0.4] - JUN-06-2025 09:54

### 驱动固件勘误

本次没有驱动固件勘误内容

### 电池棒控制器固件勘误

本次没有电池棒控制器固件勘误内容

### 驱动固件更新

1.新增一个2LM的超级省电应急月光档
2.移除操作较为不便且较少使用的系统重置功能（上电时按住按钮恢复出厂设置）
3.重写LED管理器代码优化空间占用
4.修改输出通道状态机跳转至软关机阶段的逻辑为表驱动，节约空间
5.将驱动输出电流降低至33A/30A解决FV7212D灯珠被过度驱动以及7175灯珠下输入电流卡限制的问题

### 电池棒控制器固件更新

本次没有电池棒控制器固件更新内容

### 其余更新

1.机械部分Readme增加密封圈尺寸的记录
2.驱动PCB的Readme增加新增的超级省电挡位的操作说明
3.更新驱动固件和批量烧录设置时间戳至20250606

----------------------------------------------------------------------------------------------------------------------------------
© redstoner_35 @ 35's Embedded Systems Inc.  2025

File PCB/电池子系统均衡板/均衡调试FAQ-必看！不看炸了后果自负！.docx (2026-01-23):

初步上电调试说明（步骤1）

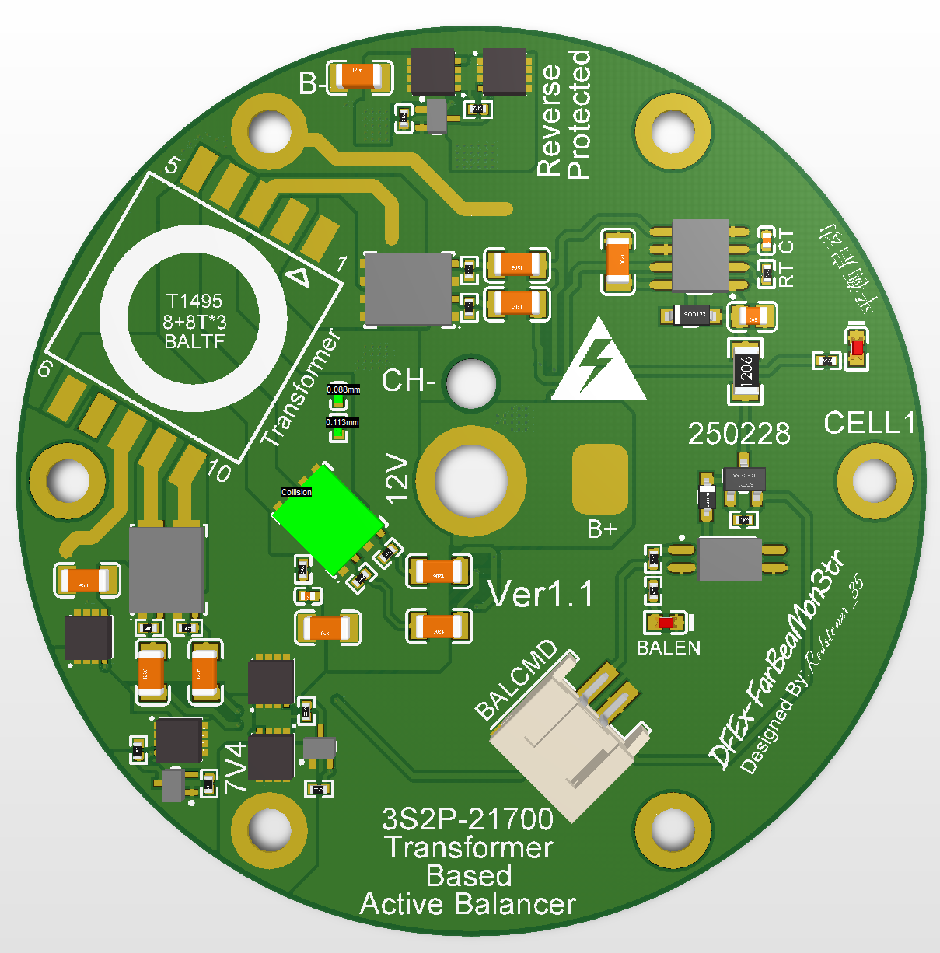
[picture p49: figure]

调试上电前，需要准备准备一个可调电源和高精度万用表（5位半至少）。可调电源调整至12.6V电压，2.0A电流（一定要限流不能用普通12V电源，不然有问题板子直接烧穿！）首先使用电烙铁和焊锡临时将图中紫色区域的两个引脚暂时短路，然后将可调电源正极连接至上图红色点，负极连接至上图蓝色点，上电。

上电之后观察待机电流，通电正常的话，板子右上角平衡启动的指示LED（黄色框内）将会点亮，可调电源的读数大约在28-35mA之间。如果板子无反应，可调电源电流读数为0，或者电流超过此值甚至直接2A打表则说明板子存在故障。此时应立即断电并参照FAQ内的指引进行故障排除。若板子正常，则参考下一步调试流程进行测试。

初步上电调试说明（步骤2）

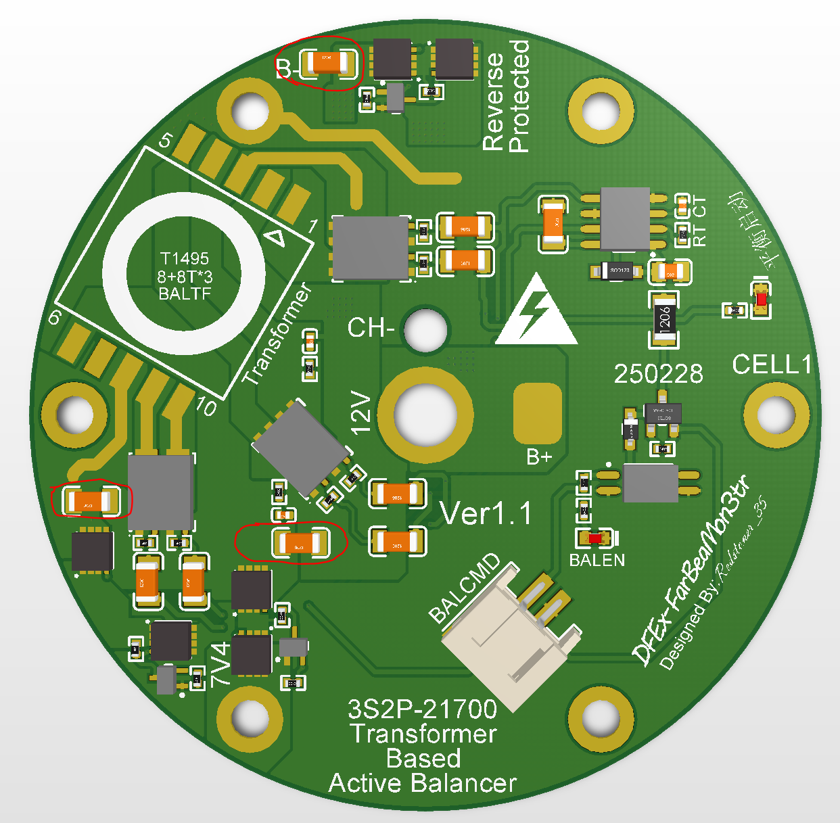
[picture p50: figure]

初步调试步骤1正常之后，即可使用万用表测量上图红圈内圈起来的三个电容器的两端电压。万用表开DC电压挡位，测量结果。正常情况下三个电容的电压均应在4.2V附近。且三个电容中，最高和最低的电压之差，不应超过15mV。例如三个电容的电压读数分别为4.1997，4.2010，4.1978。则电压差为4.2010-4.1978=0.0032=3.2mV，判定为合格。若超过此范围则不合格，此时应参照FAQ检查问题原因。若调试正常，则继续进行步骤3。

初步上电调试说明（步骤3）

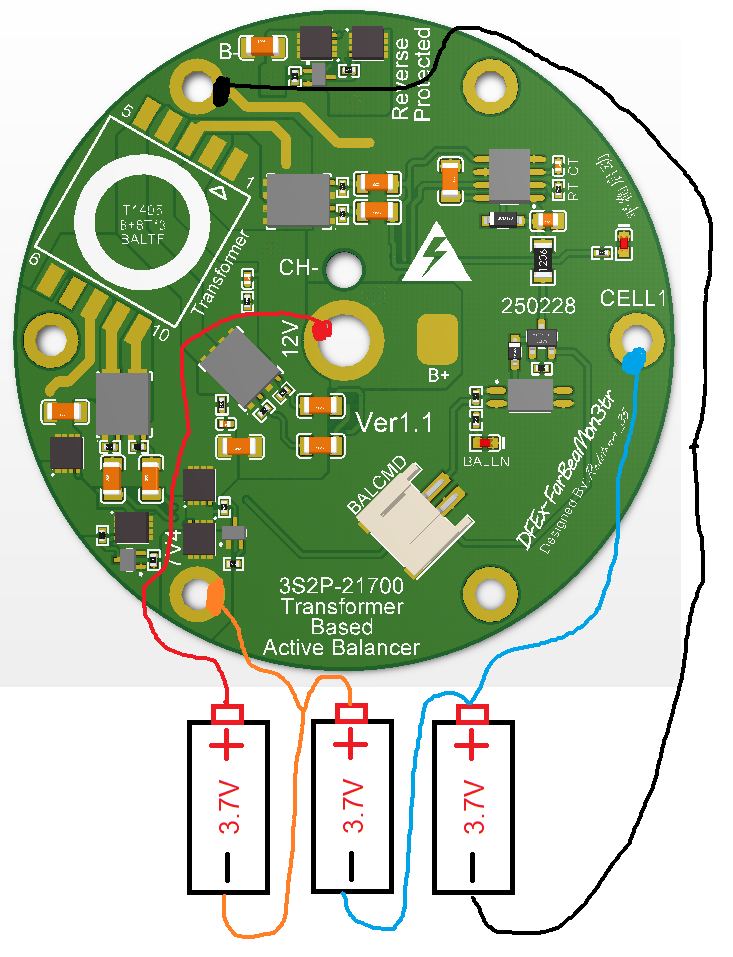
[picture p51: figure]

断开步骤1和步骤2中的可调电源接线，准备三节3.7V标称电压的锂电池（21700或者软包都可以）将其中一节放电至3.7V，剩余两节充电至4.2V。然后按照上图所示的连接顺序连接至均衡板并观察现象，此时均衡板右上角的平衡启动指示灯应点亮。若指示灯点亮，则静置24小时后，使用万用表分别测量三节电池的电压并计算压差。例如三节电池的电压测量结果3.9200，3.9205，3.9178。则电压差为3.9205-3.9178=0.0027=2.7mV。此时压差小于5mV则判定为合格。若超过此范围则不合格，此时应参照FAQ检查问题原因。如果均衡板调试合格，则可以去除图中紫色区域的短路点并清理干净电路板上残留的助焊剂等污物。

调试FAQ

注意：以下所描述的所有元器件编号所对应的原件请参考原理图PDF内的编号。

Q1：调试步骤1中，一上电可调电源立即2A大电流打表。

A1：拆除板子上的C2、C3、C4、C5、C7、C8这六个电容后再次给板子上电。使用双通道示波器测量U1的第5和第7脚。此时示波器两个通道的波形应当为相位相反，频率25.8KHz左右的方波，且具有1微秒左右的死区时间（通道1和通达2电平变化的边沿之间有1微秒的间隔，具体自行百度不做解释）。若没有波形或者频率错误，检查电阻R14、R13和电容C11，二极管D1。如果无效则更换U1。如果波形正常，则检查变压器绕制是否正确。检查变压器的磁环材质、匝数、线经和同名端是否严格按照图纸要求进行。

Q2：调试步骤2中，均衡电压的静态误差非常大

A1：检测滤波电容C1、C6、C9的容值是否匹配。如果匹配，则通常为变压器绕制匝数不准确导致。变压器需要使用机绕，手绕的匝数会不准确导致电压偏差异常。此时可以更换一个新的均衡变压器再试。

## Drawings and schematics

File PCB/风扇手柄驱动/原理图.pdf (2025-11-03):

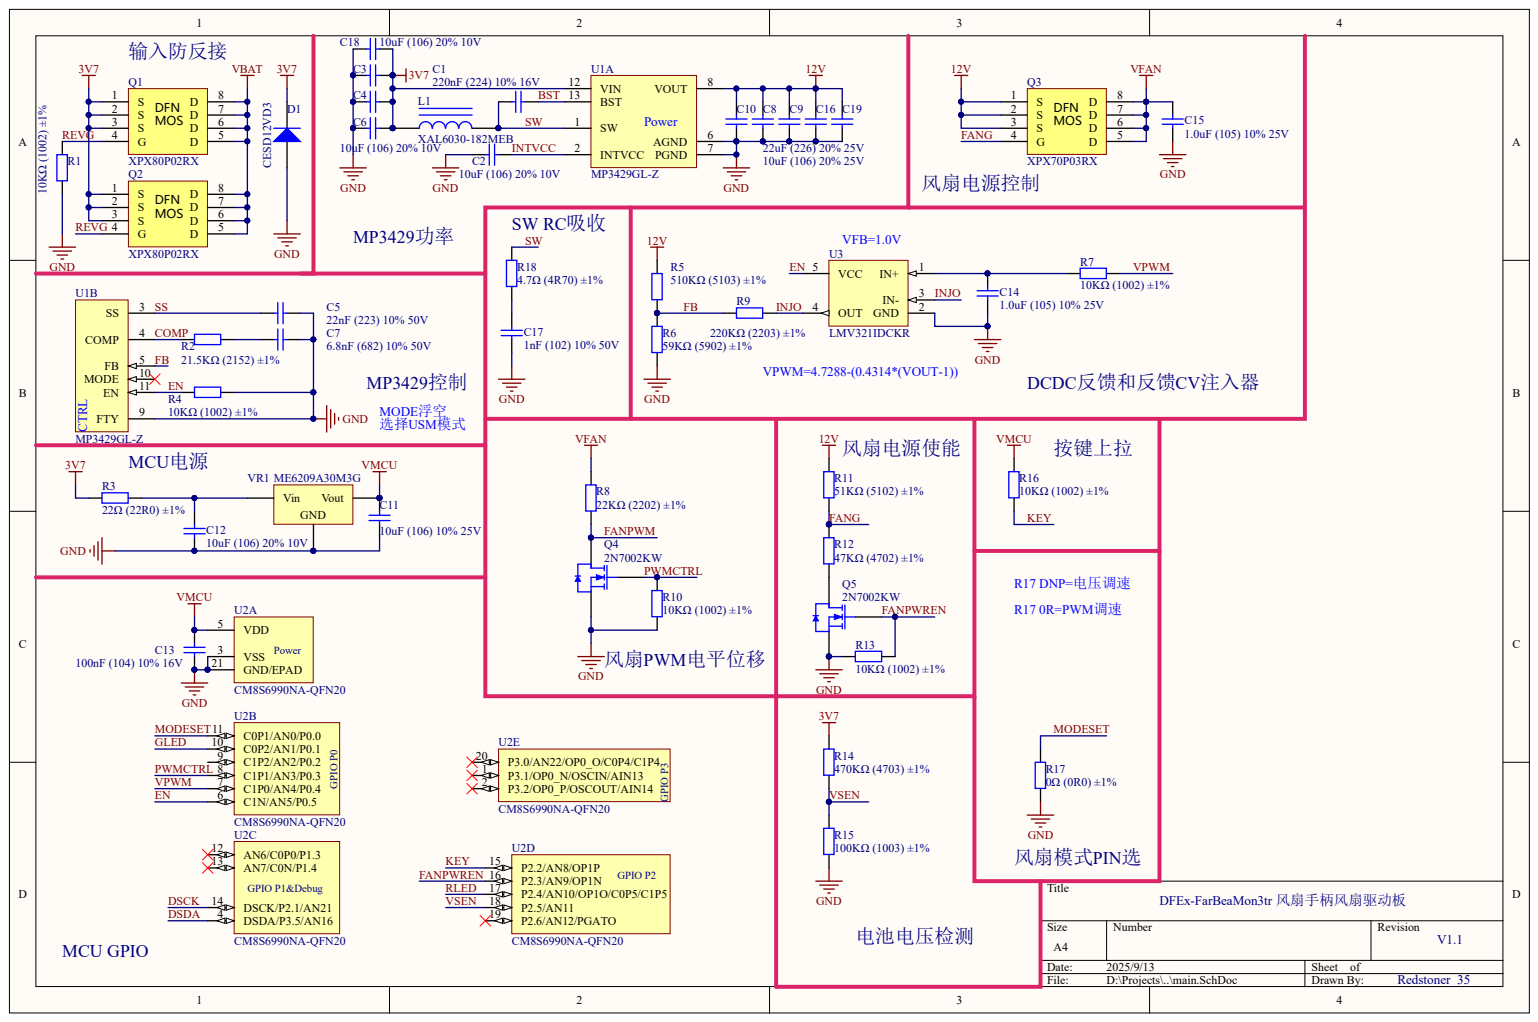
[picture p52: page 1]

VFAN | 12V | VMCU

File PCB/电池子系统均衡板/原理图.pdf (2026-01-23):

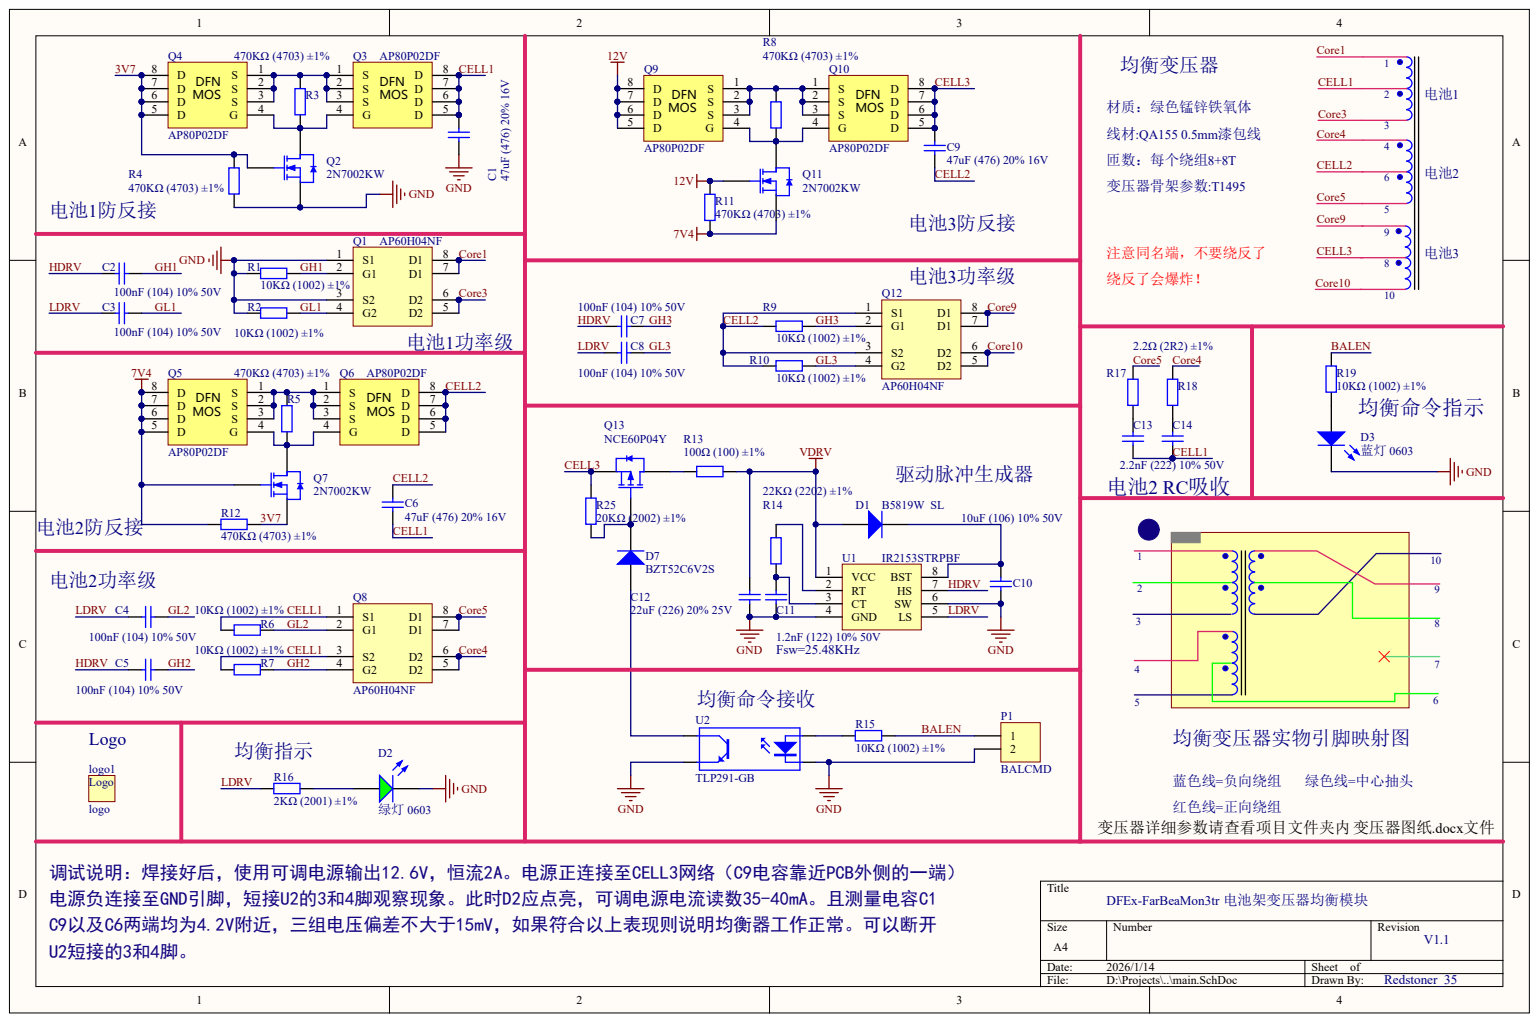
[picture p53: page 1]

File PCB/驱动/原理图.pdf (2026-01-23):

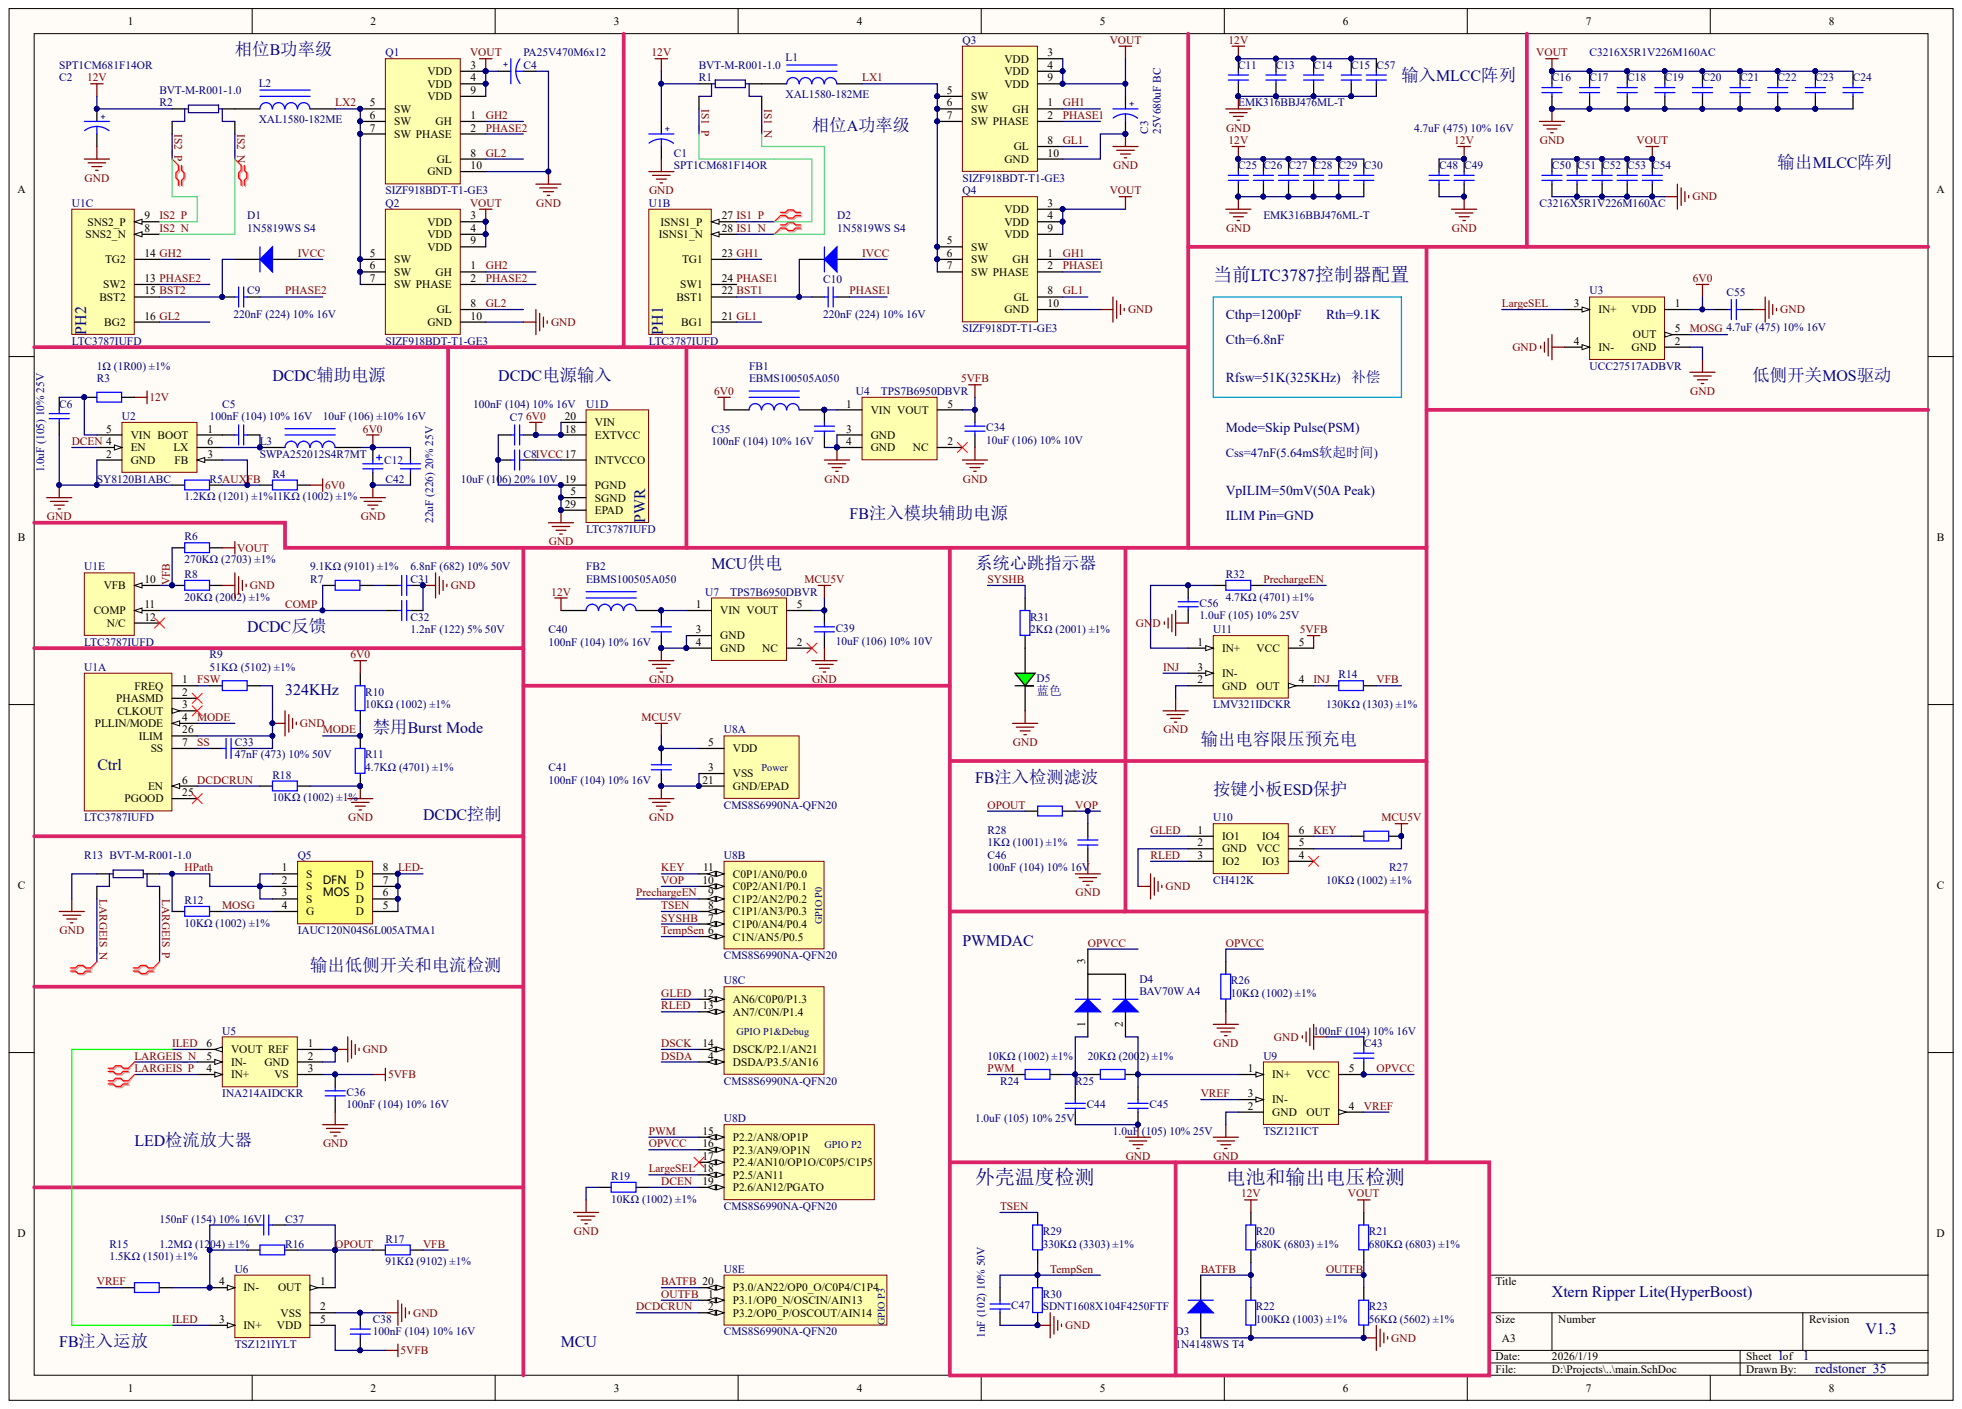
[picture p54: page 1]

Mode=Skip Pulse(PSM)

Xtern Ripper Lite(HyperBoost)

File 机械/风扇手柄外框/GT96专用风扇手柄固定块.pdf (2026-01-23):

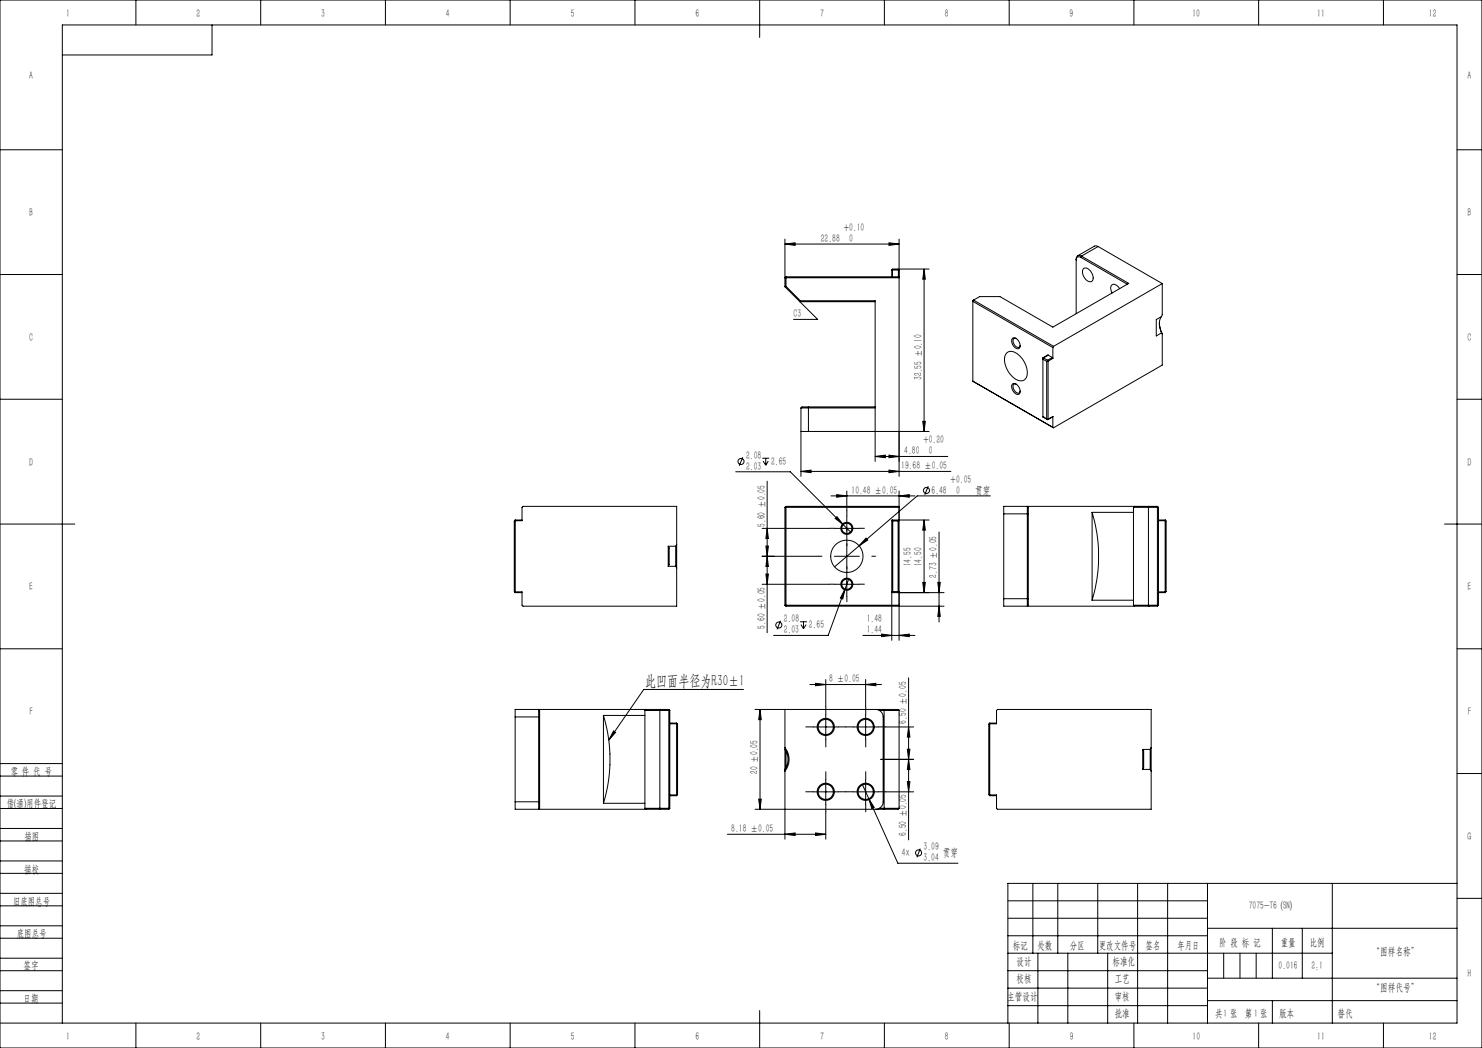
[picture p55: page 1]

阶 段 标 记 | 重量 | 比例 | “图样名称”

标记 | 处数 | 分区 | 更改文件号 | 签名 | 年月日
设计 | | | 标准化 | | | 0.016 | 2:1
校核 | | | 工艺

“图样代号”

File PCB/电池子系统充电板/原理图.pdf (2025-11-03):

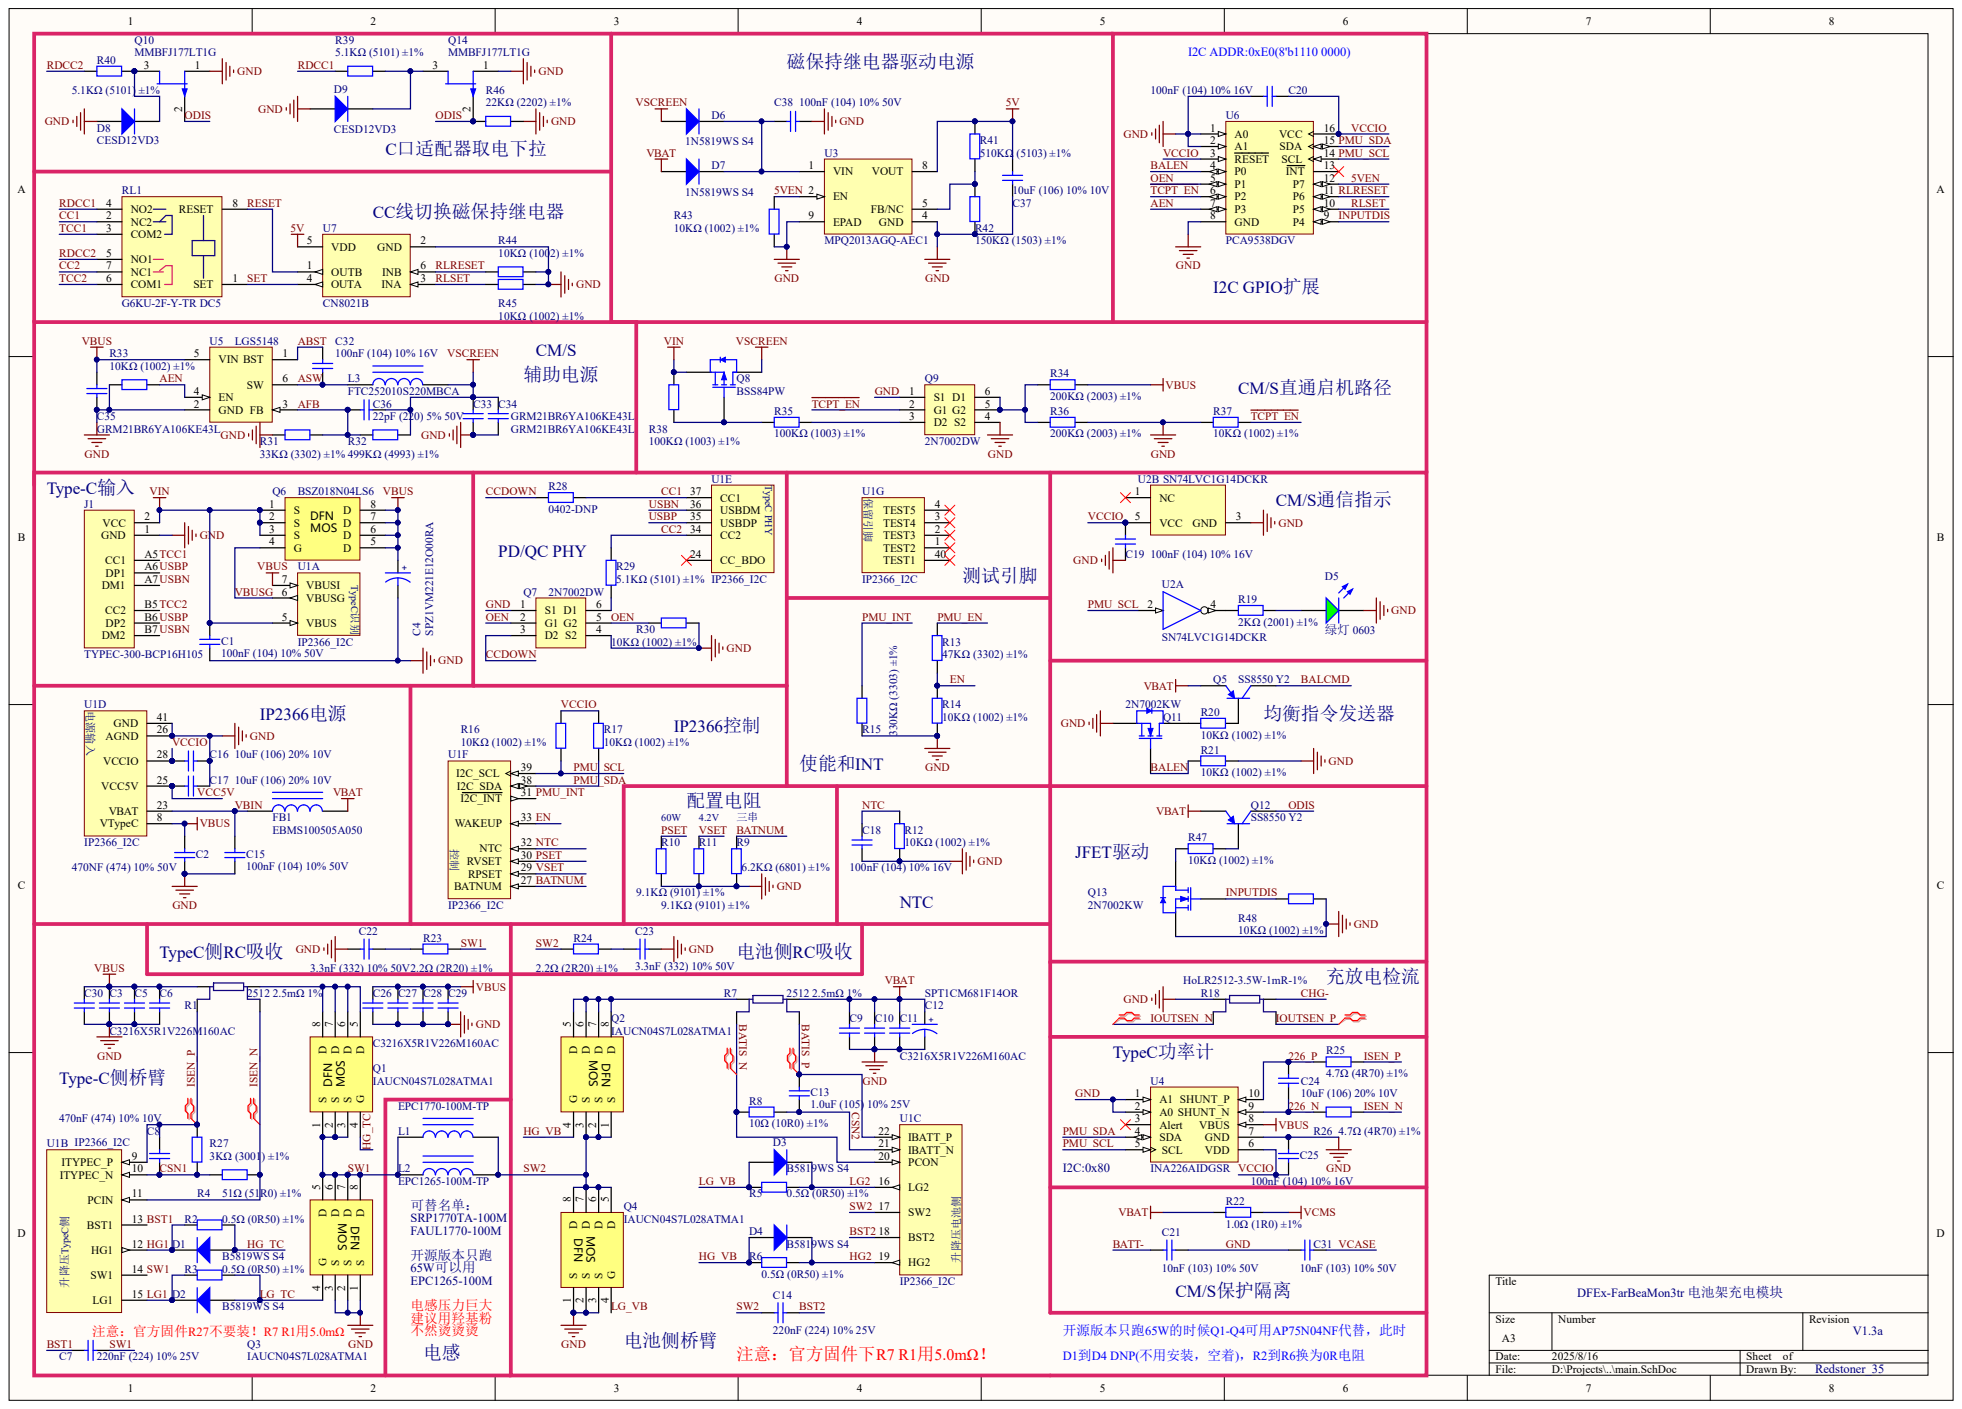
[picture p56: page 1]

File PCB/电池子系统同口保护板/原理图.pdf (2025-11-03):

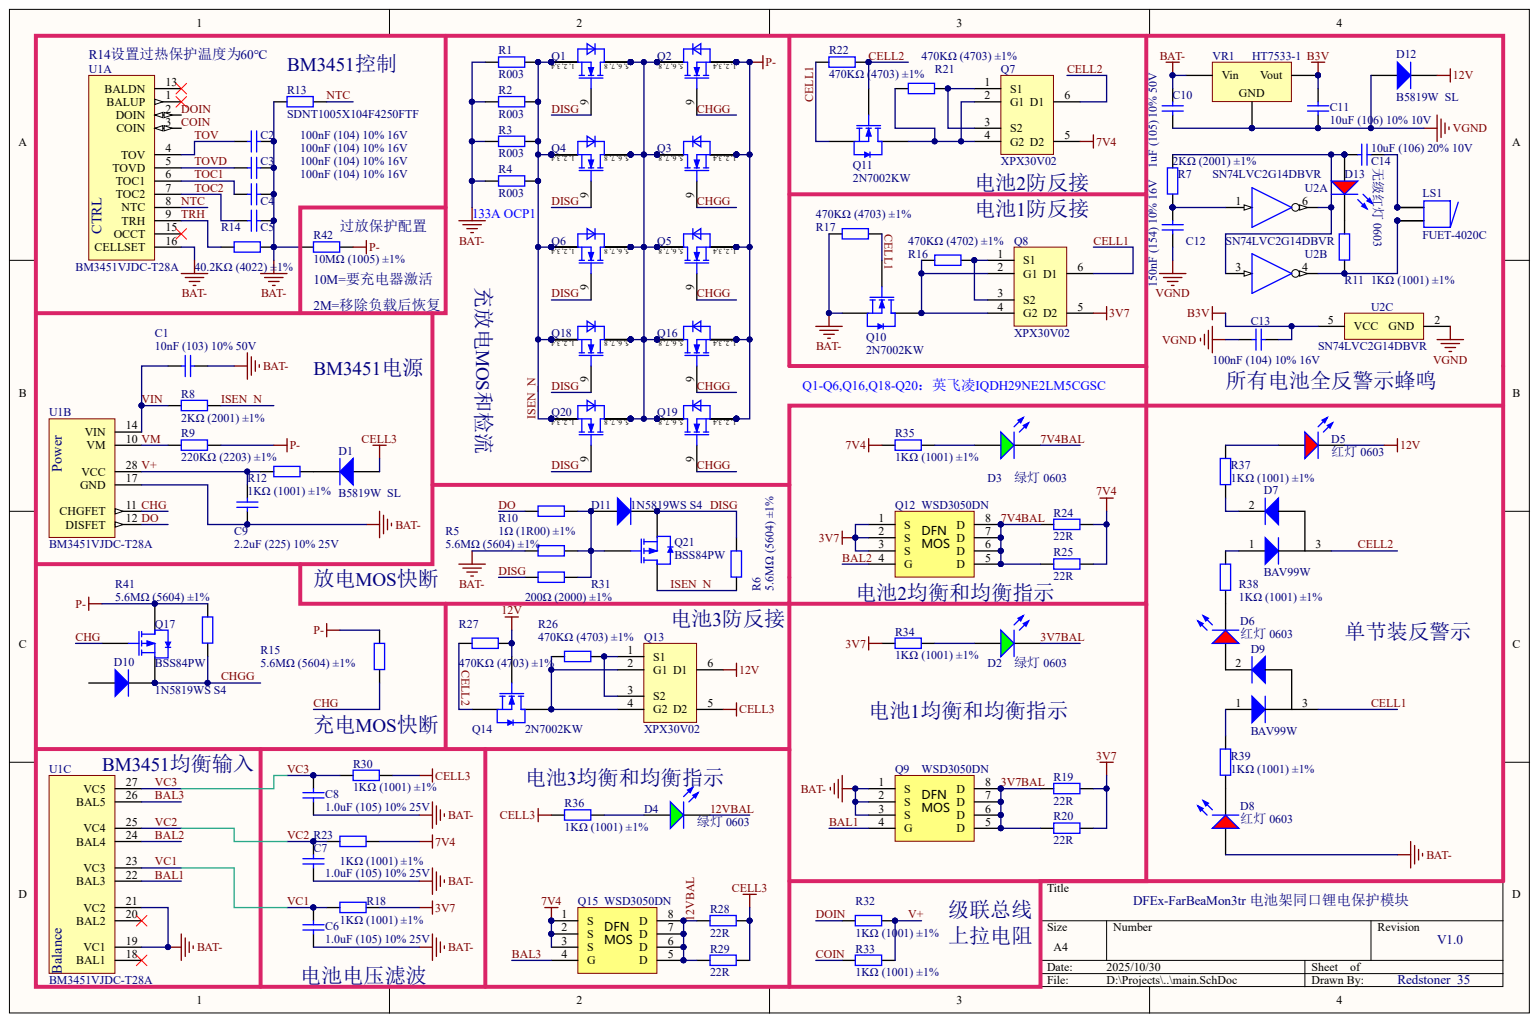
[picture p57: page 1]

200Ω (2000) ±1% | | 电池2均衡和均衡指示

BAL2

VC1 | 1KΩ (1001) ±1%
BAL1

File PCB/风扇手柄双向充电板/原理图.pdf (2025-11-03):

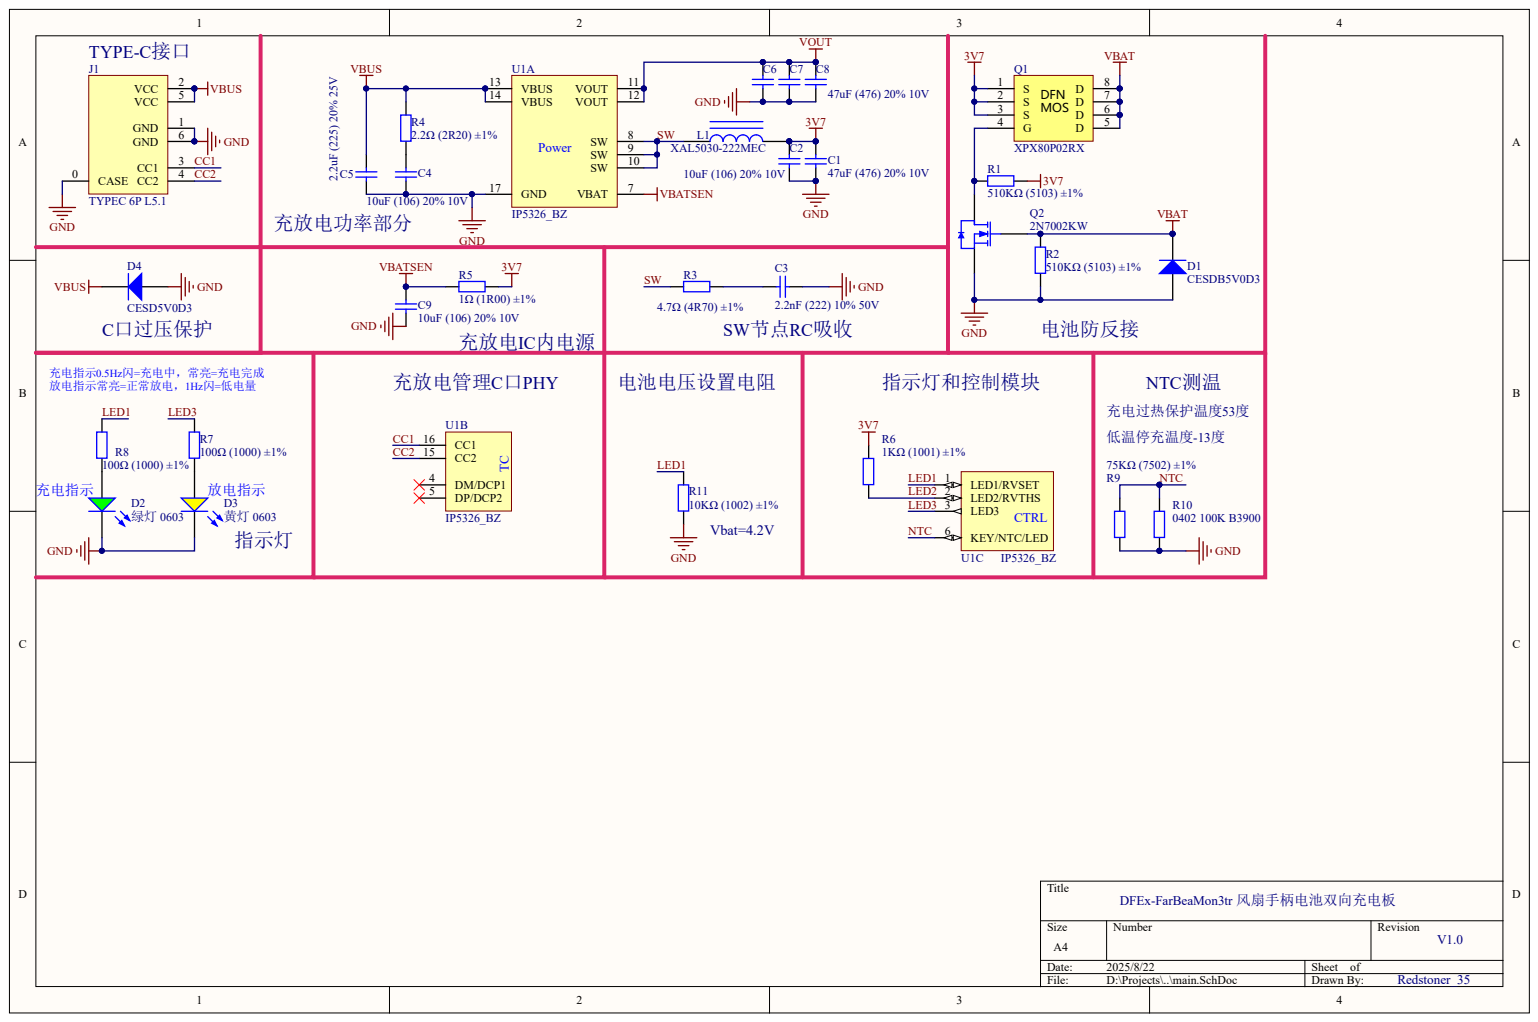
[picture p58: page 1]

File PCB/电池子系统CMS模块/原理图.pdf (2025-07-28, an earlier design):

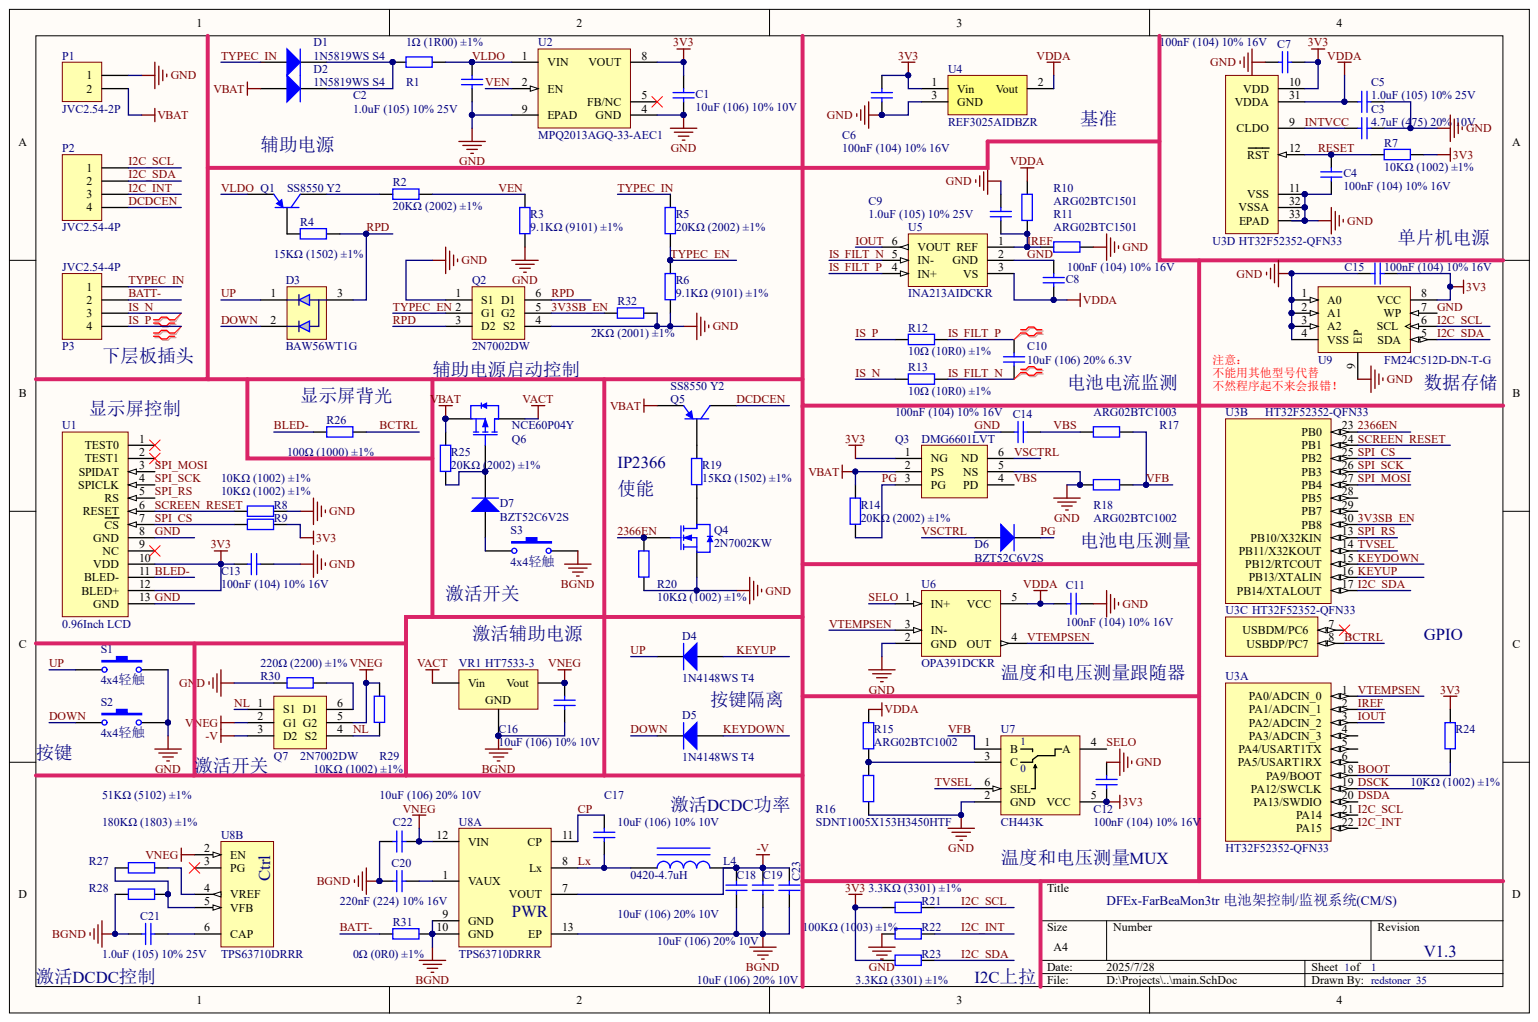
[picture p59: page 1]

100nF (104) 10% 16V | VDDA

I2C_SDA | R2

R26 | VBAT VACT | SS8550 Y2 | 10Ω (10R0) ±1%

100nF (104) 10% 16V C14 ARG02BTC1003

DFEx-FarBeaMon3tr 电池架控制/监视系统(CM/S)

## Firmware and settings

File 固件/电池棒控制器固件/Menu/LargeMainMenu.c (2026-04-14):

#include "IP2366_REG.h"
#include "GUI.h"
#include "Config.h"
#include "lcd.h"
#include "ADC.h"
#include "Key.h"
#include "LogSystem.h"
#include <math.h>

//外部变量
extern bool IsTelemOK;
extern float VTypec,ITypeC,VBat,IBat;
extern ChipStatDef CState;
extern bool Is2366Telem;
extern RecvPDODef PDO;
extern bool IsUpdateCDUI;
extern BatteryStateDef BATT;
extern IP2366VBUSStateDef VBUS;
extern bool IsResultUpdated;

//内部变量
static bool IsShowTypeCState=false;

//显示AH数
static void LargeMenu_DisplayAh(float Ah,bool IsDis)
	{
	float Power;
	u16 Color=IsDis?CYAN:WHITE;
	LCD_Fill(99,18,150,31,BLACK); //消除掉旧的图标
	if(Ah<10) //小于10Ah使用mAH显示
		{
		LCD_ShowIntNum(99,18,iroundf(Ah*1000),4,Color,BLACK,12);
		LCD_ShowString(132,18,"mAh",Color,BLACK,12,0);
		}
	else if(Ah<100000)//使用浮点显示
		{
		LCD_ShowString(132,18," Ah",Color,BLACK,12,0);
		if(Ah<100)LCD_ShowFloatNum1(99,18,Ah,2,Color,BLACK,12);  //99.99显示
		else if(Ah<100)LCD_ShowFloatNum1(99,18,Ah,1,Color,BLACK,12);  //999.9显示
		else LCD_ShowIntNum(99,18,iroundf(Ah),5,Color,BLACK,12); //9999显示
		}
	else //使用KAH显示
		{
		Power=Ah/1000;
    if(Power<10)LCD_ShowFloatNum1(99,18,Power,3,Color,BLACK,12);  //9.999显示
		else if(Power<100)LCD_ShowFloatNum1(99,18,Power,2,Color,BLACK,12);  //99.99显示
		else if(Power<1000)LCD_ShowFloatNum1(99,18,Power,1,Color,BLACK,12);  //999.9显示
		else LCD_ShowIntNum(99,18,iroundf(Power),5,Color,BLACK,12); //9999显示
		LCD_ShowString(132,18,"KAh",Color,BLACK,12,0);
		}	
	}
//显示充放电能量
static void LargeMenu_DisplayWh(float Wh,bool IsDis)
	{
	float Power;
	u16 Color=IsDis?CYAN:WHITE;	
	LCD_Fill(99,34,150,46,BLACK); //消除掉旧的图标
	if(Wh<10000)LCD_ShowString(132,34," Wh",Color,BLACK,12,0);
	if(Wh<10)LCD_ShowFloatNum1(99,34,Wh,3,Color,BLACK,12); //9.999显示
	else if(Wh<100)LCD_ShowFloatNum1(99,34,Wh,2,Color,BLACK,12); //99.99显示	
	else if(Wh<1000)LCD_ShowFloatNum1(99,34,Wh,1,Color,BLACK,12); //999.9显示
	else if(Wh<10000)LCD_ShowIntNum(99,34,iroundf(Wh),5,Color,BLACK,12); //9999显示
	else	
	  {
		Power=Wh;
	  if(Power<10)LCD_ShowFloatNum1(99,34,Power,2,Color,BLACK,12); //9.99显示
		else if(Power<100)LCD_ShowFloatNum1(99,34,Power,1,Color,BLACK,12); //99.9显示	
		else if(Power<1000)LCD_ShowIntNum(99,34,iroundf(Power),3,Color,BLACK,12); //999显示
		LCD_ShowString(132,34,"KWh",Color,BLACK,12,0);	
		}
	}	
//显示充放电时间
static void LargeMenu_ShowTime(long TimeIN,bool IsDis)
	{
	long time;
	u16 ICONColor=IsDis?LIGHTGREEN:WHITE;
	u16 TextColor=IsDis?ORANGE:YELLOW;
	if(TimeIN>86400*30) //时长超过一个月
		{
		time=TimeIN/(86400*30); //计算出月数
		LCD_ShowIntNum(99,49,time,2,TextColor,BLACK,12);
		LCD_ShowChinese12x12(115,49,"月\0",ICONColor,BLACK,12,0);
		time=(TimeIN%(86400*30))/86400; //计算出天数
		LCD_ShowIntNum(128,49,time,2,TextColor,BLACK,12);
		LCD_ShowChinese12x12(144,49,"天\0",ICONColor,BLACK,12,0);			
		}
	else if(TimeIN>86400) //时长超过一天
		{
		time=TimeIN/86400; //计算出天数
		LCD_ShowIntNum(99,49,time,2,TextColor,BLACK,12);
		LCD_ShowChinese12x12(115,49,"天\0",ICONColor,BLACK,12,0);
		time=(TimeIN%86400)/3600; //计算出小时数
		LCD_ShowIntNum(128,49,time,2,TextColor,BLACK,12);
		LCD_ShowChinese12x12(144,49,"时\0",ICONColor,BLACK,12,0);		
		}
	else if(TimeIN>3600)
		{
		time=TimeIN/3600; //计算出小时数
		LCD_ShowIntNum(99,49,time,2,TextColor,BLACK,12);
		LCD_ShowChinese12x12(115,49,"时\0",ICONColor,BLACK,12,0);
		time=(TimeIN%3600)/60; //计算出分钟数
		LCD_ShowIntNum(128,49,time,2,TextColor,BLACK,12);
		LCD_ShowChinese12x12(144,49,"分\0",ICONColor,BLACK,12,0);			
		}
  else
		{
		time=TimeIN/60; //计算出分钟数
		LCD_ShowIntNum(99,49,time,2,TextColor,BLACK,12);
		LCD_ShowChinese12x12(115,49,"分\0",ICONColor,BLACK,12,0);
		time=TimeIN%60;
		LCD_ShowIntNum(128,49,time,2,TextColor,BLACK,12);
		LCD_ShowChinese12x12(144,49,"秒\0",ICONColor,BLACK,12,0);		 
		}	
	}	

//大菜单显示电池状态时进行特殊模式的显示处理
static bool ShowSpecicalModeAtBatt(void)	
	{	
	extern char	DisplayLoopCounter;
	extern bool IsEnableTempChargeOnly;
	//仅充模式启用
	if(IsEnableTempChargeOnly||!DCDCOutputBit)
		{	
		if(DisplayLoopCounter<3)return false; //非显示状态，正常显示
		LCD_Fill(98,63,159,79,BLACK);
		if(StorageMode!=StorageMode_OFF&&DisplayLoopCounter<5)
			LCD_ShowHybridString(99,64,"存储模式",ORANGE,BLACK,0);  //交替显示仅充模式
		else	
			LCD_ShowHybridString(99,64,"仅充模式",LIGHTBLUE,BLACK,0);
	  return true;
		}
	//存储模式启用		
	else if(StorageMode!=StorageMode_OFF)
		{
		if(DisplayLoopCounter<4)return false; //非显示状态，正常显示
		//显示仅充模式
		LCD_Fill(98,63,159,79,BLACK);
		LCD_ShowHybridString(99,64,"存储模式",ORANGE,BLACK,0);
		return true;
		}		
	//其余状态返回false
	return false;
	}
	
//显示电池状态
static void RenderBattState(void)
	{
	float Power;
	u16 Color;
	int Temp;
	long time;
	bool IsShowBatt;
	extern bool IsSystemOverheating;
	extern bool OCState;
	extern bool IsSystemLowTemp;
	extern IP2366ResetCPortProcDef IPSinkState;
	extern bool IsEnableTempChargeOnly;
	//检测UI是否结束渲染
	Is2366Telem=true;
	time=(BATT==Batt_discharging)?LogData.DischargeTime:LogData.ChargeTime; //获取充放电时间
	if(!IsTelemOK)return;
	if(BATT!=Batt_StandBy&&fabsf(ADCO.Ibatt)>MinimumCurrentFactor)	//系统处于开机状态，且日志正在累加，按照结果渲染数据
		{
		if(time>86400&&!IsResultUpdated)return; //时间超过1个小时可以使用较快的刷新频率
		else if(time<86400&&!IsUpdateCDUI)return;	 //时间一个小时内使用较慢的刷新频率让秒数跳字同步	
		}
	else if(!IsResultUpdated)return;  //静态阶段使用快速更新系统
	//正常渲染
	LCD_DrawRectangle(0,0,159,79,WHITE);	
	//根据系统状态设置电压颜色
  if(StorageMode!=StorageMode_OFF)Color=ORANGE; //存储模式开启强制为黄色
	else if(IsEnableTempChargeOnly||!DCDCOutputBit)Color=LIGHTBLUE; //非存储模式下开启仅充电，电池电压为淡蓝色
	else Color=LIGHTGREEN; //都没有开启则绿色
	//显示电池电压
	LCD_ShowFloatNum1(3,3,VBat,VBat<10?3:2,Color,BLACK,24);
	LCD_ShowChar(73,3,'V',Color,BLACK,24,0);
	//电流
	LCD_Fill(3,28,84,76,BLACK);
	Power=fabsf(IBat)>MinimumCurrentFactor?IBat:0;
	if(Power<0) //电流为负数加上负号
		{
		LCD_ShowChar(3,28,'-',YELLOW,BLACK,24,0);	
		if(Power>-10)LCD_ShowFloatNum1(16,28,Power,2,YELLOW,BLACK,24);
		else LCD_ShowFloatNum1(16,28,Power,1,YELLOW,BLACK,24);
		}
	//正常按照电流值显示
	else LCD_ShowFloatNum1(3,28,Power,Power<10?3:2,YELLOW,BLACK,24);
	LCD_ShowChar(73,28,'A',YELLOW,BLACK,24,0);	
	//功率
	Power=fabsf(VBat*Power);
	if(Power<10)LCD_ShowFloatNum1(3,53,Power,3,CYAN,BLACK,24);
	else if(Power<100)LCD_ShowFloatNum1(3,53,Power,2,CYAN,BLACK,24);
  else LCD_ShowFloatNum1(3,53,Power,1,CYAN,BLACK,24);
  LCD_ShowChar(73,53,'W',CYAN,BLACK,24,0);	
	//温度
	if(!ADCO.IsNTCOK)LCD_ShowString(99,3,"---.-",WHITE,BLACK,12,0);
	else
		{
		Temp=iroundf(ADCO.Systemp);
		if(Temp<0)Color=DARKBLUE;	
		if(Temp<10)Color=BLUE;
		else if(Temp<CfgData.OverHeatLockTemp-20)Color=GREEN;
		else if(Temp<CfgData.OverHeatLockTemp-8)Color=YELLOW;
		else Color=RED;	
		//0度
		if(ADCO.Systemp<0)
			{
			LCD_ShowChar(99,3,'-',WHITE,BLACK,12,0);
			if(ADCO.Systemp>-10)LCD_ShowFloatNum1(107,3,ADCO.Systemp*-1,2,Color,BLACK,12);
			else LCD_ShowFloatNum1(107,3,ADCO.Systemp*-1,1,Color,BLACK,12);
			}
		//其他温度
		else if(ADCO.Systemp<99)LCD_ShowFloatNum1(99,3,ADCO.Systemp*-1,2,Color,BLACK,12);
		else LCD_ShowFloatNum1(99,3,ADCO.Systemp*-1,1,Color,BLACK,12);
		LCD_ShowChinese12x12(144,3,"℃\0",Color,BLACK,12,0);
		}
	//容量显示
	if(BATT==Batt_discharging)LargeMenu_DisplayAh(LogData.TotalDischargeAh,true);
	else LargeMenu_DisplayAh(LogData.TotalChargeAh,false);
	//能量显示
  if(BATT==Batt_discharging)LargeMenu_DisplayWh(LogData.TotalDischargeWh,true);
	else LargeMenu_DisplayWh(LogData.TotalChargeWh,false);
	//充电时间显示
	LargeMenu_ShowTime(time,BATT==Batt_discharging?true:false);
  //显示电池状态
	if(CState.VSysState!=VSys_State_Normal||CState.VBusState==VBUS_OverVolt)IsShowBatt=false;
	else if(IsSystemOverheating)IsShowBatt=false;
  else if(OCState)IsShowBatt=true;		
	else if(BATT!=Batt_StandBy)IsShowBatt=true;
	else IsShowBatt=false;	
	//显示实际的内容	
  if(!ShowSpecicalModeAtBatt())	
		{
		LCD_ShowHybridString(99,64,IsShowBatt?"电池:":"系统:",WHITE,BLACK,0);
		if(IsSystemOverheating)
			LCD_ShowChinese(132,64,"过热\0",RED,BLACK,0);
		else if(CState.VSysState!=VSys_State_Normal||CState.VBusState==VBUS_OverVolt) //输出短路或者输入过压
			LCD_ShowChinese(132,64,"故障\0",RED,BLACK,0);
		else if(OCState)
			LCD_ShowChinese(132,64,DisplayProtectState("过充"),YELLOW,BLACK,0);
		
	  else if(IPSinkState!=IP2366_CPort_Reseted)LCD_ShowChinese(132,64,"充满\0",LIGHTGREEN,BLACK,0);
	  else if(IsSystemLowTemp&&BATT!=Batt_discharging)LCD_ShowChinese(86,61,DisplayProtectState("低温"),YELLOW,BLACK,0);	
		else switch(BATT)			//根据枚举状态显示
			{
			case Batt_StandBy:LCD_ShowChinese(132,64,"待机\0",WHITE,BLACK,0);break;
			case Batt_PreChage:
				LCD_ShowChinese(132,64,DisplayChgState("涓流\0"),MAGENTA,BLACK,0);
				break;
			case Batt_CCCharge:
				LCD_ShowChinese(132,64,DisplayChgState("恒流\0"),YELLOW,BLACK,0);
				break;
			case Batt_CVCharge:
				LCD_ShowChinese(132,64,DisplayChgState("恒压\0"),GBLUE,BLACK,0);
				break;
			case Batt_ChgWait:
				LCD_ShowChinese(132,64,DisplayChgState("暂停\0"),YELLOW,BLACK,0);
				break;
			case Batt_ChgDone:LCD_ShowChinese(132,64,"充满\0",LIGHTGREEN,BLACK,0);break;
			case Batt_ChgError:LCD_ShowChinese(132,64,DisplayChgState("超时\0"),ORANGE,BLACK,0);break;
			case Batt_discharging:LCD_ShowChinese(132,64,"放电\0",CYAN,BLACK,0);break;
			}
		}
	//本次显示完毕，等待数据更新后再刷新
  IsTelemOK=false;	
  IsResultUpdated=false;		
	IsUpdateCDUI=false;
	}
	
//显示Type-C状态
void RenderTypeCState(void)
	{
	float Power;
	extern bool IsDispChargingINFO;
	extern bool IsEnableHPGauge;	
	//启动传输
	Is2366Telem=true;
	if(!VBUS.IsTypeCConnected||CState.VBusState==VBUS_NoPower)
		{
		//Type-C被移除，立即退出本菜单
		ClearScreen();
		IsShowTypeCState=false;
		return;
		}
	if(!IsTelemOK||!IsResultUpdated)return;
	//正常渲染
	LCD_DrawRectangle(0,0,159,79,WHITE);	
	//电压
	LCD_ShowFloatNum1(3,3,VTypec,(IsEnableHPGauge&&VTypec<10)?3:2,IsEnableHPGauge?ORANGE:LIGHTGREEN,BLACK,24);
	LCD_ShowChar(73,3,'V',IsEnableHPGauge?ORANGE:LIGHTGREEN,BLACK,24,0);
	//电流
	LCD_Fill(3,28,84,76,BLACK);
	Power=fabsf(ITypeC)>MinimumCurrentFactor?ITypeC:0;
	if(Power<0) //电流为负数加上负号
		{
		LCD_ShowChar(3,28,'-',YELLOW,BLACK,24,0);			
		if(Power>-10)LCD_ShowFloatNum1(16,28,Power,2,YELLOW,BLACK,24);
		else LCD_ShowFloatNum1(16,28,Power,1,YELLOW,BLACK,24);
		}
	//开启高精度功率计，低电流下显示精确到小数点后三位
	else if(IsEnableHPGauge)LCD_ShowFloatNum1(3,28,Power,Power<10?3:2,YELLOW,BLACK,24);
	//IP2366显示，默认两位精度
	else LCD_ShowFloatNum1(3,28,Power,2,YELLOW,BLACK,24);
	LCD_ShowChar(73,28,'A',YELLOW,BLACK,24,0);	
	//功率
	Power=fabsf(VTypec*Power);
	if(Power<10)LCD_ShowFloatNum1(3,53,Power,3,CYAN,BLACK,24);
	else if(Power<100)LCD_ShowFloatNum1(3,53,Power,2,CYAN,BLACK,24);
  else LCD_ShowFloatNum1(3,53,Power,1,CYAN,BLACK,24);
  LCD_ShowChar(73,53,'W',CYAN,BLACK,24,0);	
	//PDO输入和VBUS状态显示
	LCD_Fill(102,9,152,36,BLACK);
	LCD_DrawRectangle(102,9,152,36,WHITE);
	LCD_Fill(104,4,150,15,BLACK);
	//开启输入模式下显示PDO状态
	if(!IsDispChargingINFO&&BATT!=Batt_discharging)	
		{		
		LCD_ShowHybridString(104,4,"PDO广播",WHITE,BLACK,0);
		switch(PDO)
			{
			case RecvPDO_None:LCD_ShowString(116,19,"N/A",WHITE,BLACK,12,0);break;
			case RecvPDO_5V:LCD_ShowString(116,19," 5V",CYAN,BLACK,12,0);break;
			case RecvPDO_9V:LCD_ShowString(116,19," 9V",BLUE,BLACK,12,0);break;
			case RecvPDO_12V:LCD_ShowString(116,19,"12V",GREEN,BLACK,12,0);break;
			case RecvPDO_15V:LCD_ShowString(116,19,"15V",CYAN,BLACK,12,0);break;
			case RecvPDO_20V:LCD_ShowString(116,19,"20V",CYAN,BLACK,12,0);break;
			}
		}
	else //显示输入状态
		{
		LCD_ShowHybridString(105,4,"Type-C",WHITE,BLACK,0);
		if(CState.VBusState==VBUS_NoPower)LCD_ShowHybridString(115,19,"断开",LGRAY,BLACK,0);	
		else if(CState.VBusState==VBUS_OverVolt)LCD_ShowHybridString(115,19,"过压",RED,BLACK,0);
		else switch(CState.VSysState)
			{
			case VSys_State_Normal:LCD_ShowHybridString(115,19,"正常",GREEN,BLACK,0);break;
			case VSys_State_OCP:LCD_ShowHybridString(115,19,"过流",YELLOW,BLACK,0);break;
			case VSys_State_Short:LCD_ShowHybridString(115,19,"短路",RED,BLACK,0);break;
			}
		}		
	//协议显示
	LCD_Fill(102,46,152,73,BLACK);
	LCD_DrawRectangle(102,46,152,73,WHITE);
	LCD_Fill(112,41,142,52,BLACK);
	LCD_ShowHybridString(115,41,"协议",WHITE,BLACK,0);
	//PD快充
	if(VBUS.QuickChargeState==QuickCharge_PD)DisplaySysPDState(108,56);
	//QC和大电流快充
	else if(VBUS.QuickChargeState==QuickCharge_HV)LCD_ShowChinese(115,56,"高压\0",YELLOW,BLACK,0);
	else if(VBUS.QuickChargeState==QuickCharge_HC)LCD_ShowChinese(115,56,"高流\0",YELLOW,BLACK,0);
	//无快充
	else LCD_ShowString(115,56,"N/A",WHITE,BLACK,12,0);
	//本次显示完毕，等待数据更新后再刷新
  IsTelemOK=false;		
	IsResultUpdated=false;
	}	

//按键处理
void EnterAdvModeProc(void);	
	
void LargeMainMenuKeyProcess(void)
	{
	bool IsAllowTypecMenuShow; //是否允许typec菜单显示
	//判断是否允许跳转到typec显示
	if(CState.VBusState==VBUS_NoPower)IsAllowTypecMenuShow=false; //VBUS没有电源
	else if(!VBUS.IsTypeCConnected)IsAllowTypecMenuShow=false; //Typec未连接
	else IsAllowTypecMenuShow=true;
	//按压Enter进入快捷菜单
	if(KeyState.KeyEvent==KeyEvent_Enter)SwitchingMenu(&QuickAccessMenu);
	//同时按住上下键进入设置
	if(KeyState.KeyEvent==KeyEvent_BothEnt)
		{
		if(!CfgData.EnableAdvAccess)SwitchingMenu(&EasySetMainMenu); //进入简易模式
		else EnterAdvModeProc(); //进入高级模式
		}
	//按压上键进入typec显示
	if(IsAllowTypecMenuShow&&KeyState.KeyEvent==KeyEvent_Up)
		{
		if(!IsShowTypeCState)ClearScreen();
		IsShowTypeCState=true;
		}
	//按压下键返回主菜单
	if(KeyState.KeyEvent==KeyEvent_Down)
		{
		if(IsShowTypeCState)ClearScreen();
		IsShowTypeCState=false;
		}
	KeyState.KeyEvent=KeyEvent_None;
	}
	
//渲染处理
void LargeMenuRenderProc(void)
	{
	if(!CfgData.EnableLargeMenu)
		{	
		SwitchingMenu(&MainMenu);
		return;
		}
	if(IsShowTypeCState)RenderTypeCState();
	else RenderBattState(); 
	}
	
const MenuConfigDef LargeMainMenu=
	{
	MenuType_Custom,
	//布尔类的入口
	NULL,
	//枚举编辑的入口
	NULL,
  NULL,
  NULL,		
	//自定义入口
	&LargeMenuRenderProc, //渲染函数
	&LargeMainMenuKeyProcess, //按键处理
	//不是设置菜单不需要用别的事情
	NULL,
	NULL,
	NULL, 
	NULL,
	//进入和退出构造函数没有事情要做
	NULL,
	NULL
	};
	

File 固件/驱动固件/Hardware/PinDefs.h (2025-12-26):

/************************************************************************************/
/** \file PinDefs.h
/** \Author redstoner_35
/** \Project Xtern Ripper Hyper Boost For GT96
/** \Description 这个头文件为底层的硬件定义文件，定义了整个工程内所有外设对应的硬件PIN和
模拟输入ADC通道的映射关系。

**	History: 
				2025年12月26日 10:05 新增电池电压检测引脚和输出检测引脚的GPIO Port SFR声明以便于
				                     ADC驱动直接对相关引脚进行设置。
														 
				2025年12月20日 Initial Release
**	
/************************************************************************************/
#ifndef PINDEFS
#define PINDEFS
/************************************************************************************/
/* Include files */
/************************************************************************************/
#include "GPIOCfg.h"

/************************************************************************************
这个文件包含工程内所有用到的IO引脚的引脚位置描述，已经按照引脚功能类型进行了分组，如果
您计划将该固件用于其他驱动，您可以根据硬件调整引脚定义。
************************************************************************************/

/******************** 以下是主DCDC和辅助DCDC以及输出控制的引脚 *********************/
#define AUXENIOP GPIO_PORT_2
#define AUXENIOG 2
#define AUXENIOx GPIO_PIN_6	//辅助6.0V使能输出(P2.6)


#define BOOSTRUNIOP GPIO_PORT_3
#define BOOSTRUNIOG 3
#define BOOSTRUNIOx GPIO_PIN_2	//主Boost运行使能输出(P3.2)


#define LEDNegMOSIOP GPIO_PORT_2
#define LEDNegMOSIOG 2
#define LEDNegMOSIOx GPIO_PIN_5		//LED负极MOSFET(P2.5)


/******************* 以下是负责CC/CV整定电压生成的PWMDAC的引脚 *********************/
#define PWMDACENIOP GPIO_PORT_2
#define PWMDACENIOG 2
#define PWMDACENIOx GPIO_PIN_3 	//恒流(CC)整定PWMDAC使能(P2.3)

#define PWMDACIOP GPIO_PORT_2
#define PWMDACIOG 2
#define PWMDACIOx GPIO_PIN_2		//恒流(CC)整定PWMDAC输出(P2.2)

#define PreChargeDACIOP GPIO_PORT_2
#define PreChargeDACIOG 0
#define PreChargeDACIOx GPIO_PIN_2		//恒压预充(CV)整定PWMDAC输出(P0.2)


/************************************************************************************
以下是系统的模拟输入引脚，包括电池电压测量、输出电压测量、运放恒流状态反馈、负责温度
测量的NTC输入以及NTC控制
************************************************************************************/
#define NTCInputIOG 0
#define NTCInputIOx GPIO_PIN_5 
#define NTCInputAIN 5						//NTC输入(P0.5,AN5)

#define VOUTFBIOP GPIO_PORT_3
#define VOUTFBIOG 3
#define VOUTFBIOx GPIO_PIN_1
#define VOUTFBAIN 13						//输出电压反馈引脚(P3.1,AN13)


#define OPFBIOG 0
#define OPFBIOx GPIO_PIN_1
#define OPFBAIN 1								//运放恒流状态反馈引脚(P0.1,AN1)

#define VBATInputIOP GPIO_PORT_3
#define VBATInputIOG 3
#define VBATInputIOx GPIO_PIN_0
#define VBATInputAIN 22					//电池电压检测引脚(P3.0,AN22)


#define NTCENIOP GPIO_PORT_0
#define NTCENIOG 0
#define NTCENIOx GPIO_PIN_3			//NTC检测使能引脚(P0.3)


/****************** 以下是负责按键小板部分的引脚(指示灯和按键) ********************/
#define SideKeyGPIOP GPIO_PORT_0
#define SideKeyGPIOG 0
#define SideKeyGPIOx GPIO_PIN_0		//侧按按键(P0.0)


#define RedLEDIOP GPIO_PORT_1
#define RedLEDIOG 1
#define RedLEDIOx GPIO_PIN_4		//红色指示灯(P1.4)	


#define GreenLEDIOP GPIO_PORT_1
#define GreenLEDIOG 1
#define GreenLEDIOx GPIO_PIN_3		//绿色指示灯(P1.3)



/********************* 以下是其他特殊功能的引脚或者保留引脚 ***********************/

#define SYSHBLEDIOP GPIO_PORT_0
#define SYSHBLEDIOG 0
#define SYSHBLEDIOx GPIO_PIN_4			//心跳LED(P0.4)






#endif /* PINDEFS */

/*************************  End Of File  ***********************/

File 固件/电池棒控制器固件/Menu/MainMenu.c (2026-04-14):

#include "IP2366_REG.h"
#include "GUI.h"
#include "Config.h"
#include "lcd.h"
#include "ADC.h"
#include "pic.h"
#include "Key.h"
#include <math.h>
#include "INA226.h"

//平均次数
#define SADCAvgCount 5
//内部变量
bool IsTelemOK=false;
IP2366VBUSStateDef VBUS;
BatteryStateDef BATT;
QuickChargeStateDef QCState=QuickCharge_None;
bool Is2366Telem=false;
extern short SleepTimer;
static bool ConnectState;
static float VBUSAvgBuf[4]={0};
static char VBusAvgCount=0;
bool IsCPortConnected; //C口输入是否连接
float VTypec=0,ITypeC=0,VBat=0,IBat=0;
bool IsResultUpdated=true;
RecvPDODef PDO=RecvPDO_None;
static char ChargerAltDisplayTIM=0;
char DisplayLoopCounter=0;	 //实现交替显示的处理
bool IsDispChargingINFO=false; //实现涓流恒流指示和充电字样交替显示
ChipStatDef CState;
static bool IsShowEff=false;

//和IP2366连接获取数据
void IP2366_Telem(void)
	{
	char i;
	float Result;
	extern bool IsEnableHPGauge;	
	INADoutSreDef VBUSData;
	//判断是否启用传输
	if(!Is2366Telem)return;
	IsTelemOK=IP2366_GetChargerState(&BATT);
	IsTelemOK&=IP2366_GetVBUSState(&VBUS);
	IsTelemOK&=IP2366_ReadChipState(&CState);
	IsTelemOK&=IP2366_GetRecvPDO(&PDO);
	
	IsCPortConnected=IP2366_GetIfCPortConnected();
		
	//开始进行INA226的测量	
	if(IsEnableHPGauge)
		{
		//尝试读取INA226进行高精度测量
		if(!INA226_GetBusInformation(&VBUSData))
			{
			//高精度测量失效，回到传统模式
			IsEnableHPGauge=false;
			}
		//高精度测量正常完成，直接使用INA226读回来的数据	
		else
			{		
			//对电流数据进行替换
			VBUS.VBUSCurrent=fabsf(VBUSData.BusCurrent); 
			if(BATT==Batt_discharging)VBUS.VBUSCurrent*=-1;	//电池处于放电状态，电流*-1表示正在放电		
			//对电压数据进行替换
			VBUS.VBUSVolt=(VBUS.VBUSCurrent*0.0027)+VBUSData.BusVolt; //补偿路径开关管的Rdson（实物中使用BSZ018N04，5V下加上Rdson和Rpcv大概是2.7mR）计算得出Typec位置的电压
			}
		}
	//测量成功结束开始累加
	if(IsTelemOK)
		{
		//交替显示充电状态	
		if(ChargerAltDisplayTIM>0)ChargerAltDisplayTIM--;
		else
			{
			if(DisplayLoopCounter<7)DisplayLoopCounter++;
			else DisplayLoopCounter=0;
			IsDispChargingINFO=IsDispChargingINFO?false:true;
			ChargerAltDisplayTIM=16;
			}
		//电压均衡
		if(VBusAvgCount<SADCAvgCount)
			{
			VBusAvgCount++;
			VBUSAvgBuf[2]+=ADCO.Vbatt;
			VBUSAvgBuf[3]+=ADCO.Ibatt;
			VBUSAvgBuf[0]+=VBUS.VBUSVolt;
			VBUSAvgBuf[1]+=VBUS.VBUSCurrent;
			}
		else
			{
			IsResultUpdated=true;
			VBusAvgCount=0;
			VBat=VBUSAvgBuf[2]/(float)SADCAvgCount;				
			IBat=VBUSAvgBuf[3]/(float)SADCAvgCount;
      //读取TypeC结果
			Result=VBUSAvgBuf[0]/(float)SADCAvgCount;
			Result*=(float)CfgData.TypeCVoltageCal;
			Result/=(float)1000;
			if(Result>4&&Result<30)VTypec=Result;
			//读取TypeC电流结果
			Result=VBUSAvgBuf[1]/(float)SADCAvgCount;
			if(BATT==Batt_discharging)Result*=(float)CfgData.TypeCAmpereCal;
			else Result*=(float)CfgData.TypeCAmpereCalCharge;
			Result/=(float)1000;
			if(fabsf(Result)<7.6)ITypeC=Result;
			//进行电池端电压补偿计算	
			if(VTypec<VBat)VBat+=(0.033*0.05); //当前Type-C没有连接，系统靠电池供电需要补偿的VBat保险电阻的压降（0.033A*0.05R）
			//读取结束，清除平均缓存结果	
			for(i=0;i<4;i++)VBUSAvgBuf[i]=0;
			}		
		if(VBUS.IsTypeCConnected)SleepTimer=480; //禁止睡眠
		}
	Is2366Telem=false;
	}

//计算效率并输出百分比
static float CalcEfficiency(void)	
	{
	float VBUSPower,VBatPower,eff;
	//芯片数据异常，显示不可用
	if(!IsTelemOK)return -1;
	//计算输入输出功率
	VBUSPower=fabsf(VTypec*ITypeC);
	VBatPower=fabsf(VBat*IBat);	
	//计算效率	
	switch(BATT)
		{
		case Batt_discharging:eff=VBUSPower/VBatPower;break; //反向放电时Eff=VBUS/Vbat
		case Batt_PreChage:
		case Batt_CCCharge:
		case Batt_CVCharge:eff=VBatPower/VBUSPower;break; //充电时Eff=Vbat/Vbus
		default:return -1; //其余情况效率不显示
		}
	//限幅数值并返回结果
	eff*=(float)100;
  if(eff>98)eff=98;
	if(eff<5)eff=5;
	return eff;
	}

//主菜单处理仅充电和其他状态的显示
static bool ProcessStorageChgOnlyDisplay(void)
	{
  extern bool IsEnableTempChargeOnly;
	//仅充模式启用
	if(IsEnableTempChargeOnly||!DCDCOutputBit)
		{	
		if(DisplayLoopCounter<4)return false; //非显示状态，正常显示
		switch(DisplayLoopCounter)
			{
			case 4:LCD_ShowChinese(86,61,"仅充\0",LIGHTBLUE,BLACK,0);break;
			case 5:LCD_ShowChinese(86,61,"模式\0",LIGHTBLUE,BLACK,0);break;
			case 6:LCD_ShowChinese(86,61,StorageMode!=StorageMode_OFF?"存储\0":"仅充\0",StorageMode!=StorageMode_OFF?ORANGE:LIGHTBLUE,BLACK,0);break;
			case 7:LCD_ShowChinese(86,61,"模式\0",StorageMode!=StorageMode_OFF?ORANGE:LIGHTBLUE,BLACK,0);break;
			}
		return true;
		}
	//存储模式启用
	else if(StorageMode!=StorageMode_OFF)
		{
		if(DisplayLoopCounter<4)return false; //非显示状态，正常显示
	  LCD_ShowChinese(86,61,DisplayLoopCounter<=5?"存储\0":"模式\0",ORANGE,BLACK,0);
		return true;
		}
	//其余状态返回false
	return false;
	}
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

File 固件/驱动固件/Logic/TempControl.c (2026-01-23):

/****************************************************************************/
/** \file TempControl.c
/** \Author redstoner_35
/** \Project Xtern Ripper Hyper Boost For GT96
/** \Description 这个文件为顶层应用层逻辑文件。负责实现系统的温度管理并在合适的
条件下限制输出功率以及强制关机，以保护系统免受过度高温影响。

**	
				2025年12月28日 12:42 1.新增在POWER模式下在电池即将耗尽，跳转到高亮继续
				                       运作前，逐步降低系统的外壳温度至高亮恒温值以避
															 切换到高亮后，系统瞬间因高温差大幅度降档导致亮
															 度瞬间跳楼一下影响用户使用体验。
														 2.修复积分器快速积分逻辑不正确，并且移除在温度误
														   差大于4度时快速升温的逻辑，以修复系统恒定亮度时
															 不稳定的问题。
														 3.针对主动散热DLC优化温控控制逻辑的参数，解决极亮
															 挡位下温度控制下冲严重的bug。
														 4.优化系统在挡位交接阶段重新计算电流值的配置使得
														   极亮在跳档至高亮时工作更稳定。
														 
				2025年12月26日 10:05 针对新的远光狗模式挡位调整温控计算暂停逻辑，以便于
														 优化系统逻辑。
														 
				2025年12月20日 Initial Release
**	
*****************************************************************************/
/****************************************************************************/
/*	include files
*****************************************************************************/
#include "ADCCfg.h"
#include "LEDMgmt.h"
#include "delay.h"
#include "ModeControl.h"
#include "TempControl.h"
#include "BattDisplay.h"
#include "OutputChannel.h"
#include "TurboICCMAX.h"
#include "PWMCfg.h"
#include "LowVoltProt.h"
#include "SelfTest.h"
#include "FastOp.h"

/****************************************************************************/
/*	Local pre-processor symbols/macros - for Parameter Definition
****************************************************************************/

//PI环参数和最小电流限制
#define ILEDRecoveryTime 90 //使用积分器缓慢升档的判断时长，如果积分器持续累加到这个时长，则执行一次调节(单位秒)
#define SlowStepDownTime 60 //使用积分器缓慢降档的判断时长，如果积分器持续累加到这个时长，则执行一次调节(单位秒)
#define IntegralCurrentTrimValue 2500 //积分器针对输出的电流修调的最大值(mA)
#define IntegralFactor 12 //积分系数(每单位=1/8秒，越大时间常数越高，6=每分钟进行40mA的调整)
#define ILEDStepDown 1500 //降档系统所能达到的最低电流(mA)
#define BatteryDynamicTurboDegFactor 20 //极亮模式下动态调节恒温温度实现无缝过渡的系数，单位(mV)系数越小，温度下降速度越快 

//常亮电流配置
#define ThermalFoldbackILEDDegVal 5700 //触发温度回折保护之后，降档系统立即减少的电流量(mA)
#define ILEDConstantGlowMin 8500 //降档系统内的低温温控的常亮电流设置(mA)
#define ILEDConstantGlowMinTurbo 11000 //降档系统内的极亮温控的常亮电流设置(mA)
#define ILEDConstantGlowMinECOTurbo 9000 //降档系统内的极亮温控（ECO模式）的常亮电流设置(mA)

//温度配置
#define ForceOffTemp 80 //过热关机温度
#define ForceDisableTurboTemp 65 //超过此温度无法进入极亮
#define TurboConstantTemperature 58 //极亮挡位的PID维持温度
#define ECOTurboConstantTemperature 52 //ECO模式下极亮挡位的PID维持温度
#define ConstantTemperature 50 //非极亮挡位温控启动后维持的温度
#define ReleaseTemperature 43 //温控释放的温度

/****************************************************************************/
/*	Local pre-processor symbols/macros for Parameter Processing and Checking
****************************************************************************/ 
#define MinumumILED CalcIREFValue(ILEDStepDown)		//最小LED电流计算
#define LeaveTurboTemperature ForceOffTemp-10   	//退出极亮温度计算
#define TurboTempDegEndTemp (ConstantTemperature+2)                  //计算极亮接近退出的温度
#define TurboVoltDeg (TurboConstantTemperature-TurboTempDegEndTemp)  //计算极亮到常亮的温度差
#define TurboTempDegEnd TurboOFFVoltage+(BatteryDynamicTurboDegFactor*TurboVoltDeg) //极亮不衰减性能的电池电压

/*   积分器满量程自动定义，切勿修改！    */
#define IntegrateFullScale IntegralCurrentTrimValue*IntegralFactor

#if (IntegrateFullScale > 32760)

#error "Error 001:Invalid Integral Configuration,Trim Value or time-factor out of range!"

#endif

#if (IntegrateFullScale <= 0)

#error "Error 002:Invalid Integral Configuration,Trim Value or time-factor must not be zero or less than zero!"

#endif

/*	温控数值监测，切勿修改！    	*/
#if (ForceOffTemp > 85)
#error "Error 003:Emergency Shutdown Temperature must not exceeded 85 Celsius!"
#endif

#if ((ForceOffTemp-15) < ForceDisableTurboTemp)
#error "Error 004:Force Disble Turbo Temperature must less than Emergency Shutdown Temperature for at least 15 Celsius!"
#endif

#if (ForceOffTemp < (TurboConstantTemperature+8))
#error "Error 005:Force Disble Turbo Temperature must higher than Constant Temperature of Turbo Mode for at least 8 Celsius!"
#endif

#if (TurboConstantTemperature <= ConstantTemperature)
#error "Error 006:Constant Temperature of Turbo Mode must lagger than Constant Temperature of other mode!"
#endif

#if (ConstantTemperature < (ReleaseTemperature+5))
#error "Error 007:Constant Temperature of other mode must lagger than Thermal Control Release Temp for 5 Celsius!"
#endif

#if (ReleaseTemperature < 38)
#error "Error 008:Thermal Control Release Temp is too low and will not release at summer!"
#elif (ReleaseTemperature < 41)
#warning "Warning 001:Thermal Control Release Temp is too low and might not be able to release at summer."
#endif

/****************************************************************************/
/*	Local variable and Flag definitions('static')
****************************************************************************/
static xdata int TempIntegral;
static xdata int TempProtBuf;
static xdata unsigned char StepDownTIM;  //降档显示计时
static xdata unsigned char StepUpLockTIM; //计时器

static bit IsNearThermalFoldBack; //标记位，是否接近于退出极亮温度
static bit IsThermalStepDown; //标记位，是否降档
static bit IsTempLIMActive;  //温控是否已经启动
static bit IsSystemShutDown; //是否触发温控强制关机

/****************************************************************************/
/*	Global variable definitions(declared in header file with 'extern')
****************************************************************************/
bit IsDisableTurbo;  //禁止再度进入到极亮档
bit IsForceLeaveTurbo; //是否强制离开极亮档
bit IsPauseThermalCalc=0; //是否暂停温控计算

/****************************************************************************/
/*	Function implementation - local('static')
****************************************************************************/

//负责温度使能控制的施密特触发实现函数（滞回控制）
static bit TempSchmittTrigger(bit ValueIN,char HighThreshold,char LowThreshold)	
	{
	if(Data.Systemp>HighThreshold)return 1;
	if(Data.Systemp<LowThreshold)return 0;
	//数值保持，没有改变
	return ValueIN;
	}

//获取温控环路的恒温值
static int QueryConstantTemp(void)	
	{
	int Buf;
	if(CurrentMode->ModeIdx==Mode_Turbo)
		{
		//POWER模式下极亮的时候使用更高的温控拉长降档时间
		if(IsPowerModeEnabled)
			{
			//Power模式下为了实现和高亮挡位的温度无缝过渡，在电池电压接近极亮关断电压时，逐步降档
		  if(CellVoltage>=TurboTempDegEnd)Buf=TurboConstantTemperature;
		  else
				{
				//降档温度按照极亮关闭电压往上**mV（由温控参数定义）每℃的斜率，逐步从高温过渡到低温
				Buf=(CellVoltage-TurboOFFVoltage)/BatteryDynamicTurboDegFactor;
				if(IsNegative16(Buf))Buf=0;
				Buf+=TurboTempDegEndTemp;
				}
			return Buf;
			}
		//ECO模式使用52度温控
		else return ECOTurboConstantTemperature;
		}
	//正常使用其余挡位的温控
  return ConstantTemperature;
	}
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

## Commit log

2025-05-15 ### 固件更新
    + 修改极亮时自动适配低性能电池的输入MPPT系统逻辑。
    + 修改电量指示灯状态机的电压转换点，解决电池电量提示过早和实际可用续航不匹配的问题
    + 将温控系统的温度阈值提高3℃，延长极亮时间。
    + 固件时间戳由20250501调整为20250515（固件编译日期）
    ### 烧录文件更新
    + 更新固件批量烧录文件同步到源代码对应的最新固件和时间戳（0515）
    + 固件源码文件夹内新增预编译好的固件文件（Binary文件夹内）可直接烧录使用。
    ### 制造文件更新
    + 更新手电本体五金外壳料的制造文件和部分说明文档
    + 更新驱动板散热铜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
    [BattVoltDisplay.obj, LowVoltageProt.obj, ModeControl.obj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]
2025-05-17 V1.1版本更新
    驱动固件部分
    1:修正驱动低电量保护逻辑不能正确关机导致直接用光所有电量到保护板断电的bug
    2:修正驱动输入MPPT逻辑工作异常的bug
    3:修复驱动在极亮降档且低电量的时候电量指示灯错误报告电池过载异常的bug
    4:更新固件时间戳至20250517
    电池棒控制器固件部分
    1:新增对Type-C输入电流测量进行修调以及设置Type-C状态显示的数据来源的功能。
    2:配合电源管理SoC进行固件回退操作，修改SoC对应的时间戳监测部分
    3:对IP2366的定制固件进行版本回退，回退至上一版本
    硬件部分
    1:修正充电板部分元器件的数值错误
    2:新增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
    [BattVoltDisplay.obj, LEDMgmt.obj, LocateLED.obj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]
2025-05-18 V1.2版本更新
    --- 驱动固件更新 ---
    1.修复在无极调光模式下，长按切换三个特殊功能挡位失败的问题。
    2.对温控系统进行重构彻底解决温控不稳定，极亮时温控过调导致亮度跳楼式下跌的问题
    3.驱动固件时间戳更新至20250518
    --- 电池棒控制器固件更新 ---
    1.一键测容菜单下新增显示系统充电状态的条目
    2.更新已经编译好,可直接烧录的hex文件。
    --- 其余更新 ---
    1.移除工程目录中的编译缓存等无用数据
    2.更新工程批量烧录设置
    [ADCCfg.obj, BattVoltDisplay.obj, Beacon.obj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]
2025-05-22 驱动固件更新
    1.解决输入自适应MPPT部分对于电池压降的检测异常导致错误的降功率
    2.修复当驱动自动关机后即使电池充满电，电量数据在首次开机时未更新导致无法正常开机的问题
    3.将输入自适应的电池动态压降阈值改为使用宏定义，方便修改
    4.删除掉无用的listing文件
    烧录文件更新
    1.更新驱动固件时间戳至20250521。
    2.更新批量烧录文件至最新固件（时间戳20250521）
    自述文件更新
    1.修复自述文件中图片无法正确显示的bug
    2.更新实测的续航曲线数据
    [main.c]
2025-06-06 驱动固件更新
    1.新增一个2LM的超级省电应急月光档
    2.移除操作较为不便且较少使用的系统重置功能（上电时按住按钮恢复出厂设置）
    3.重写LED管理器代码优化空间占用
    4.修改输出通道状态机跳转至软关机阶段的逻辑为表驱动，节约空间
    5.将驱动输出电流降低至33A/30A解决FV7212D灯珠被过度驱动以及7175灯珠下输入电流卡限制的问题
    其余更新
    1.机械部分Readme增加密封圈尺寸的记录
    2.驱动PCB的Readme增加新增的超级省电挡位的操作说明
    3.更新驱动固件和批量烧录设置时间戳至20250606
2025-06-06 其余更新
    1.删除掉驱动PCBA内无用的文件
    2.修复部分Readme中图片无法查看的问题
2025-06-09 驱动固件更新
    1.修复电池电量低于10V的时候查询电压功能异常的bug
    2.彻底修复1LM挡位时电量查询功能无法显示当前电池的电量水平的bug
    3.修复1LM挡位时侧按指示灯定时闪烁提示电量功能失效的bug
    4.更新批量烧录设置和ROM镜像至最新时间戳（20250609）
    5.新增在电池电量低于10V时启用的高精度电压查询功能（精确到0.01V）
    硬件更新
    1.新增电池子系统控制/监视模块（CMS）的PCB制版文件和原理图等制造数据
    2.修改电池子系统充电板的电流检测电阻阻值为1.5mR，提高检测精度
    电池棒控制器固件更新
    1.调整电池棒控制器固件内电流检测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
    [BOM.xlsx, CMSPanel.PrjPcb, main.SchDoc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]
2025-07-03 V1.1.0.0固件更新，详情请查看changelog
    [PCB2.PcbDoc, main.SchDoc, 专用定位片-7070灯珠.3mf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]
2025-07-06 1.1.0.1版本更新，详情请查看changelog.md
2025-07-08 V1.1.0.2版本更新，详情请查看changelog.md
2025-07-10 V1.1.0.3版本更新，详情请查看changelog
    [IP2366_I2C_140W_2M50_REG.xlsx]
2025-07-18 V1.2.0.0版本更新，详情请查看ChangeLog
    [IP2366_I2C_140W_2M50_REG.xlsx, TempTest.xlsx]
2025-07-19 V1.2.0.1版本更新，详情请查看ChangeLog
    [PCB3.PcbDoc, main.SchDoc, 电池架均衡和充电板空隙垫圈.SLDPRT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]
2025-07-21 V1.2.0.2版本更新，详情请查看changelog
2025-07-23 V1.2.0.3版本更新，详情请查看changelog
    [TempTest.xlsx]
2025-07-28 V1.2.0.4非兼容版本更新，请务必查看ChangeLog！
    [BOM.xlsx, CMSPanel.PrjPcb, main.SchDoc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]
2025-08-05 V1.2e.0.0实验性分支版本更新，功能未验证，具体更新内容请查看changelog
    [PCB2.PcbDoc, main.SchDoc, 专用定位片-FL7018I-ES-PA6GF.SLDPRT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]
2025-08-07 V1.2e.0.1实验性版本更新，功能未验证，详情请查看readme
    [PCB2.PcbDoc]
2025-08-18 V1.2e.0.2 实验性功能分支更新。详细更改请查看changelog
    [40风扇不锈钢夹片-改版.STEP, 40风扇不锈钢夹片.SLDPRT, 40风扇不锈钢夹片.STEP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]
2025-09-19 V1.2e.0.4实验性版本更新，功能未完全验证，请务必查看changelog！
    [GT96 Logo.DXF, GT96 Logo.SLDPRT, IP2366_I2C_140W_2M50_REG.xlsx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]
2025-10-23 V1.2e.0.5实验性分支版本更新，功能暂未完全测试，详情请查看changelog
    [电池正极铜垫片.SLDPRT, 电池正极铜垫片.STEP]
2025-11-03 V1.3.0.0版本更新，该版本即将合并入主分支内。更改详情请查看changelog
    [PCB1.PcbDoc, main.SchDoc, 充电板负极保险模块.PrjPcb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]
2025-11-04 V1.3.0.1版本更新，详情请查看changelog
2025-11-14 V1.3.0.2版本更新，详情请查看changelog
    [6S1P-3V-N160铝.PcbDoc, 6S1P-3V.PcbDoc, 专用定位片-7070-尺寸精调.SLDPRT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]
2025-12-09 V1.3.0.3版本更新，修正若干问题，详情请查看changelog
    [6S1P-3V.PcbDoc, 驱动压环.prt, 驱动压环.stp]
2025-12-17 V1.3.0.4版本更新，详情请查看changelog
    [6S1P-3V.PcbDoc, GT96专用风扇手柄固定块.SLDDRW, GT96专用风扇手柄固定块.SLDPRT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]
2025-12-21 V1.3.0.5版本更新，对驱动固件进行大幅度重构，详情请查看readme
2025-12-26 V1.3.0.6版本更新，对驱动固件进行调整，详情请查看changelog
    [续航测试减光器.SLDPRT]
2026-01-01 V1.3.0.7版本更新，对驱动固件进行微调，详情请查看changelog
    [电池仓正极侧保护盖.stp]
2026-01-23 V1.3.0.8版本更新，详情请查看changelog
    [GT96专用风扇手柄固定块.SLDDRW, GT96专用风扇手柄固定块.SLDPRT, GT96专用风扇手柄固定块.STEP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]
2026-01-30 V1.3.0.9版本更新，详情请查看changelog
    [GT96 Logo.SLDPRT, GT96铭牌.DXF, 尾盖标识.DXF]
2026-04-14 V1.3.0.10版本更新，详细信息请查看changelog
    [风扇手柄驱动.PrjPcb]
